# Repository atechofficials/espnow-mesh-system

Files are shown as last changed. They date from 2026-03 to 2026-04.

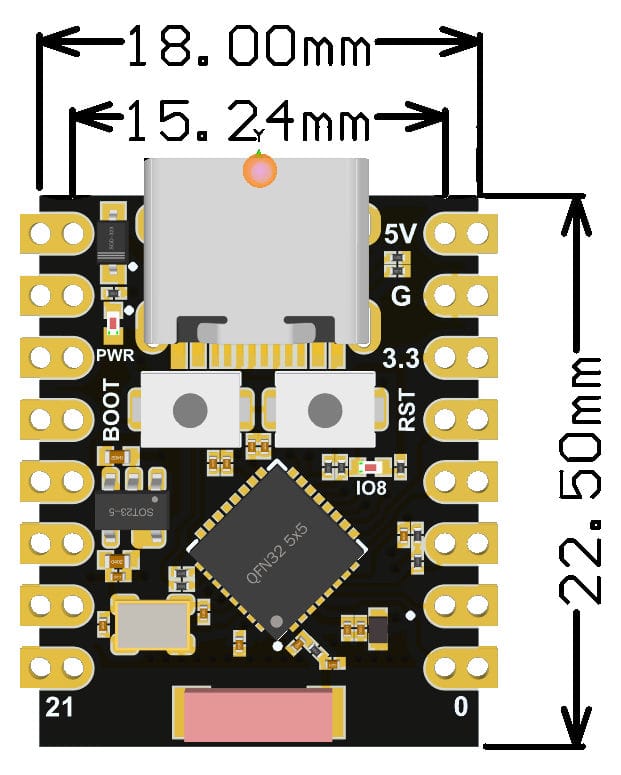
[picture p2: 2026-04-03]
esp32-gateway/gateway_v1/hardware/Development_Resources/esp32-c3/esp32_c3_supermini/ESP32-C3-SuperMini-Dim.jpg

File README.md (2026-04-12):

# ESPNow Mesh System

A local-first ESP32 smart-home system for **wireless sensing and control**.

This project lets you build a small home mesh using **ESP32-based nodes** and a central **ESP32-S3 gateway**.  
The gateway connects to your Wi-Fi, hosts a browser-based dashboard, can optionally expose its own built-in **SPI room sensor with runtime BMP280/BME280 auto-detection**, communicates with nearby nodes over **ESP-NOW**, can fall back to its own **Offline Mode AP** when your router is unavailable, optionally bridges the system to a local **MQTT broker**, publishes **Home Assistant MQTT auto-discovery**, and uses a companion **ESP32-C3 coprocessor** to handle **gateway-managed Node OTA updates** and future helper tasks.

That means you can:

- monitor room conditions like temperature, humidity, pressure, and light
- use the gateway by itself with an optional built-in room sensor before you add wireless nodes
- control actuator devices like relays from a web dashboard
- mirror supported devices and controls into Home Assistant through MQTT auto-discovery
- pair nodes without entering Wi-Fi credentials on each node
- keep everything running on your own local network

No cloud account. No subscription. No internet dependency for normal use.

---

## What This Project Can Do

### Live monitoring
Open the gateway's IP address in your browser to view live sensor readings from all paired nodes.

### Local control
Turn relays on and off directly from the dashboard.

### Easy pairing
Put a node into pairing mode and the gateway can discover and register it automatically. Fresh, unrenamed nodes now advertise with the last 4 characters of their MAC address appended to the default node name, making it easier to tell identical boards apart before you rename them from the dashboard. The current release line also tightens beacon/discovery timing so pairing candidates appear faster and stale "available to pair" entries clear sooner after a node powers down.

### Node settings from the browser
Change node settings such as:
- Status LED enable/disable
- Relay state persistence
- Sensor-specific options

### Gateway-managed Node OTA
Upload compatible sensor-node, actuator-node, or hybrid-node firmware from the gateway web interface and let the gateway update the selected node without connecting that node to your home Wi-Fi. The gateway now validates both the node role and the node hardware configuration ID before delivery begins.

### Offline gateway access
If your router is unavailable, the gateway can now switch to an **ESP32-S3-hosted Offline Mode AP** so the dashboard stays reachable without internet or home-network access. You can also choose manual offline mode during setup and edit the offline AP credentials later from the dashboard.

### MQTT and Home Assistant
If you enable MQTT in the gateway settings, the gateway publishes **Home Assistant MQTT discovery** for itself, its optional built-in sensor, and supported paired nodes. Relay controls, supported node settings, reboot/unpair actions, and gateway reboot/factory-reset actions can then be used from Home Assistant while staying synchronized with the gateway dashboard.

For temperature reporting, the gateway publishes MQTT temperatures in **degrees Celsius only** for both the built-in sensor and paired sensor nodes. Temperature-unit controls are intentionally **not** exposed to Home Assistant because Home Assistant already handles user-side Celsius/Fahrenheit conversion.

### Automatic recovery
If the gateway or node reboots, the system reconnects automatically and restores state where supported.

---

## Current Project Status

The project already supports **sensor nodes**, **actuator nodes**, and **hybrid nodes**.

### Available right now

| Type | Device | Status |
|---|---|---|
| Gateway | ESP32-S3 Gateway | Working |
| Gateway Helper | ESP32-C3 Coprocessor | Working |
| Sensor Node | Envo Mini v1 | Working |
| Actuator Node | ESP32 Relay Node v1 | Working |
| Hybrid Node | ESP32 Hybrid Relay Node v1 | Working |

### Current node capabilities

**Envo Mini v1**
- Temperature
- Atmospheric pressure
- Humidity
- Ambient light

**ESP32 Relay Node v1**
- 4 independent relay outputs
- Relay control from dashboard
- Relay state persistence across reboot
- Status LED setting from dashboard

**ESP32 Hybrid Relay Node v1**
- 4 independent relay outputs
- 4 TTP224 touch inputs
- RC522 RFID card reader support
- RFID card actions that apply saved relay scenes
- Relay control, state sync, and RFID management from the dashboard

### Current MQTT capabilities

- Local MQTT bridge from the gateway to a Mosquitto-compatible broker
- Home Assistant MQTT auto-discovery for:
  - the gateway device
  - optional gateway built-in sensor entities
  - supported sensor, actuator, and hybrid node entities
- Relay and supported setting control from Home Assistant with state sync back to the gateway dashboard
- Gateway reboot and gateway factory reset buttons exposed in Home Assistant
- Graceful retained-topic cleanup during gateway factory reset so the gateway and its connected nodes disappear from Home Assistant cleanly

### Current OTA capabilities

- Gateway self-OTA from the browser with gateway hardware-config ID validation
- Gateway-managed coprocessor OTA from the browser with board-specific coprocessor hardware-config ID validation and progress/error reporting
- Gateway-managed OTA for supported sensor nodes with role and hardware-config ID validation
- Gateway-managed OTA for supported actuator nodes with role and hardware-config ID validation
- Gateway OTA and Node OTA now coordinate helper ownership so the ESP32-C3 coprocessor cannot be reserved by conflicting update flows at the same time
- Gateway self-OTA, coprocessor OTA, and Node OTA remain available while the dashboard is being served through the Offline Mode AP

---

## Why ESP-NOW?

Most DIY smart-home systems put every device directly on Wi-Fi.

This project takes a different approach:

- the **gateway** joins your home Wi-Fi
- the **nodes** talk to the gateway using **ESP-NOW**
- nodes do not need your Wi-Fi password
- pairing is simpler for small embedded devices
- the system stays lightweight and local

This makes the setup especially useful for small ESP32 devices that only need to talk to one central controller.

---

## How It Works

```text
Browser
  |
  | Dashboard
  |
ESP32-S3 Gateway
  |
  | ESP-NOW
  |-- Sensor Nodes
  |-- Actuator Nodes
```

The gateway acts as the bridge between:
- your browser over Wi-Fi
- your MQTT broker / Home Assistant over Wi-Fi
- your ESP32 nodes over ESP-NOW

For **Node OTA**, the gateway temporarily hands firmware delivery to the on-board **ESP32-C3 coprocessor**, which stages the selected node firmware, starts a temporary helper access point, and serves the firmware image to the target node while the main gateway continues managing the mesh and dashboard. Incompatible uploads are blocked up front if the firmware markers do not match the selected node role or hardware configuration. While that helper session is active, the dashboard now blocks conflicting Gateway OTA or coprocessor OTA actions and shows a clear **Coprocessor Busy** state until the helper is free again.

If the gateway loses its router Wi-Fi connection, the **ESP32-S3** can now host an operator-facing Offline Mode AP directly while keeping ESP-NOW active on the last known mesh channel. When the router comes back, the gateway scans for the saved SSID, reconnects automatically, and returns the dashboard to the router-assigned IP.

---

## Hardware Used

### Gateway firmware targets
- ESP32-S3-DevKitC-1-N8R8 for bench development and validation
- Seeed Studio XIAO ESP32-S3 on the new THT gateway carrier variants
- Waveshare ESP32-S3-DevKit-C-N8R8 on the new THT gateway carrier variants

### Gateway helper targets
- ESP32-C3 Super Mini
- Seeed Studio XIAO ESP32-C3
- DFRobot Beetle ESP32-C3

### Gateway reference PCB variants

The current gateway hardware release line now consists of four single-layer, thick-trace, THT-friendly PCB variants intended to be easy to hand-fabricate at home:

| Variant | Main MCU board | Helper MCU board |
|---|---|---|
| `ESP32_Mesh_Gateway_v1A` | Seeed Studio XIAO ESP32-S3 | ESP32-C3 Super Mini |
| `ESP32_Mesh_Gateway_v1B` | Seeed Studio XIAO ESP32-S3 | Seeed Studio XIAO ESP32-C3 |
| `ESP32_Mesh_Gateway_v1C` | Seeed Studio XIAO ESP32-S3 | DFRobot Beetle ESP32-C3 |
| `ESP32_Mesh_Gateway_v1D` | Waveshare ESP32-S3-DevKit-C-N8R8 | ESP32-C3 Super Mini |

Shared board-level notes for all four variants:
- All four variants provide solder pads for an optional built-in **BMP280** or **BME280** gateway room sensor module, and the gateway auto-detects which one is attached at boot
- All four variants are intentionally kept on a single copper layer with thick traces for easier home fabrication
- The earlier ESP32-S3 Super Mini based gateway carrier should now be considered deprecated because that board's 4 MB flash is not suitable for the current gateway firmware line, which expects an 8 MB class ESP32-S3 target

### Sensor node reference boards
- DFRobot FireBeetle 2 ESP32-E
- ESP32-C3 Super Mini based **Envo Mini v1** prototype hardware

### Sensor node reference sensors
- BMP280
- DHT22
- TEMT6000

### Actuator node reference board
- ESP32 Dev Module

### Actuator node reference output
- 4-channel active-LOW relay module

### Hybrid node reference add-ons
- TTP224 4-way touch sensor
- RC522 RFID reader module

---

## Quick Start

Board and wiring selection for the current release line are handled through the documented **PlatformIO environments** for each firmware target, with guarded defaults and invalid-define correction in each project's `include/user_config.h`.

### 1. Flash the gateway
Start with the gateway firmware:

[`esp32-gateway/gateway_v1/README.md`](esp32-gateway/gateway_v1/README.md)

For **Node OTA** support, also flash the ESP32-C3 gateway coprocessor once from:

[`esp32-gateway/gateway_v1/coprocessor_esp32c3/`](esp32-gateway/gateway_v1/coprocessor_esp32c3/)

The **Gateway Firmware Update** section in the dashboard can now target either the ESP32-S3 **Main MCU** or the ESP32-C3 **Coprocessor**.

### 2. Flash a node
Choose one:

Sensor node:
[`esp32-nodes/sensor_nodes/envo_mini_v1/README.md`](esp32-nodes/sensor_nodes/envo_mini_v1/README.md)

Actuator node:
[`esp32-nodes/actuator_nodes/esp32_relay_node_v1/README.md`](esp32-nodes/actuator_nodes/esp32_relay_node_v1/README.md)

Hybrid node:
[`esp32-nodes/hybrid_nodes/esp32_hybrid_relay_node_v1/README.md`](esp32-nodes/hybrid_nodes/esp32_hybrid_relay_node_v1/README.md)

### 3. Power on the gateway
On first boot, the gateway opens the setup portal so you can either connect it to your home Wi-Fi or choose manual offline mode with the built-in Offline Mode AP credentials.

### 4. Pair a node
Put a node into pairing mode and let the gateway detect it.

### 5. Open the dashboard
Visit the gateway IP in your browser and start using the system. If the gateway is running in Offline Mode, open:

```text
http://192.168.8.1/
```

### 6. Optional: enable MQTT
If you want Home Assistant integration, open the gateway dashboard, go to the MQTT settings section, enter your broker details, and enable the MQTT bridge. The gateway will publish Home Assistant discovery automatically once it connects to the broker.

---

## Web Dashboard Features

The current dashboard supports:

- viewing all paired nodes
- seeing live sensor readings
- viewing the optional gateway built-in sensor separately from paired-node cards
- controlling relay outputs
- managing Hybrid-node RFID card actions
- opening node settings
- renaming nodes
- rebooting nodes remotely
- updating supported nodes with Node OTA
- updating the gateway main MCU or the ESP32-C3 coprocessor from the **Gateway Firmware Update** section
- disconnecting nodes
- changing gateway settings
- editing built-in gateway sensor temperature-unit / altitude settings when that feature is enabled
- configuring the MQTT bridge and Home Assistant discovery publishing
- editing Offline Mode AP settings and viewing current network mode / access IP
- launching Wi-Fi setup mode
- factory reset options, including a physical long-press reset button on the gateway and graceful node unpairing before the gateway wipes its own state

Home Assistant intentionally does **not** expose:
- relay label settings for actuator or hybrid nodes, because Home Assistant already lets users rename switches and buttons locally
- node or gateway temperature-unit settings, because MQTT temperatures are published in Celsius and Home Assistant handles conversion itself

The dashboard is served directly by the gateway itself.

---

## Who This Project Is For

This project is useful if you are:

### A maker or hobbyist
You want a local smart-home system without cloud dependency.

### A student or learner
You want to explore ESP32 networking, embedded firmware, and browser-based control panels.

### A developer
You want a modular ESP32 project with:
- gateway firmware
- sensor firmware
- actuator firmware
- hybrid node firmware
- a shared protocol
- a live dashboard
- room for future expansion

---

## For Developers

The project is already structured for further development.

If you want to:
- add new sensor nodes
- add new actuator nodes
- add new hybrid nodes
- improve the gateway
- improve the dashboard
- extend the protocol
- contribute fixes or new features

start here:

[`CONTRIBUTING.md`](CONTRIBUTING.md)

More detailed documentation is available in the subproject README files.

---

## Repository Layout

```text
espnow-mesh-system/
|-- README.md
|-- CONTRIBUTING.md
|-- esp32-gateway/
|-- esp32-nodes/
|-- docs/
```

### Main sections

- [`esp32-gateway/`](esp32-gateway/)  
  Gateway documentation and firmware
- [`esp32-gateway/gateway_v1/hardware/`](esp32-gateway/gateway_v1/hardware/)  
  Gateway v1A-v1D PCB resources, schematic PDFs, and development references

- [`esp32-nodes/`](esp32-nodes/)  
  Sensor, actuator, and hybrid node firmware

---

## Documentation Map

If you're just exploring:

- Gateway overview: [`esp32-gateway/README.md`](esp32-gateway/README.md)
- Nodes overview: [`esp32-nodes/README.md`](esp32-nodes/README.md)

If you're building hardware:

- Gateway firmware guide: [`esp32-gateway/gateway_v1/README.md`](esp32-gateway/gateway_v1/README.md)
- Gateway v1A-v1D PCB resources: [`esp32-gateway/gateway_v1/hardware/`](esp32-gateway/gateway_v1/hardware/)
- Sensor node guide: [`esp32-nodes/sensor_nodes/envo_mini_v1/README.md`](esp32-nodes/sensor_nodes/envo_mini_v1/README.md)
- Relay node guide: [`esp32-nodes/actuator_nodes/esp32_relay_node_v1/README.md`](esp32-nodes/actuator_nodes/esp32_relay_node_v1/README.md)
- Hybrid node guide: [`esp32-nodes/hybrid_nodes/esp32_hybrid_relay_node_v1/README.md`](esp32-nodes/hybrid_nodes/esp32_hybrid_relay_node_v1/README.md)
- ESP32-C3 Super Mini WiFi test report: [`docs/esp32_c3_supermini_wifi_tests/README.md`](docs/esp32_c3_supermini_wifi_tests/README.md)

If you're contributing code:

- Contribution guide: [`CONTRIBUTING.md`](CONTRIBUTING.md)

---

## Project Direction

The project currently supports:
- local sensor monitoring
- local relay control
- local RFID-driven relay scenes on Hybrid nodes
- browser-based node management
- gateway-managed Node OTA for supported sensor, actuator, and hybrid nodes with role and hardware-config safety checks
- board-specific configuration cleanup through the new `user_config.h` release line for gateway and node firmware
- ESP32-C3 Super Mini board support with board-gated WiFi transmit power limiting on node firmware where needed

Planned future growth may include:
- more sensor node types
- more actuator node types
- more hybrid sensor + actuator nodes
- improved dashboard views and charts
- cleaner onboarding and flashing experience

---

## License

MIT License

See [`LICENSE`](LICENSE)

---

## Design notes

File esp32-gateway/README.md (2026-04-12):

# ESP32 Gateway

The gateway is the heart of the ESPNow Mesh System. It runs on an **ESP32-S3** and bridges your Wi-Fi network with the ESP-NOW mesh while serving a live web dashboard, managing paired nodes, optionally exposing a built-in **SPI room sensor with runtime BMP280/BME280 auto-detection**, supporting a local **MQTT bridge** with **Home Assistant MQTT auto-discovery**, supporting **web-based gateway OTA firmware updates**, coordinating **gateway-managed Node OTA updates** for sensor, actuator, and hybrid nodes with a companion **ESP32-C3 coprocessor**, and providing an **Offline Mode AP** so the dashboard stays reachable even when your home router is unavailable.

---

## Hardware

| Item | Detail |
|---|---|
| Main Board | ESP32-S3-DevKitC-1-N8R8 |
| Companion Helper | ESP32-C3 coprocessor for Node OTA and future helper tasks |
| Flash | 8 MB (Quad) |
| PSRAM | 8 MB (Octal) |
| Status LED | WS2812B on GPIO 38 (on-board) |
| Factory reset button | Board-dependent and configured by `RESET_BTN_PIN` in `gateway_v1/include/user_config.h` |

The current gateway hardware release line now tracks four single-layer, thick-trace, THT-friendly PCB variants under `gateway_v1/hardware/`:

| Variant | Main MCU board | Helper MCU board |
|---|---|---|
| `ESP32_Mesh_Gateway_v1A` | Seeed Studio XIAO ESP32-S3 | ESP32-C3 Super Mini |
| `ESP32_Mesh_Gateway_v1B` | Seeed Studio XIAO ESP32-S3 | Seeed Studio XIAO ESP32-C3 |
| `ESP32_Mesh_Gateway_v1C` | Seeed Studio XIAO ESP32-S3 | DFRobot Beetle ESP32-C3 |
| `ESP32_Mesh_Gateway_v1D` | Waveshare ESP32-S3-DevKit-C-N8R8 | ESP32-C3 Super Mini |

All four variants include solder pads for an optional built-in **BMP280** or **BME280** gateway-side room sensor, and the gateway now auto-detects the attached sensor model at runtime. The older ESP32-S3 Super Mini based carrier should now be treated as deprecated because the current gateway firmware line expects an 8 MB class ESP32-S3 target.

---

## Responsibilities

- Connects to your home Wi-Fi using a captive portal (WiFiManager) on first boot or when reconfigured
- Can also run in an **ESP32-S3-hosted Offline Mode AP** with separate offline AP credentials
- Automatically falls back to the Offline Mode AP when the router Wi-Fi link is lost and returns to router mode when the saved router SSID is visible again
- Accepts ESP-NOW registrations from nodes and assigns them IDs
- Receives sensor data, heartbeats, and actuator states from paired nodes
- Optionally probes a gateway-side BMP280/BME280 room sensor over SPI, logs clearer detection diagnostics, auto-detects the sensor model at runtime, and exposes it as a dedicated dashboard card instead of a paired node
- Persists built-in sensor display settings such as temperature unit and altitude reference for sea-level pressure calculation
- Publishes optional MQTT discovery/state topics for the gateway, built-in sensor, and supported paired nodes
- Routes supported Home Assistant / MQTT commands back into the same gateway and node control flow used by the dashboard
- Publishes MQTT temperature data in degrees Celsius for Home Assistant and leaves unit conversion to Home Assistant itself
- Forwards dashboard commands to the correct node (pair, unpair, reboot, actuator toggle, settings change)
- Serves the web dashboard from LittleFS over HTTP/WebSocket
- Stores gateway configuration, web credentials, paired node records, node hardware-config IDs, and relay label assignments in NVS
- Supports **gateway self-OTA** from the web interface with validation, hardware-config ID checking, progress reporting, and automatic reboot
- Coordinates **Gateway OTA**, **coprocessor OTA**, and **Node OTA** so the ESP32-C3 helper cannot be reserved by conflicting update flows at the same time
- Keeps **gateway OTA**, **coprocessor OTA**, and **Node OTA** available while the gateway is serving the dashboard through Offline Mode
- Supports both dashboard-triggered and physical-button-triggered factory reset flows, including graceful node unpairing before reset, and LED feedback during the hold sequence
- Supports **Hybrid nodes** with capability-aware state handling, actuator-schema sync, RFID config sync, and RFID scan-event forwarding to the web UI

---

## LED Status Codes

| Colour / Pattern | Meaning |
|---|---|
| Solid white | Boot sequence in progress |
| Dim blue | Gateway operational |
| Green flash | Activity / success pulse |
| Orange flash | Node disconnect feedback |
| Dark-orange blink | Physical factory reset button is being held |
| Solid red | Factory reset hold threshold reached; reset is being confirmed |
| Off | Gateway LED disabled from the web UI |

The factory-reset LED sequence temporarily overrides the normal gateway LED owner and still appears even if the user has disabled the status LED from the web dashboard.

---

## Firmware Changelog

| Version | Notes |
|---|---|
| v1.6.0 | Added per-node dynamic settings, remote reboot support, gateway network config from dashboard, and factory reset support |
| v1.7.1 | Maintenance release with minor bug fixes |
| v1.8.0 | Added schema-driven sensor support, generic sensor reading protocol, and multi-sensor node compatibility |
| v1.8.1 | Added gateway status LED toggle support from the web UI with persistent state |
| v1.8.2 | Added ESP32 actuator-node support and improved actuator pairing/state/settings sync |
| v1.8.3 | Added per-relay label assignment from the web interface for relay nodes |
| v1.9.0 | Added **web-based gateway OTA firmware update**, OTA partition layout, upload validation, progress/error feedback, and automatic reboot after successful flash |
| v2.0.0 | Added **gateway-managed Node OTA** for supported sensor and actuator nodes, introduced the ESP32-C3 gateway coprocessor workflow, added helper-assisted node firmware staging/delivery, and extended OTA progress/reconnect tracking in the dashboard |
| v2.0.1 | Added OTA **hardware configuration ID** checks for both gateway OTA and node OTA, persisted node hardware IDs across gateway reboot, and improved OTA mismatch/error reporting in the serial logs and web UI |
| v2.1.0 | Added first-class **Hybrid node** support, introduced the RFID-enabled Hybrid Relay Node flow, added capability-aware actuator/RFID handling, and improved relay-state restore plus gateway OTA UI feedback after reboot |
| v2.1.1 | Improved the **web dashboard UX** with RFID scan toasts, mobile responsive layout fixes, custom reboot confirmation popup, better popup styling on small screens, overlay scroll-lock fixes, and improved UI asset refresh behavior |
| v2.1.2 | Added documentation/support for the **Gateway v1.0A** PCB release, aligned the gateway-helper UART mapping with the new PCB layout, and kept the gateway firmware line in sync with the latest hardware release |
| v2.1.3 | Added gateway-side max-node pairing-capacity enforcement, added dismissible dashboard feedback when pairing is attempted after the gateway is already full, and hardened node-registry restore so reduced `MESH_MAX_NODES` test builds fail safely instead of corrupting memory |
| v2.1.4 | Increased the shared node-name limit from 15 to 24 visible characters, updated gateway discovery/registry/rename handling for longer node names, added backward-compatible NVS restore support while saving new node records in the expanded-name format, and allowed fresh nodes to appear with MAC-suffixed default names for easier identification before manual rename |
| v2.2.0 | Polished gateway-side discovery timing so available nodes appear and expire more predictably, aligned the release docs with the new Gateway v1A-v1D PCB family, and documents the move toward `user_config.h` for user-facing firmware configuration |
| v2.3.1 | Hardened OTA coordination so Node OTA, Gateway OTA, and coprocessor OTA cannot fight over the ESP32-C3 helper, surfaced the shared **Coprocessor Busy** feedback across both gateway MCU targets, fixed a Node OTA helper-target regression, and auto-clears stale OTA panel state after backend cleanup |
| v2.4.0 | Added **Gateway Offline Mode** on the ESP32-S3 with manual setup-portal selection, automatic router-loss fallback, automatic router-return recovery, reconnect-safe dashboard notifications, runtime physical factory reset handling via the configurable `RESET_BTN_PIN`, and a dedicated factory-reset RGB LED sequence |
| v2.4.1 | Updates gateway factory reset so all currently paired nodes are sent a graceful unpair/disconnect command before the gateway wipes its own state, preventing nodes from treating factory reset like a temporary gateway reboot |
| v2.5.0 | Added optional gateway built-in BMP280/BME280 sensor support with dedicated dashboard/settings handling, and hardened ESP32-C3 Super Mini helper Wi-Fi behavior for more stable Node OTA AP sessions |
| v2.6.4 | Added MQTT bridging and Home Assistant MQTT auto-discovery, exposed gateway reboot/factory-reset controls in Home Assistant, kept supported sensor/actuator/hybrid node controls synchronized through MQTT, and clears retained MQTT discovery/state during gateway factory reset so the gateway and child devices disappear cleanly from Home Assistant |
| v2.6.7 | Improved built-in sensor probe and diagnosis logging, auto-detects whether the connected SPI module is BMP280 or BME280 at runtime, and removes the old manual built-in sensor type selection logic from the active gateway configuration path |

---

## Contents

```text
gateway_v1/
|-- src/
|   `-- main.cpp              <- gateway firmware
|-- include/
|   |-- mesh_protocol.h       <- shared protocol definitions (keep in sync with nodes)
|   `-- coproc_ota_protocol.h <- shared S3 <-> C3 OTA transport definitions
|-- coprocessor_esp32c3/      <- helper firmware used for Node OTA delivery
|-- data/                     <- LittleFS web assets (upload with --target uploadfs)
|   |-- index.html
|   |-- js/
|   |   `-- app.js
|   `-- css/
|       `-- style.css
|-- partitions_8mb_noot.csv   <- legacy no-OTA layout kept for reference
|-- partitions_8mb_ota.csv    <- active OTA-capable partition layout
|-- platformio.ini
`-- README.md
```

---

## Current Release Notes

- Gateway firmware version: **v2.6.7**
- Gateway coprocessor firmware version: **v0.3.1**
- Shared helper transport: `coproc_ota_protocol.h` **v1.1.0**
- Shared mesh protocol: `mesh_protocol.h` **v3.3.2**
- User configuration header: `user_config.h` **v1.1.3**
- Web UI assets:
  - `app.js` **v4.8.1**
  - `index.html` **v4.2.0**
  - `style.css` **v3.7.0**
- Active partition layout: **`partitions_8mb_ota.csv`**

### MQTT and Home Assistant notes

- MQTT is optional and is only active while the gateway is connected to a router
- Home Assistant MQTT discovery is published automatically once the gateway connects to the configured broker
- Gateway reboot and factory reset are exposed as Home Assistant MQTT button entities
- Relay label settings are intentionally not exposed through Home Assistant, because Home Assistant already supports local renaming of switches and buttons
- Gateway built-in sensor and paired sensor-node temperatures are published in Celsius only; Home Assistant handles Fahrenheit conversion if the user prefers that display unit

---

### Gateway build environments

The current `gateway_v1/platformio.ini` release line exposes explicit build environments for the documented hardware combinations:

- `gateway_v1a` - Seeed Studio XIAO ESP32-S3 + ESP32-C3 Super Mini
- `gateway_v1b` - Seeed Studio XIAO ESP32-S3 + Seeed Studio XIAO ESP32-C3
- `gateway_v1c` - Seeed Studio XIAO ESP32-S3 + DFRobot Beetle ESP32-C3
- `gateway_v1d` - Waveshare ESP32-S3-DevKit-C-N8R8 + ESP32-C3 Super Mini
- `development` - custom ESP32-S3-DevKitC-1-N8R8 + DFRobot Beetle ESP32-C3 validation combo

See [gateway_v1/README.md](gateway_v1/README.md) for build, flashing, gateway OTA, Node OTA, coprocessor setup, and configuration details.

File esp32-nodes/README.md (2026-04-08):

# ESP32 Nodes

This directory contains firmware for all node types in the ESPNow Mesh System. Nodes communicate over **ESP-NOW** for normal mesh operation and do not need your home Wi-Fi credentials.

During **gateway-managed Node OTA**, the selected node temporarily connects to the helper AP created by the gateway's ESP32-C3 coprocessor, downloads its staged firmware image, flashes it, and then returns to normal ESP-NOW operation after reboot.

---

## Node Types

### Sensor Nodes (`sensor_nodes/`)

Sensor nodes periodically read one or more physical sensors and transmit the data to the gateway. Each node self-describes its sensors to the gateway via a schema handshake at pair time, defining labels, units, and precision for every measurement. The gateway and web dashboard adapt automatically, so adding sensors to a node requires only node firmware changes.

Currently implemented:

| Node | Sensors | Firmware |
|---|---|---|
| Envo Mini V1 Node | Bosch BMP280 (temperature + pressure) + DHT22 (humidity) + TEMT6000 (ambient light) | v2.2.0 |

### Actuator Nodes (`actuator_nodes/`)

Actuator nodes receive relay-toggle commands from the gateway and report their current state back.

Currently implemented:

| Node | Actuator | Firmware |
|---|---|---|
| ESP32 Relay Node v1 | 4 relays + 4 touch inputs | v1.3.1 |

### Hybrid Nodes (`hybrid_nodes/`)

Hybrid nodes combine more than one capability family in the same firmware image. The first implementation keeps the familiar 4-relay actuator workflow while adding RFID-driven relay scenes over an RC522 reader. The gateway and dashboard now treat these nodes as first-class `NODE_HYBRID` devices instead of forcing them into a sensor-only or actuator-only bucket.

Currently implemented:

| Node | Capabilities | Firmware |
|---|---|---|
| ESP32 Hybrid Relay Node v1 | 4 relays + 4 touch inputs + RC522 RFID card actions | v0.3.2 |

---

## How Pairing Works

Every node ships unpaired. To add a node to the mesh:

1. Power on the gateway (must be online and connected to Wi-Fi)
2. Hold the **pairing button** on the node for **3 seconds**; the node enters pairing mode and broadcasts beacon packets on channels 1-13
3. The gateway detects the beacon, displays the node in the **"Available Nodes"** section of the dashboard, and initiates the handshake automatically
4. Within a few seconds the node appears as **Online** in the Connected Nodes table

Pairing data (gateway MAC, channel, assigned node ID) is saved to NVS on the node and survives power cycles. Fresh, unrenamed nodes also advertise with the last 4 characters of their MAC address appended to the default node name so matching identical boards in the dashboard is easier before manual rename.

---

## How Re-registration Works

If the gateway reboots or loses power, nodes detect the absence of acknowledgements and automatically re-send their registration message. The gateway reassigns the same ID (if the node was previously known) and the mesh reassembles without any user intervention.

Current node firmwares also re-report their `HW_CONFIG_ID` during registration and re-registration so the gateway can keep hardware-aware OTA checks available even after restarts.

---

## Gateway-Managed Node OTA

Supported node firmwares can now be updated from the **gateway web interface**.

During Node OTA:

1. the gateway validates the uploaded node `firmware.bin`
2. the ESP32-C3 helper stages that image and starts a temporary OTA AP
3. the selected node joins the helper AP, downloads the image, flashes it, and reboots
4. the node re-registers to the gateway with its existing node ID

This flow has now been validated with:

- sensor-node OTA
- relay-node OTA
- hybrid-node OTA
- version upgrades
- version downgrades
- same-version reflashing
- role mismatch rejection
- hardware-config mismatch rejection

The current Hybrid-node line also includes improved RC522 runtime recovery so RFID scanning can recover from reader stalls without requiring a full node reboot.

The newer release line also:

- moves user-tunable firmware definitions into `user_config.h` for cleaner scaling across gateway and node projects
- applies a board-gated `WiFi.setTxPower(WIFI_POWER_8_5dBm)` limit only on ESP32-C3 Super Mini node builds, and only after Wi-Fi startup has completed
- includes a dedicated ESP32-C3 Super Mini WiFi characterization report at `../docs/esp32_c3_supermini_wifi_tests/README.md`
- keeps actuator and hybrid-node heartbeat/liveness handling more stable so online status, settings updates, and control round-trips feel snappier with the gateway

## MQTT and Home Assistant Through the Gateway

Nodes do not talk to MQTT directly. The **gateway** is the MQTT bridge.

When MQTT is enabled on the gateway:

- supported sensor, actuator, and hybrid nodes are published into Home Assistant through MQTT auto-discovery
- node state stays synchronized between Home Assistant and the gateway dashboard
- actuator and hybrid relay label settings are intentionally not exposed in Home Assistant, because Home Assistant already lets users rename switches/buttons locally
- sensor temperature values are published in **degrees Celsius** by the gateway, and Home Assistant handles Celsius/Fahrenheit conversion itself

---

## LED Status Codes (all node types)

| Colour / Pattern | Meaning |
|---|---|
| Fast white flash | Booting |
| Slow cyan pulse | Pairing mode; beaconing |
| Solid green | Paired and transmitting normally |
| Amber slow pulse | Gateway lost; attempting re-registration |
| Off | Status LED disabled via settings |

Pairing-state LEDs (cyan, booting) are always shown regardless of the LED-enable setting.

---

## Shared Protocol

All nodes share `include/mesh_protocol.h` with the gateway. **Keep this file identical** across both projects; a version mismatch will cause silent communication failures.

See the [mesh protocol header](../esp32-gateway/gateway_v1/include/mesh_protocol.h) for the full binary frame layout and message type definitions.

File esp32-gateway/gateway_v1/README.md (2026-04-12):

# Gateway v1 - Build, Flash, and OTA Guide

Firmware version: **2.6.7**  
Target board: `esp32-s3-devkitc1-n8r8`

Gateway helper coprocessor: **ESP32-C3 firmware v0.3.1**

---

## Highlights in v2.6.7
- Adds clearer built-in sensor probe and diagnosis logging in the gateway serial output
- Auto-detects whether the connected built-in SPI sensor is **BMP280** or **BME280** at runtime and shows data accordingly
- Removes the old manual built-in sensor type selection logic and keeps only a simple built-in sensor enable flag

## Highlights in v2.6.4
- Adds an optional **MQTT bridge** from the gateway to a local broker using `PubSubClient`
- Adds **Home Assistant MQTT auto-discovery** for the gateway, optional gateway built-in sensor, and supported paired sensor/actuator/hybrid nodes
- Keeps supported controls synchronized between Home Assistant and the gateway dashboard
- Exposes **Gateway Reboot** and **Gateway Factory Reset** as Home Assistant MQTT buttons
- Clears retained MQTT discovery/state topics during gateway factory reset so the gateway and its connected nodes disappear cleanly from Home Assistant
- Keeps MQTT temperature publishing in **degrees Celsius only** and intentionally leaves temperature-unit conversion to Home Assistant

## Highlights in v2.5.0
- Adds optional gateway built-in **BMP280/BME280** sensor support on the dedicated gateway PCB header/pads
- Adds a dedicated **Gateway Built-in Sensor** dashboard card plus Settings-page controls for temperature unit and altitude reference
- Keeps the built-in sensor separate from paired-node management and shows a clear Sensor not detected state when the feature is enabled but the hardware is missing or faulty
- Keeps the optional built-in sensor feature board-gated while moving BMP280/BME280 model selection to runtime auto-detection in the newer release line
- Hardens **ESP32-C3 Super Mini** helper AP behavior for Node OTA by applying the documented **8.5 dBm** Wi-Fi TX power cap after Wi-Fi startup and preserving helper-side Wi-Fi stability safeguards
- Refines gateway-side Node OTA status wording so accepted OTA requests report that the gateway is waiting for the node to connect to the helper AP

## Highlights in v2.4.1
- Updates the gateway factory reset flow so all currently paired nodes receive an explicit `UNPAIR_CMD` before the gateway wipes its own state
- Applies this graceful node disconnect behavior to both reset entry points:
  - dashboard **Factory Reset**
  - physical reset button hold sequence
- Prevents previously paired nodes from treating gateway factory reset like a temporary gateway reboot
- Leaves nodes in their expected unpaired / pairing-ready state after factory reset so they can be paired again cleanly
- Uses each node's actual node type in the unpair command path instead of stamping every unpair as `NODE_SENSOR`

## Highlights in v2.4.0
- Adds **Gateway Offline Mode** hosted directly on the ESP32-S3 so the dashboard remains reachable even when the home router is unavailable
- Adds setup-portal controls for choosing **manual Offline Mode** and editing the dedicated Offline Mode AP credentials
- Automatically falls back from router STA mode to the Offline Mode AP when the saved router link is lost
- Automatically scans for the saved router SSID and returns from Offline Mode back to normal router STA mode when that network comes back
- Keeps **Gateway OTA**, **Coprocessor OTA**, and **Node OTA** functional while the gateway is being accessed through the Offline Mode AP
- Adds reconnect-aware dashboard notifications so users are told when the gateway loses the router, switches to Offline Mode, and later returns to router mode
- Adds a runtime **physical factory reset** flow using the board-specific `RESET_BTN_PIN` from `include/user_config.h` instead of relying only on the dashboard action
- Adds a dedicated RGB LED reset sequence for physical factory reset:
  - blinking dark orange while the button is being held
  - solid red once the reset hold threshold is reached
- Increases the physical reset hold time to **6 seconds** for clearer visual confirmation

## Highlights in v2.3.1
- Hardens OTA coordination so **Node OTA**, **Gateway OTA**, and **coprocessor OTA** cannot reserve the ESP32-C3 helper at the same time
- Shows **Coprocessor Busy. Please try after some time.** across the dashboard when the helper is already occupied, including both **Main MCU** and **Coprocessor** targets in the **Gateway Firmware Update** section
- Fixes the Node OTA helper upload-begin target so staged node firmware reaches the coprocessor helper correctly again
- Clears stale Node OTA and coprocessor OTA panel state automatically after backend cleanup so the dashboard returns to idle cleanly

## Highlights in v2.3.0
- Adds **ESP32-C3 coprocessor OTA** support through the **Gateway Firmware Update** section in the web dashboard
- Adds a target selector in the dashboard so the **Gateway Firmware Update** flow can address either the ESP32-S3 **Main MCU** or the ESP32-C3 **Coprocessor**
- Adds board-specific coprocessor firmware validation using the helper board hardware-config ID before UART OTA transfer begins
- Improves OTA error reporting so firmware mismatch messages include the uploaded hardware-config ID clearly in both the serial logs and the web UI
- Adds explicit PlatformIO build environments for the documented gateway hardware combinations and the current custom development combo

## Highlights in v2.2.0
- Polishes discovery timing on both the gateway and node side so pairing candidates appear faster and stale entries clear sooner
- Introduces the `user_config.h` configuration split for cleaner user-tunable firmware definitions
- Documents the current gateway hardware release line around four valid THT-friendly PCB variants (`v1A` to `v1D`)
- Keeps the ESP32-C3 helper workflow aligned with the newer `v0.3.1` coprocessor firmware line

## Highlights in v2.1.4
- Increased the shared node-name field from 16 bytes to 25 bytes (24 visible characters + NUL) for beacon and registration messages, enabling clearer default node names, MAC-suffixed first-boot node names, and longer user-defined names while remaining well within ESP-NOW payload limits

## Highlights in v2.1.3

- Adds a gateway-side **max node capacity** check before a new pairing flow is started
- Shows a dismissible dashboard popup when the user tries to connect another node after the gateway is already full
- Re-shows the capacity warning on repeated over-limit pairing attempts instead of silently failing
- Hardens gateway node-registry restore so temporary low-`MESH_MAX_NODES` test builds do not corrupt runtime memory on boot
- Continues support for the current **ESP32-C3 gateway coprocessor**, Hybrid-node handling, RFID dashboard flow, gateway OTA, and gateway-managed Node OTA

## Highlights in v2.1.2

- Adds the first **ESP32 Mesh System Gateway v1.0A** hardware release to the repository under `hardware/`
- Documents a home-fabrication-friendly gateway PCB built around off-the-shelf **ESP32-S3 Super Mini** and **ESP32-C3 Super Mini** development boards
- Aligns the documented ESP32-S3 <-> ESP32-C3 UART wiring with the new PCB layout:
  - **ESP32-S3 TX GPIO4 -> ESP32-C3 RX GPIO0**
  - **ESP32-S3 RX GPIO5 -> ESP32-C3 TX GPIO1**
- Continues the current gateway OTA, Node OTA, Hybrid-node, and mobile-web-UI feature set from the v2.1.1 release line

## Highlights in v2.1.1

- Continues the **gateway-managed Node OTA** workflow for supported sensor, actuator, and hybrid nodes
- Continues first-class **Hybrid node** handling with capability-aware actuator/RFID synchronization
- Continues support for the **ESP32 Hybrid Relay Node v1** and its RFID card-action workflow in the dashboard
- Adds RFID scan toasts in the dashboard for **new card detection** and **known card action execution**
- Improves the **mobile web UI** with better top-bar responsiveness, mobile sidebar gateway actions, and improved side-nav behavior in portrait and landscape orientations
- Replaces the browser reboot confirmation with a custom **Reboot Gateway** popup consistent with the Factory Reset flow
- Improves popup styling, warning-icon visibility, small-screen landscape fit, and background scroll locking for side menus and dialogs
- Preserves actuator state across gateway reboot so relay cards recover correctly after restart
- Improves gateway OTA success/reboot feedback in the web interface
- Continues support for the **ESP32-C3 gateway coprocessor**, `coproc_ota_protocol.h`, gateway web credentials, relay label assignment, gateway LED control, and schema-driven node settings

---

## Prerequisites

- [PlatformIO Core](https://docs.platformio.org/en/latest/core/installation/index.html) or the PlatformIO IDE extension for VS Code
- USB cable connected to the selected ESP32-S3 gateway main board
- USB cable connected to the selected ESP32-C3 coprocessor board when flashing or debugging the helper firmware

The current hardware release line in `hardware/` instead targets four single-layer carrier-PCB variants built around off-the-shelf ESP32-S3 and ESP32-C3 development boards.

---

## Gateway Hardware Release Line

The current gateway PCB release line documents four valid single-layer, thick-trace, home-fabrication-friendly variants:

| Variant | Main MCU board | Helper MCU board |
|---|---|---|
| `ESP32_Mesh_Gateway_v1A` | Seeed Studio XIAO ESP32-S3 | ESP32-C3 Super Mini |
| `ESP32_Mesh_Gateway_v1B` | Seeed Studio XIAO ESP32-S3 | Seeed Studio XIAO ESP32-C3 |
| `ESP32_Mesh_Gateway_v1C` | Seeed Studio XIAO ESP32-S3 | DFRobot Beetle ESP32-C3 |
| `ESP32_Mesh_Gateway_v1D` | Waveshare ESP32-S3-DevKit-C-N8R8 | ESP32-C3 Super Mini |

Shared board-level notes:

- all four variants keep solder pads for an optional **BMP280** or **BME280** gateway-side built-in sensor module
- all four variants are intentionally laid out on a single copper layer with thick traces for easier home fabrication
- the earlier ESP32-S3 Super Mini based gateway carrier should now be treated as deprecated because that board only has 4 MB flash and is not suitable for the current gateway firmware line

The same `hardware/` tree also includes schematic PDFs and a `Development_Resources/` folder with dev-board pinouts and MCU reference documents.

---

## PlatformIO Build Environments

The gateway release line now exposes explicit build environments in `platformio.ini` so users can build the correct firmware for each documented hardware combination without editing board macros manually.

| Environment | Main MCU board | Coprocessor board |
|---|---|---|
| `gateway_v1a` | Seeed Studio XIAO ESP32-S3 | ESP32-C3 Super Mini |
| `gateway_v1b` | Seeed Studio XIAO ESP32-S3 | Seeed Studio XIAO ESP32-C3 |
| `gateway_v1c` | Seeed Studio XIAO ESP32-S3 | DFRobot Beetle ESP32-C3 |
| `gateway_v1d` | Waveshare ESP32-S3-DevKit-C-N8R8 | ESP32-C3 Super Mini |
| `development` | Espressif ESP32-S3-DevKitC-1-N8R8 | DFRobot Beetle ESP32-C3 |

When building or uploading from USB, select the environment that matches the actual gateway hardware pair you are using.

The current release line keeps the optional gateway built-in sensor feature behind `GATEWAY_BUILTIN_SENSOR_ENABLED`, and the firmware auto-detects whether the attached SPI module is BMP280 or BME280 at runtime.

The newer release line also keeps board and helper selection in PlatformIO build environments while `include/user_config.h` provides guarded defaults and invalid-define correction when no explicit board combination is selected.
## Dependencies

Managed automatically by PlatformIO via `platformio.ini`:

| Library | Version |
|---|---|
| WiFiManager | 2.0.17 |
| ESPAsyncWebServer | 3.6.0 |
| AsyncTCP | 3.3.2 |
| ArduinoJson | 7.4.3 |
| Adafruit NeoPixel | 1.15.4 |
| Adafruit Unified Sensor | 1.1.15 |
| Adafruit BMP280 Library | 2.6.8 |
| Adafruit BME280 Library | 2.3.0 |
| PubSubClient | 2.8 |

Framework libraries used directly (no extra install needed): `LittleFS`, `Preferences`, `WiFi`, `esp_now`, `Update`.

---

## Partition Layout

The project now builds against **`partitions_8mb_ota.csv`**.

| Partition | Size |
|---|---|
| `nvs` | 20 KB |
| `otadata` | 8 KB |
| `app0` | 1792 KB |
| `app1` | 1792 KB |
| `LittleFS` | 4544 KB |
| `coredump` | 64 KB |

This layout is required for the web-based Gateway OTA update feature and leaves the gateway firmware on an OTA-capable base while the ESP32-C3 helper handles node-firmware delivery.

---

## First-Time Flash / Migration to the OTA-Capable Gateway Line

If you are coming from an older gateway build that used the non-OTA partition table, the **first upgrade to the current OTA-capable gateway line must be done over USB**.

Run these commands from the `gateway_v1/` directory:

```bash
# 1. Erase flash for a clean migration
pio run --target erase

# 2. Upload the LittleFS web assets
pio run --target uploadfs

# 3. Compile and upload the firmware
pio run --target upload
```

After this migration, future **gateway firmware** updates can be done from the web interface.

To use **Node OTA**, also flash the ESP32-C3 helper once from the `coprocessor_esp32c3/` directory:

```bash
cd coprocessor_esp32c3
pio run --target erase
pio run --target upload
pio device monitor
```

See [coprocessor_esp32c3/README.md](coprocessor_esp32c3/README.md) for the helper-specific hardware, transport, and runtime details.

If you change only the dashboard assets later, run:

```bash
pio run --target uploadfs
```

If you change only the firmware later and want to use USB instead of OTA, run:

```bash
pio run --target upload
```

---

## ESP32-C3 Gateway Coprocessor

The Node OTA workflow uses a dedicated **ESP32-C3 coprocessor** connected to the ESP32-S3 gateway.

During a node update, the gateway:

1. validates and stages the uploaded node `firmware.bin`
2. transfers that firmware to the ESP32-C3 helper over UART
3. tells the helper to start a temporary OTA access point
4. instructs the selected node to join that helper AP
5. waits for the node to download, flash, reboot, and re-register

The coprocessor also reports OTA helper status back to the gateway so the web interface can show live progress.

The exact UART routing depends on the selected gateway PCB variant and helper dev board. Keep the helper UART definitions in sync with the intended hardware pair and document any board-specific differences in the hardware release notes when they change.

Shared transport definitions between the gateway and helper live in:

- `include/coproc_ota_protocol.h`
- `coprocessor_esp32c3/include/coproc_ota_protocol.h`

Keep those copies synchronized.

---

## First Boot

1. The gateway tries to reconnect to saved Wi-Fi credentials automatically
2. If no router credentials are stored, WiFiManager opens the setup portal AP:
   - SSID: **`ESP32-Mesh-Gateway`**
   - Password: **`meshsetup`**
3. Connect to that AP from a phone or laptop
4. Open the captive portal and either:
   - select and save your home Wi-Fi network, or
   - enable **Manual Offline Mode** so the gateway boots directly into its dedicated Offline Mode AP
5. After connection to your router, the dashboard becomes available at:

```text
http://<gateway-ip>/
```

6. If the gateway is running in Offline Mode instead, the dashboard becomes available at:

```text
http://192.168.8.1/
```

Wi-Fi credentials, gateway settings, and paired-node records are stored in NVS and survive reboot.

---

## Gateway Offline Mode

The current gateway release line supports a dedicated **Offline Mode AP** hosted on the ESP32-S3 main MCU.

This mode is intended for cases where:

- the gateway has not been given router credentials yet
- the user explicitly enables **Manual Offline Mode** from the setup portal
- the saved home router disappears and the gateway must remain reachable locally

### Offline Mode behavior

- the gateway starts the dedicated Offline Mode AP with its own SSID/password
- the dashboard is served from **`http://192.168.8.1/`**
- paired nodes stay available over ESP-NOW on the last active mesh channel
- the gateway keeps retrying for the saved router SSID in the background
- once the saved router becomes visible again, the gateway automatically returns to normal online router mode

### Configuration

- Offline Mode AP credentials can be changed from the setup portal and later from the dashboard
- setup-portal credentials and Offline Mode AP credentials are stored separately
- router credentials are also mirrored into gateway config storage so reconnect and failover behavior remains reliable across reboot

---

## Gateway Built-in Sensor

The current gateway release line can optionally expose a gateway-side **BMP280** or **BME280** module soldered to the built-in sensor pads on the PCB.

### Configuration

- the built-in sensor feature is enabled or disabled with `GATEWAY_BUILTIN_SENSOR_ENABLED`
- when enabled, the gateway probes the attached SPI module at boot and auto-detects whether it is a BMP280 or BME280
- the gateway reuses the board-specific SPI pin mapping defined in `user_config.h` and prints clearer serial probe diagnostics when detection succeeds or fails

### Dashboard and Settings behavior

- the dashboard shows a dedicated **Gateway Built-in Sensor** card instead of treating the sensor like a paired node
- temperature and sea-level-corrected pressure are shown for both detected BMP280 and BME280 modules
- the built-in sensor status badge reflects the detected model (`BMP280` or `BME280`)
- humidity is shown only when the detected module is BME280
- the Settings page exposes temperature-unit and altitude-reference controls for the built-in sensor
- if the feature is enabled in firmware but the module is missing or faulty, the dashboard and Settings page remain visible and report **Sensor not detected**
- the MQTT / Home Assistant bridge publishes gateway built-in temperature in **degrees Celsius only** and does not expose the built-in sensor temperature-unit setting, because Home Assistant already handles unit conversion on its own side

---

## MQTT and Home Assistant Integration

The current gateway release line can optionally bridge the local ESP-NOW system into a Mosquitto-compatible MQTT broker.

When MQTT is enabled from the dashboard:

- the gateway publishes Home Assistant MQTT discovery automatically
- the gateway itself appears as a Home Assistant device
- supported paired nodes appear under the same gateway-managed device hierarchy
- relay controls, supported node settings, reboot actions, and unpair actions can be triggered from Home Assistant
- gateway reboot and factory reset can also be triggered from Home Assistant

Intentional Home Assistant behavior:

- relay label settings are **not** exposed, because Home Assistant already lets users rename switches/buttons locally
- temperature-unit settings are **not** exposed for the gateway built-in sensor or paired sensor nodes
- MQTT temperatures are published in **degrees Celsius** only, and Home Assistant handles conversion to Fahrenheit if the user selects that display unit

During gateway factory reset, the firmware now clears retained MQTT discovery/state topics before rebooting so the gateway and its connected nodes disappear from Home Assistant cleanly instead of leaving stale devices behind.

---

## Gateway OTA Update from the Web Interface

Once an OTA-capable gateway build is already installed, the gateway can update its **own firmware** directly from the dashboard.

This flow remains available when the dashboard is being served either from the normal router connection or from the ESP32-S3 Offline Mode AP.

### Steps

1. Build a new gateway firmware binary:

```bash
pio run
```

2. Open the dashboard in a browser
3. Go to **Settings -> Gateway Firmware Update**
4. Select the new `firmware.bin`
5. Click **Upload Gateway Firmware**
6. Confirm the update when prompted

The **Gateway Firmware Update** panel now includes a target selector with **Main MCU** and **Coprocessor** options. The steps in this section cover the ESP32-S3 main-firmware path.
### What the gateway does

- validates the uploaded image
- validates the uploaded gateway hardware configuration marker (`GWHWCFG`)
- checks OTA slot size and image type
- flashes the inactive OTA slot
- reports progress/errors in the web UI
- reboots into the new firmware automatically on success

### Notes

- Upload **`firmware.bin`**, not `bootloader.bin`, not `partitions.bin`
- If the web UI assets were changed, also upload LittleFS via `pio run --target uploadfs`
- The current release line moves user-facing configuration definitions into `user_config.h`; older checkouts may still have some of the same knobs in `src/main.cpp`

---

## Gateway Coprocessor OTA Update from the Web Interface

The same **Gateway Firmware Update** panel can now also update the attached **ESP32-C3 coprocessor** from the browser.

This flow also remains available while the gateway is operating in Offline Mode.

### Steps

1. Build the matching coprocessor helper firmware binary from `coprocessor_esp32c3/` using the correct environment for your helper board
2. Open the dashboard in a browser
3. Go to **Settings -> Gateway Firmware Update**
4. Select **Coprocessor** from the MCU target dropdown
5. Select the helper `firmware.bin`
6. Click **Upload Gateway Firmware**

### What the gateway does

- validates the uploaded ESP32 application image
- validates the uploaded coprocessor hardware-config marker against the expected helper board type
- checks that the image fits in the coprocessor OTA slot
- stages the firmware in LittleFS
- asks the helper to halt normal work and prepare for self-OTA
- transfers the firmware to the ESP32-C3 over UART
- waits for the helper to flash, reboot, and reconnect
- reports progress and errors back to the web UI

### Notes

- Upload the helper `firmware.bin` from the environment matching your helper board: `beetle_esp32c3`, `xiao_esp32c3`, or `esp32c3_sm`
- Wrong-board helper uploads are rejected before UART transfer begins
- If the ESP32-C3 is already serving as the Node OTA helper, the **Gateway Firmware Update** section now blocks both MCU targets and shows a shared **Coprocessor Busy** message until the helper is released
## Node OTA Update from the Web Interface

The gateway can also update a paired **sensor node**, **actuator node**, or **hybrid node** from the dashboard.

This flow remains available in both normal router mode and the ESP32-S3 Offline Mode AP.

### Supported flow

1. Build the target node firmware and locate its `firmware.bin`
2. Open the dashboard in a browser
3. Go to the **Node OTA Update** section
4. Select the target node and upload the matching node `firmware.bin`
5. Wait for the gateway to stage the file, arm the ESP32-C3 helper, and start the temporary helper AP
6. The target node downloads the staged image, flashes it, reboots, and re-registers automatically

### What the gateway checks

- uploaded image role matches the selected node type (`SENSOR`, `ACTUATOR`, or `HYBRID`)
- uploaded node hardware configuration marker matches the selected node's reported `HW_CONFIG_ID`
- firmware metadata is readable before starting delivery
- helper staging finishes successfully on the ESP32-C3
- the node accepts OTA mode and reconnects after reboot

### Notes

- Upload **node `firmware.bin`** from the node project, not bootloader or partition files
- The node does **not** need your home Wi-Fi credentials; it only joins the temporary helper AP for the OTA window
- If the coprocessor is already busy with a helper self-update, the **Node OTA Update** section disables its controls and shows the shared **Coprocessor Busy** message until the helper is available again
- Supported and verified flows now include same-version reflashing, upgrades, downgrades, sensor-node OTA, relay-node OTA, hybrid-node OTA, and node OTA after gateway reboot

---

## Updating the Setup Portal AP Credentials

The WiFiManager setup-portal SSID and password can be changed from the dashboard without reflashing:

1. Open **Settings -> Gateway Network**
2. Edit the setup AP SSID and/or password
3. Click **Save AP Config**

These values are used the next time the gateway has to open the setup portal.

---

## Web Interface Access Control

The dashboard can be left open or protected with username/password credentials from the web interface.

### Stored in NVS

- web username
- password hash
- remember token

If credentials are forgotten, recover access by performing a **factory reset**.

---

## Factory Reset

Hold the dedicated **physical factory reset button** connected to the currently selected `RESET_BTN_PIN` in `include/user_config.h` for **6 seconds** while the gateway is running, or trigger **Factory Reset** from the dashboard.

The exact MCU pin is **board-dependent** and may differ between gateway hardware variants and build environments, so do not assume a universal reset-button pin across all gateway boards.

During a physical reset hold, the gateway RGB LED shows:

- **blinking dark orange** while the reset hold is in progress
- **solid red** once the hold threshold has been reached and reset is about to trigger

If the button is released early, the reset is canceled and LED ownership returns to the previous runtime state.

The physical reset LED sequence is always shown, even if the user has disabled the normal Gateway Status LED from the dashboard.

Before the gateway wipes its own registry and saved credentials, it now sends a graceful unpair/disconnect command to every currently paired node. This allows those nodes to clear their saved gateway binding and return to pairing mode instead of briefly behaving as though the gateway only rebooted temporarily.

This clears:

- saved Wi-Fi / router credentials
- custom setup AP credentials
- custom Offline Mode AP credentials
- web interface credentials
- paired node registry
- saved relay label assignments

The gateway then reboots and returns to setup mode.

---

## Key Configuration (`include/user_config.h`)

The current release line keeps board selection, pin definitions, and user-facing firmware defaults in `include/user_config.h` so `main.cpp` can stay focused on runtime logic. Older checkouts may still keep some of the same constants in `src/main.cpp`.

The newer `v2.4.1` line also keeps the setup-portal defaults, Offline Mode defaults, board-specific reset-button wiring through `RESET_BTN_PIN`, and gateway LED ownership behavior aligned through `user_config.h`.

| Constant | Default | Description |
|---|---|---|
| `AP_SSID_DEFAULT` | `"ESP32-Mesh-Gateway"` | WiFiManager setup portal SSID |
| `AP_PASS_DEFAULT` | `"meshsetup"` | WiFiManager setup portal password |
| `WEB_PORT` | `80` | HTTP/WebSocket port |
| `WS_UPDATE_MS` | `2000` | Node/discovery push interval to browser |
| `WS_META_MS` | `10000` | Gateway meta push interval to browser |
| `RX_QUEUE_SIZE` | `30` | Incoming ESP-NOW packet queue depth |
| `GW_LED_PIN` | `38` | On-board WS2812B gateway status LED |

Timing constants shared with the nodes live in `include/mesh_protocol.h`.

Node OTA transport and helper constants are shared with the ESP32-C3 helper through `include/coproc_ota_protocol.h`.

Use `user_config.h` for board-specific pin mappings, helper UART routing, and other user-tunable firmware selections in the newer release line.

If you are working against one of the gateway PCB variants instead of the original dev-kit wiring, keep the UART pin assignments and helper-board assumptions aligned with the specific hardware variant you are building.

---

## Serial Monitor

```bash
pio device monitor
```

Default baud rate: **115200**

Useful log prefixes:

| Prefix | Meaning |
|---|---|
| `[BOOT]` | Startup sequence |
| `[FS]` | LittleFS mount / file listing |
| `[WiFi]` | Wi-Fi connection events |
| `[ESP-NOW]` | ESP-NOW init and TX callbacks |
| `[DISC]` | Node discovery |
| `[PAIR]` | Pairing handshake |
| `[MESH]` | Node registration, relay/actuator state, reconnects |
| `[CFG]` | Gateway or node configuration activity |
| `[AUTH]` | Web interface authentication |
| `[WS]` | WebSocket client activity |
| `[OTA]` | Gateway OTA upload and reboot flow |
| `[C3]` | ESP32-C3 helper handshake, staging, and helper status |
| `[NODE OTA]` | Node OTA job lifecycle, node reconnect detection, and completion |

---

## WebSocket Message Reference

The dashboard communicates with the gateway over a single WebSocket at:

```text
ws://<gateway-ip>/ws
```

### Gateway -> Browser

| `type` | Description |
|---|---|
| `update` | Full node list with online state, uptime, sensors, actuator state, and relay labels |
| `meta` | Gateway metadata such as firmware version, uptime, IP, AP SSID, OTA support |
| `discovered` | Nodes currently broadcasting in pairing mode |
| `pair_timeout` | Pairing window expired |
| `pair_capacity_full` | The gateway is already at max node capacity and rejected the requested pair action |
| `node_settings` | Settings schema + current values for one node |
| `node_sensor_schema` | Sensor schema for one node |
| `relay_labels_ack` | Relay label save/reset acknowledgement |
| `ap_config_ack` | Setup AP config save acknowledgement |
| `web_creds_ack` | Web credential save acknowledgement |
| `gw_portal_starting` | Gateway is restarting into WiFiManager portal mode |
| `gw_rebooting` | Gateway is about to reboot |
| `gw_factory_reset` | Factory reset acknowledged |
| Node OTA progress/status messages | Helper staging, helper AP state, target-node reconnect, and completion/error feedback during Node OTA |
| `auth_required` / `auth_ok` / `auth_fail` / `session_expired` | Web interface auth flow |

### Browser -> Gateway

| `type` | Description |
|---|---|
| `auth` | Authenticate the WebSocket connection |
| `actuator_cmd` | Toggle an actuator on a paired actuator node |
| `pair_cmd` | Pair a discovered node |
| `unpair_cmd` | Disconnect and forget a paired node |
| `rename_node` | Change a node display name |
| `reboot_node` | Reboot a selected node |
| `reboot_gw` | Reboot the gateway |
| `set_ap_config` | Save setup AP SSID/password |
| `set_web_credentials` | Save dashboard login credentials |
| `start_wifi_portal` | Re-open WiFiManager setup portal |
| `factory_reset` | Clear gateway data and reboot |
| `gw_led_toggle` | Enable/disable the gateway status LED |
| `node_settings_get` | Request node settings schema |
| `node_settings_set` | Update one node setting |
| `node_sensor_schema_get` | Request node sensor schema |
| node OTA upload actions | Upload a compatible node `firmware.bin` and start gateway-managed Node OTA for the selected node |
| `relay_labels_set` | Save per-relay labels on the gateway |
| `ping` | Keep-alive |

---

## File Layout

```text
gateway_v1/
|-- src/
|   `-- main.cpp
|-- include/
|   |-- mesh_protocol.h
|   `-- coproc_ota_protocol.h
|-- coprocessor_esp32c3/
|   |-- src/
|   |   `-- main.cpp
|   |-- include/
|   |   `-- coproc_ota_protocol.h
|   `-- platformio.ini
|-- data/
|   |-- index.html
|   |-- js/
|   |   `-- app.js
|   `-- css/
|       `-- style.css
|-- partitions_8mb_noot.csv
|-- partitions_8mb_ota.csv
|-- platformio.ini
`-- README.md
```

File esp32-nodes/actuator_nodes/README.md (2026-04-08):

# Actuator Nodes

This directory contains firmware for ESP32-based actuator nodes used in the ESP-NOW Mesh System.

Actuator nodes receive commands from the gateway and control physical outputs such as relays. They follow the same pairing, heartbeat, registration, and settings flow used by sensor nodes, while also reporting actuator state back to the gateway so the Web Interface stays synchronized.

Supported actuator-node firmwares can also be updated through the **gateway-managed Node OTA** flow. During that OTA window, the selected node temporarily joins the helper AP created by the gateway's ESP32-C3 coprocessor, downloads the staged firmware, flashes it, and then returns to normal ESP-NOW operation after reboot.

---

## Currently Available

| Node | Actuator Type | Description |
|---|---|---|
| `esp32_relay_node_v1/` | 4-channel relay control + TTP224 Touch Sensor | Controls up to 4 active-LOW relays independently from the Web Interface (`v1.3.1`) |

---

## Supported Features

- ESP-NOW pairing with the gateway
- Automatic node registration and re-registration after reboot
- Heartbeat reporting
- Actuator state reporting back to the gateway
- Dashboard-based actuator control
- Per-node settings exposed in the Web Interface
- Persistent settings stored in NVS
- Optional relay state persistence, depending on node firmware
- Gateway-managed Node OTA delivery for supported actuator-node firmware
- Hardware-config-aware OTA safety checks for compatible actuator-node firmware

---

## Protocol Notes

Actuator nodes use the shared `mesh_protocol.h` definitions and the actuator messaging available in protocol version **v3.3.2**.

### Actuator-related message types

- `MSG_ACTUATOR_SCHEMA_GET`
- `MSG_ACTUATOR_SCHEMA`
- `MSG_ACTUATOR_STATE`
- `MSG_ACTUATOR_SET`

### Node types

- `NODE_SENSOR`
- `NODE_ACTUATOR`
- `NODE_HYBRID`
  Used by Hybrid-node firmwares that combine capabilities such as actuators plus RFID or sensors plus actuators in one device.

---

## Design Overview

Actuator nodes are designed to work much like sensor nodes, but instead of mainly publishing readings, they also:

1. Accept actuator commands from the gateway
2. Apply those commands to physical outputs
3. Report the resulting actuator state back to the gateway
4. Expose configurable node settings where needed
5. Participate in the gateway-managed Node OTA workflow when a compatible firmware image is uploaded from the dashboard

Current actuator-node firmwares also report their `HW_CONFIG_ID` during registration so the gateway can block incompatible actuator firmware before OTA delivery begins.

The newer release line also moves user-tunable actuator-node definitions into `user_config.h`. If a future actuator-node board uses the ESP32-C3 Super Mini, keep any WiFi transmit power cap board-gated and apply it only after Wi-Fi startup.

The current `v1.3.1` actuator-node line also tightens heartbeat/liveness timing so the node feels more stable and responsive with the gateway and with the gateway's MQTT/Home Assistant bridge.

When MQTT is enabled on the gateway:

- relay controls and supported actuator-node settings are exposed through Home Assistant MQTT discovery
- actuator state stays synchronized between Home Assistant and the gateway dashboard
- relay label settings remain dashboard-only, because Home Assistant already provides local naming for switches and buttons

Hybrid nodes that also expose actuator behavior are now documented separately under `../hybrid_nodes/`, but they share the same gateway-side actuator schema/state handling model.

This keeps the gateway and Web Interface synchronized after:
- actuator toggles
- node reboot
- gateway reconnect
- state persistence restore
- node OTA reboot/rejoin

---

## Current Implementation

### `esp32_relay_node_v1`

The first actuator firmware implementation is a relay control node.

Main capabilities:
- controls 4 relays independently
- reports relay states back to the gateway
- supports relay state persistence across reboot
- supports Status LED enable/disable setting
- exposes settings in the gateway Web Interface for easier control
- supports per-relay labels set from the Web Interface
- supports gateway-managed Node OTA with role and hardware-config validation

---

## Future Expansion

This directory is intended to grow with additional actuator node types, for example:

- relay boards with more channels
- dimmer nodes
- motor control nodes
- valve/solenoid controller nodes
- higher-channel relay nodes

Hybrid sensor + actuator boards now have a dedicated sibling directory:

- `../hybrid_nodes/`

---

## Directory Structure

```text
actuator_nodes/
|-- README.md
`-- esp32_relay_node_v1/
    |-- README.md
    |-- src/
    |-- include/
    |-- lib/
    `-- platformio.ini
```

For board-specific wiring, firmware configuration, build steps, settings, and Node OTA behavior, see the README inside each actuator node folder.

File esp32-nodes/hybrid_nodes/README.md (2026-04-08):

# Hybrid Nodes

Hybrid nodes combine multiple capability families in one firmware image. In the current project release, that means a node can participate in the actuator flow, expose Hybrid-specific configuration, and still be handled cleanly by the gateway and dashboard as a first-class `NODE_HYBRID` device.

Like the other node families, Hybrid nodes use ESP-NOW for normal mesh traffic and the gateway-managed helper-AP flow for **Node OTA** updates.

---

## Currently Available

| Node | Capabilities | Description |
|---|---|---|
| `esp32_hybrid_relay_node_v1/` | 4 relays + 4 touch inputs + RC522 RFID | Hybrid relay controller with RFID card actions and dashboard-managed relay scenes (`v0.3.2`) |

---

## Supported Features

- capability-based registration with `NODE_HYBRID`
- actuator schema reporting and live actuator-state sync
- Hybrid-specific configuration exchange for RFID card actions
- RFID scan events sent to the gateway/dashboard for scan-to-learn UX
- periodic RC522 health checks with automatic reader reinitialization if the RFID interface stalls after long uptime
- automatic re-registration after reboot or gateway restart
- gateway-managed Node OTA with role and hardware-config validation
- MAC-suffixed default names on fresh nodes for easier dashboard identification before manual rename

---

## Design Notes

Hybrid nodes should be treated as capability-driven devices, not hardcoded one-off exceptions. The gateway and web dashboard now use the node's reported type and capabilities to decide whether to show:

- sensor panels
- actuator controls
- Hybrid-specific sections such as RFID card actions

This keeps the first Hybrid implementation simple while leaving room for future nodes that combine sensors, actuators, and other hardware features in one firmware image.

For custom ESP32 hardware, Hybrid-node peripheral wiring should also avoid unnecessary use of ESP32 boot-strapping pins when safer GPIOs are available. The current RC522-based Hybrid reference now uses a non-strapping GPIO for the reader reset line so USB flashing remains reliable with the RFID module connected.

The newer release line also moves user-facing board definitions into `user_config.h`. If a future Hybrid-node board uses the ESP32-C3 Super Mini, keep any WiFi transmit power cap board-gated and apply it only after Wi-Fi startup.

The current Hybrid Relay Node release line also:

- uses the working `Arduino_MFRC522v2` RFID stack
- tightens heartbeat/liveness handling for more stable gateway connectivity and a snappier control/settings experience
- exposes supported relay controls, settings, and commands through the gateway's MQTT/Home Assistant bridge while keeping relay label settings dashboard-only

---

## Directory Structure

```text
hybrid_nodes/
|-- README.md
`-- esp32_hybrid_relay_node_v1/
    |-- README.md
    |-- src/
    |-- include/
    |-- lib/
    `-- platformio.ini
```

For board-specific wiring, firmware configuration, build steps, settings, and RFID behavior, see the README inside each Hybrid node folder.

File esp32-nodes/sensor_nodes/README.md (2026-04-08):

# Sensor Nodes

Sensor nodes read physical measurements and transmit them to the gateway over ESP-NOW every configurable interval (default: every 10 seconds).

Supported sensor-node firmwares can also be updated through the **gateway-managed Node OTA** flow. During that OTA window, the selected node temporarily joins the helper AP created by the gateway's ESP32-C3 coprocessor, downloads the staged firmware, flashes it, and then returns to normal ESP-NOW operation after reboot.

As of the current mesh protocol (`v3.3.2`), nodes are **self-describing**. Each node sends a sensor schema to the gateway at pair time that defines the labels, units, and precision of its readings. The gateway and web dashboard have no hardcoded knowledge of any specific sensor type and adapt automatically. Adding a new sensor to a node still requires only node firmware changes when the schema contract is preserved.

Current sensor-node firmwares also report a hardware configuration ID during registration so the gateway can block incompatible Node OTA images before delivery starts. They continue to work unchanged with the newer Hybrid-capable gateway/dashboard release.

---

## Available Sensor Nodes

| Directory | Sensors | Measurements | Board |
|---|---|---|---|
| `envo_mini_v1/` | Bosch BMP280 (SPI) + DHT22 + TEMT6000 | Temperature, Atmospheric Pressure, Humidity, Ambient Light | ESP32-C3 Super Mini (`v2.2.0`) |

---

## Adding a New Sensor Node

1. Copy an existing sensor node directory as a starting point
2. Add your sensor driver and initialisation logic in `setup()`
3. Add a `SensorDef` entry for each new measurement in `getSensorDefs()` and define its `id`, `label`, `unit`, and `precision`
4. Add the corresponding reading in `sendSensorData()` using the same `id`
5. Update `NODE_NAME` at the top of `main.cpp` (fresh, unrenamed nodes append the last 4 MAC characters automatically, so keep the base name within the current 24 visible-character limit)
6. Add per-node settings in `loadSettings()` / `saveSettings()` / `getSettingsDefs()` if needed; the gateway displays them automatically in the node settings panel
7. Preserve the node OTA metadata, role/version information, and `HW_CONFIG_ID` marker/reporting used by the gateway when validating uploaded node firmware images

No changes to `mesh_protocol.h`, the gateway firmware, or the web interface are required. The gateway learns what sensors a node has from the schema handshake at pair time.

The pairing flow, heartbeat, gateway-loss recovery, settings protocol, schema handshake, and Node OTA downloader flow are consistent across node types and can be reused from existing implementations.

Current release-line notes:

- user-facing node configuration now belongs in `user_config.h` instead of living entirely in `main.cpp`
- ESP32-C3 Super Mini sensor-node builds can apply a board-specific `WiFi.setTxPower(WIFI_POWER_8_5dBm)` limit after Wi-Fi startup when RF stability needs it
- the ESP32-C3 Super Mini antenna/LDO characterization data used to motivate that change is documented in [`../../docs/esp32_c3_supermini_wifi_tests/README.md`](../../docs/esp32_c3_supermini_wifi_tests/README.md)
- when MQTT is enabled on the gateway, sensor-node temperatures are published to Home Assistant in **degrees Celsius only** and the gateway does not expose temperature-unit settings through MQTT discovery, because Home Assistant already performs its own C/F conversion

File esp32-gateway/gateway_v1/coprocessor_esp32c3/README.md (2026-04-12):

# ESP32-C3 Gateway Coprocessor

Firmware version: **0.3.1**
Default target board: `dfrobot_beetle_esp32c3`

This firmware runs on the **ESP32-C3 coprocessor** attached to the ESP32-S3 gateway. It is not a standalone mesh node. Its main job is to help the gateway perform **Node OTA updates** by staging node firmware, creating a temporary helper access point, serving the staged `firmware.bin` over HTTP, and sending helper status back to the gateway over UART.

The current helper release line can also be updated from the same **Gateway Firmware Update** section in the dashboard, where the ESP32-S3 gateway stages a compatible helper `firmware.bin`, validates the helper board type, transfers it over UART, and waits for the ESP32-C3 to reboot into the new firmware.

In the current **Gateway v2.6.7** release line, the Offline Mode AP is hosted by the **ESP32-S3 main MCU**, not by this coprocessor. That means the helper remains available for Node OTA staging and helper self-OTA while the dashboard is being accessed through the gateway's Offline Mode AP.

The gateway also coordinates helper ownership now: if the ESP32-C3 is already busy serving a Node OTA session, the dashboard blocks helper self-OTA requests with a **Coprocessor Busy** message, and if helper self-OTA is already running, Node OTA requests are blocked until the helper returns to the idle state.

Current helper releases are used for sensor-node, actuator-node, and hybrid-node OTA jobs. The `v0.3.1` line keeps gateway-driven coprocessor self-OTA support, board-specific helper hardware validation, and alignment with the current gateway release line built around `user_config.h v1.1.3`, `coproc_ota_protocol.h v1.1.0`, and the MQTT-enabled gateway `v2.6.7` release. On `esp32c3_sm` builds it also applies the documented **8.5 dBm** Wi-Fi TX power cap after Wi-Fi startup for more stable Node OTA helper AP behavior on Gateway v1A and v1D hardware.

---

## What This Coprocessor Does

During a Node OTA update, the helper:

1. receives OTA commands from the ESP32-S3 gateway over UART
2. stages the uploaded node `firmware.bin` into its local filesystem
3. starts a temporary Wi-Fi access point for the target node
4. serves the staged firmware at `http://192.168.4.1/firmware.bin`
5. accepts helper status reports from the node on `/status`
6. reports progress and errors back to the gateway

During coprocessor self-OTA, the helper also receives a staged helper firmware image from the gateway over UART, writes the new image to its OTA slot, reports status back to the gateway, and reboots into the updated helper firmware.

The gateway remains the OTA orchestrator. The ESP32-C3 only handles the helper-side transport and temporary OTA hosting. It does **not** host the gateway Offline Mode AP or router failover logic.

This means incompatible uploads such as wrong-role firmware, wrong hardware-config firmware, or gateway firmware accidentally sent through the node OTA path are rejected by the gateway before the helper is engaged.

---

## Hardware

| Item | Detail |
|---|---|
| Board | DFRobot Beetle ESP32-C3 |
| Firmware role | Gateway coprocessor / Node OTA helper |
| UART link to gateway | `RX=GPIO0`, `TX=GPIO1` |
| UART baud | `230400` |
| Reboot signal pin | `GPIO7` |
| Helper AP IP | `192.168.4.1` |
| Helper HTTP port | `80` |

The current gateway hardware release line may host this helper role on an **ESP32-C3 Super Mini**, **Seeed Studio XIAO ESP32-C3**, or **DFRobot Beetle ESP32-C3**, depending on the selected gateway PCB variant. Contributors should keep helper UART routing, reset pins, and other board-level assumptions aligned with the intended hardware variant. Super Mini helper builds should also preserve the board-gated Wi-Fi TX power cap behavior and apply it only after Wi-Fi startup has completed.

---

## Shared Protocol

The helper communicates with the ESP32-S3 gateway using:

- `include/coproc_ota_protocol.h`

This file must stay synchronized with:

- `../include/coproc_ota_protocol.h`

Current shared helper transport version:

- `coproc_ota_protocol.h` **v1.1.0**

Important frame types include:

- `COPROC_FRAME_HELLO`
- `COPROC_FRAME_UPLOAD_BEGIN`
- `COPROC_FRAME_UPLOAD_CHUNK`
- `COPROC_FRAME_UPLOAD_END`
- `COPROC_FRAME_ABORT`
- `COPROC_FRAME_STATUS`

---

## Dependencies

Managed automatically by PlatformIO via `platformio.ini`:

| Library | Version |
|---|---|
| ArduinoJson | ^7.4.2 |

Framework libraries used directly: `WiFi`, `WebServer`, `LittleFS`.

---

## Build Environments

The helper firmware now exposes explicit PlatformIO environments for each supported ESP32-C3 helper board.

| Environment | Board | Coprocessor hardware-config ID |
|---|---|---|
| `beetle_esp32c3` | DFRobot Beetle ESP32-C3 | `0x0B` |
| `xiao_esp32c3` | Seeed Studio XIAO ESP32-C3 | `0x1B` |
| `esp32c3_sm` | ESP32-C3 Super Mini | `0x2B` |

Choose the environment that matches the helper board actually connected to the gateway.
## Build & Flash

From the `coprocessor_esp32c3/` directory:

```bash
# Optional clean erase
pio run --target erase

# Build and upload firmware
pio run --target upload

# Serial monitor
pio device monitor
```

Default serial monitor baud rate: **115200**.

You normally flash this helper once during gateway setup, then update it again only when helper-side behavior or the gateway-helper transport changes.

The newer release line moves board-selection and user-facing helper configuration into `user_config.h`; older checkouts may still keep some of those definitions near the top of `main.cpp`.

---

## Coprocessor OTA from the Gateway Web Interface

Once a compatible helper build is already running on the ESP32-C3, the gateway can update the helper itself from the browser.

This remains available even when the gateway dashboard is currently being served through the ESP32-S3 Offline Mode AP.

During this flow, the ESP32-S3 gateway:

1. validates the uploaded helper `firmware.bin`
2. validates the uploaded helper hardware-config ID against the expected helper board type
3. stages the image locally in LittleFS
4. tells the helper to prepare for self-OTA
5. transfers the image over UART
6. waits for the helper to flash, reboot, and reconnect

If the uploaded firmware targets the wrong helper board, the gateway rejects it before the UART transfer begins.
## Runtime Behavior

### Idle state

When no Node OTA job is active, the helper stays connected to the ESP32-S3 gateway over UART and responds to `HELLO` frames with:

- `helper-ready`

### During Node OTA

The helper:

- receives the node firmware in chunks from the gateway
- writes the image to LittleFS as `/firmware.bin`
- starts the temporary OTA helper AP
- serves the firmware to the target node over HTTP
- forwards node progress and completion status back to the gateway

### After completion or abort

The gateway sends an abort/cleanup command and the helper:

- stops the temporary AP
- stops the HTTP server
- becomes available again for either the next Node OTA session or a helper self-OTA request from the dashboard

---

## HTTP Endpoints

These endpoints are intended for the OTA target node during a live Node OTA session:

| Endpoint | Method | Purpose |
|---|---|---|
| `/firmware.bin` | `GET` | Streams the staged node firmware |
| `/status` | `POST` | Accepts OTA progress/error JSON from the node and forwards it to the gateway |

---

## Serial Monitor

```bash
pio device monitor
```

Useful log messages include:

| Prefix / Example | Meaning |
|---|---|
| `[C3] RX HELLO` | Gateway heartbeat / helper handshake |
| `[C3] RX UPLOAD_BEGIN` | Start of staged node firmware upload |
| `[C3] RX first UPLOAD_CHUNK` | First firmware chunk received from the gateway |
| `[C3] Staged ... / ... bytes` | Staging progress into LittleFS |
| `[C3] OTA AP started` | Temporary helper AP is running |
| `[C3] HTTP GET /firmware.bin` | Target node started downloading the staged image |
| `[C3] HTTP stream complete` | Full staged image was served to the node |
| `[C3] OTA helper abort received` | Gateway ended or aborted the helper session |

---

## Notes for Contributors

- This firmware should stay tightly aligned with the gateway Node OTA implementation.
- If you change `coproc_ota_protocol.h`, update both copies immediately.
- If you change helper AP behavior, chunk transport, or status reporting, test the full **gateway -> coprocessor -> node** OTA flow on real hardware.
- This helper is the foundation for future gateway-side offloaded features, so keep the design modular and well-scoped.

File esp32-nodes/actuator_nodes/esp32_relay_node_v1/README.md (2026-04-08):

# ESP32 Relay Node v1

Firmware version: **1.3.1**
Target board: `esp32dev`

## Firmware Changelog
| Version | Notes |
|---|---|
| v1.0.0 | Initial relay actuator node release with 4-channel relay control over ESP-NOW mesh |
| v1.0.1 | Added per-node settings support for relay state persistence and status LED control, added actuator-state sync after reconnect/reboot, and fixed relay-state persistence so all 4 relays restore correctly after reboot |
| v1.0.2 | Added capacitive touch sensor support to the ESP32 Relay Node with relay-state sync for the web interface |
| v1.1.0 | Added gateway-managed Node OTA support, helper-AP download handling, OTA finalization/reboot flow, and validated relay-node OTA reconnect behavior |
| v1.1.1 | Added `HW_CONFIG_ID` reporting/firmware markers so the gateway can reject incompatible actuator firmware during Node OTA |
| v1.2.0 | Updated to the `mesh_protocol.h v3.3.0` line with capability-aware registration and actuator-schema compatibility for the newer Hybrid-capable gateway/dashboard release |
| v1.2.1 | Restores the node status RGB LED to enabled when the node is unpaired from the gateway and saves that LED state back to NVS so pairing/status indication is visible again when the node is later re-paired |
| v1.2.2 | Updated to the `mesh_protocol.h v3.3.1` line with support for 24-character node names and automatic first-boot default naming that appends the last 4 MAC characters for easier node identification without aggressive truncation |
| v1.3.0 | Introduced `user_config.h` for user-tunable actuator-node definitions and keeps any future ESP32-C3 Super Mini WiFi transmit power cap board-gated and applied only after Wi-Fi startup |
| v1.3.1 | Fixes heartbeat/liveness timing for a more stable gateway link, faster perceived responsiveness, and better behavior with the gateway MQTT/Home Assistant bridge |

---

## Hardware

| Item | Detail |
|---|---|
| Board | ESP32-DevKitC (ESP-WROOM-32E) |
| Relay Module | 4-Way 5V 10A Active-Low Relay Module |
| Status LED | WS2812B on GPIO 22 |
| Pairing button | GPIO 16 (active-LOW, external pull-up) |
| Touch Sensor | TTP224 4-Way Capacitive Touch Sensor Module |

### Wiring

**Relay Module -> ESP32-DevKitC**

| Relay Module Pin | ESP32-DevKitC Pin |
|---|---|
| JD-VCC | 5V external power source |
| VCC | 3.3V |
| GND | GND and shared GND with external 5V power source |
| IN1 | GPIO 26 |
| IN2 | GPIO 27 |
| IN3 | GPIO 32 |
| IN4 | GPIO 33 |

> **Note:** The relay module must be powered by an external 5V power source connected to the JD-VCC pin, and its GND must be shared with the ESP32 GND. The IN1-IN4 pins are active-LOW, meaning they activate the relay when driven LOW.

**WS2812B breakout -> ESP32-DevKitC**

| WS2812B Pin | ESP32-DevKitC Pin |
|---|---|
| VCC | 5V |
| GND | GND |
| DATA-IN | GPIO 22 |
| DATA-OUT | Not connected |

**Capacitive Touch Sensor Module -> ESP32-DevKitC**

| TTP224 Pin | ESP32-DevKitC Pin |
|---|---|
| VCC | 3.3V |
| GND | GND |
| OUT1 | GPIO 25 (Relay 1 control) |
| OUT2 | GPIO 4 (Relay 2 control) |
| OUT3 | GPIO 13 (Relay 3 control) |
| OUT4 | GPIO 14 (Relay 4 control) |

---

## Dependencies

Managed automatically by PlatformIO via `platformio.ini`:

| Library | Version |
|---|---|
| Adafruit NeoPixel | 1.15.4 |

Framework libraries used directly: `Preferences`, `WiFi`, `Wire`.

## Configuration (`include/user_config.h`)

The current release line moves user-facing pin maps, board choices, and naming defaults into `user_config.h`. If your checkout predates that refactor, the same symbols may still live near the top of `src/main.cpp`.

Key values to review before flashing:

| Constant | Default | Description |
|---|---|---|
| `NODE_NAME` | `"Relay-Node"` | Base display name shown in the dashboard (up to 24 visible chars; fresh unrenamed nodes append the last 4 MAC characters automatically) |
| `RELAY1_PIN` | `26` | Relay-1 control GPIO |
| `RELAY2_PIN` | `27` | Relay-2 control GPIO |
| `RELAY3_PIN` | `32` | Relay-3 control GPIO |
| `RELAY4_PIN` | `33` | Relay-4 control GPIO |
| `PAIR_BTN_PIN` | `16` | Pairing button GPIO (active-LOW) |
| `LED_PIN` | `22` | WS2812B data GPIO |
| `TOUCH1_PIN` | `25` | TTP224 capacitive touch sensor 1 |
| `TOUCH2_PIN` | `4` | TTP224 capacitive touch sensor 2 |
| `TOUCH3_PIN` | `13` | TTP224 capacitive touch sensor 3 |
| `TOUCH4_PIN` | `14` | TTP224 capacitive touch sensor 4 |
| `relay_active_high` | `false` | Active-HIGH relay support flag |
| `HW_CONFIG_ID` | `"0x0C"` | Hardware configuration ID embedded in firmware and reported to the gateway for OTA compatibility checks |

When deploying multiple nodes, give each a unique `NODE_NAME` when practical. Fresh nodes already append the last 4 MAC characters automatically, and you can still rename them later from the gateway dashboard.

---

## Build & Flash

From the node project directory:

```bash
# First time - erase flash for a clean start
pio run --target erase

# Compile and upload
pio run --target upload
```

No LittleFS upload is needed for actuator nodes.

After the initial USB flash, future compatible firmware builds can be delivered from the gateway web interface using **Node OTA**.

---

## First Boot & Pairing

1. Flash the firmware
2. On first boot the node prints:
   ```
   [PAIR]  No pairing data - hold button 3 s to pair.
   ```
3. Make sure the gateway is online
4. Hold **GPIO 16** (the pairing button) for **3 seconds** - the LED turns cyan and the node begins beaconing
5. The gateway detects the beacon and completes the handshake automatically
6. The LED turns solid green - the node is now paired and transmitting

At pair time the node sends its actuator state, settings data, firmware version, and hardware configuration ID to the gateway so the dashboard can stay synchronized without extra manual configuration. The current gateway line also uses the same actuator-schema/state path for both pure actuator nodes and Hybrid nodes.

---

## Node OTA Update Support

When the gateway starts a Node OTA update for this device:

1. the node receives an OTA begin request over ESP-NOW
2. it connects to the temporary helper AP created by the gateway's ESP32-C3 coprocessor
3. it downloads the staged `firmware.bin`
4. it finalizes the new image, reboots, and re-registers automatically
5. relay control and dashboard synchronization resume after reconnect

Relay-node OTA has now been validated successfully with the current gateway-managed Node OTA workflow.

The gateway now validates both the `ACTUATOR` role marker and the matching `HW_CONFIG_ID` before the helper delivery flow is started.

When MQTT is enabled on the gateway, this node is also exposed through Home Assistant MQTT discovery. Relay states and supported settings stay synchronized between Home Assistant and the gateway dashboard.

Relay label settings are intentionally not exposed to Home Assistant, because Home Assistant already lets users rename switches and buttons locally.

---

## Per-Node Settings

These settings are configurable from the dashboard (Gateway -> Connected Nodes -> Settings):

| Setting | Type | Default | Range / Options |
|---|---|---|---|
| StatePersist | Bool | OFF | On / Off |
| Status LED | Bool | On | On / Off |

Settings are persisted in NVS under the namespace `"nodeconf"` - separate from pairing data, so a factory reset of the gateway does **not** wipe node settings.

- Enabling **StatePersist** enables relay-state save functionality, so all relay states are stored in flash and restored after reboot.
- Disabling **Status LED** turns off the WS2812B except during pairing and boot sequences.

---

## Serial Monitor

```bash
pio device monitor
```

Default baud rate: **115200**. Log prefixes:

| Prefix | Meaning |
|---|---|
| `[BOOT]` | Startup sequence |
| `[ACTUATOR]` | Actuator state/schema transmit |
| `[PAIR]` | Pairing handshake steps |
| `[CFG]` | Settings load / save / apply |
| `[NVS]` | NVS read / write |
| `[MESH]` | Gateway-loss detection and re-registration |
| `[ESP-NOW]` | TX result callbacks |
| `[RELAY STATE]` | Relay state change function |
| `[OTA]` | Gateway-managed node OTA download, flash, and reboot flow |

---

## NVS Namespaces

| Namespace | Contents |
|---|---|
| `"mesh"` | Pairing data (gateway MAC, channel, node ID) - cleared by factory reset |
| `"nodeconf"` | Node settings (relay persistence and LED enable) - **not** cleared by factory reset |
| `"relay"` | Relay state - **not** cleared by factory reset when persistence is enabled |

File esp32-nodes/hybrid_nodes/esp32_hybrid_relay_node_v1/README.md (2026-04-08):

# ESP32 Hybrid Relay Node v1

Firmware version: **0.3.2**
Target board: `esp32dev`

This is the first **Hybrid node** in the ESPNow Mesh System. It starts from the existing 4-relay actuator architecture, keeps the same touch-input and relay-control behavior, and adds an **RC522 RFID reader** so saved RFID cards can apply predefined relay scenes directly on the node.

The firmware registers itself as `NODE_HYBRID`, reports Hybrid capabilities to the gateway, exposes actuator schema/state like a normal relay node, and also exchanges RFID-card configuration with the dashboard. Supported builds can be updated through the same **gateway-managed Node OTA** flow used by the other node families. The current release line uses the working **Arduino_MFRC522v2** library, keeps the MQTT/Home Assistant bridge compatible through the gateway, and tightens heartbeat/liveness behavior for a more stable and responsive control flow.

## Firmware Changelog
| Version | Notes |
|---|---|
| v0.1.0 | Initial Hybrid Relay Node release with 4 relays, 4 TTP224 touch inputs, RC522 RFID card actions, dashboard RFID management, and gateway-managed Hybrid Node OTA support |
| v0.1.1 | Added periodic RC522 health checks with automatic reader recovery after long-uptime stalls, and updated the recommended RC522 reset wiring to a safer GPIO for reliable USB flashing |
| v0.1.2 | Restores the node status RGB LED to enabled when the node is unpaired from the gateway and saves that LED state back to NVS so pairing/status indication is visible again when the node is later re-paired |
| v0.1.3 | Updated to the `mesh_protocol.h v3.3.1` line with support for 24-character node names and automatic first-boot default naming that appends the last 4 MAC characters for easier node identification without aggressive truncation |
| v0.2.0 | Introduced `user_config.h` for Hybrid-node board and feature configuration, and documents the current release-line guidance for any future ESP32-C3 Super Mini based Hybrid variants |
| v0.3.2 | Switched to the working `Arduino_MFRC522v2` RFID library, fixed heartbeat/liveness timing for more stable gateway connectivity and a snappier UI feel, and keeps MQTT/Home Assistant control flows synchronized through the gateway |

---

## Hardware

| Item | Detail |
|---|---|
| Board | ESP32-DevKitC (ESP-WROOM-32E) |
| Relay Module | 4-Way 5V 10A active-LOW relay module |
| Touch Sensor | TTP224 4-Way Capacitive Touch Sensor Module |
| RFID Reader | RC522 / MFRC522 SPI RFID module |
| Status LED | WS2812B on GPIO 22 |
| Pairing button | GPIO 16 (active-LOW, internal pull-up) |

### Wiring

**Relay Module -> ESP32-DevKitC**

| Relay Module Pin | ESP32-DevKitC Pin |
|---|---|
| JD-VCC | 5V external power source |
| VCC | 3.3V |
| GND | GND and shared GND with external 5V power source |
| IN1 | GPIO 26 |
| IN2 | GPIO 27 |
| IN3 | GPIO 32 |
| IN4 | GPIO 33 |

> **Note:** The relay module is active-LOW. A relay turns ON when its control pin is driven LOW and turns OFF when driven HIGH.

**TTP224 -> ESP32-DevKitC**

| TTP224 Pin | ESP32-DevKitC Pin |
|---|---|
| VCC | 3.3V |
| GND | GND |
| OUT1 | GPIO 25 |
| OUT2 | GPIO 4 |
| OUT3 | GPIO 13 |
| OUT4 | GPIO 14 |

**WS2812B -> ESP32-DevKitC**

| WS2812B Pin | ESP32-DevKitC Pin |
|---|---|
| VCC | 5V |
| GND | GND |
| DATA-IN | GPIO 22 |

**RC522 / MFRC522 -> ESP32-DevKitC**

| RC522 Pin | ESP32-DevKitC Pin |
|---|---|
| SDA / SS | GPIO 17 |
| SCK | GPIO 18 |
| MOSI | GPIO 23 |
| MISO | GPIO 19 |
| RST | GPIO 21 |
| 3.3V | 3.3V |
| GND | GND |

> **Note:** The current recommended RC522 `RST` wiring uses **GPIO21**. Earlier experiments with `GPIO2` could interfere with reliable USB flashing on some hardware setups while the RFID module remained connected.

---

## Dependencies

Managed automatically by PlatformIO via `platformio.ini`:

| Library | Version |
|---|---|
| Adafruit NeoPixel | ^1.12.3 |
| ArduinoJson | ^7.4.2 |
| Arduino_MFRC522v2 | 2.0.6 |

Framework libraries used directly: `Preferences`, `WiFi`, `SPI`.

---

## Configuration (`include/user_config.h`)

The current release line moves user-facing pin maps, board choices, and naming defaults into `user_config.h`. If your checkout predates that refactor, the same symbols may still live near the top of `src/main.cpp`.

Key values to review before flashing:

| Constant | Default | Description |
|---|---|---|
| `NODE_NAME` | `"RFID-Hybrid-Node"` | Base display name shown in the dashboard (up to 24 visible chars; fresh unrenamed nodes append the last 4 MAC characters automatically) |
| `RELAY1_PIN` | `26` | Relay-1 control GPIO |
| `RELAY2_PIN` | `27` | Relay-2 control GPIO |
| `RELAY3_PIN` | `32` | Relay-3 control GPIO |
| `RELAY4_PIN` | `33` | Relay-4 control GPIO |
| `TOUCH1_PIN` | `25` | TTP224 touch output 1 |
| `TOUCH2_PIN` | `4` | TTP224 touch output 2 |
| `TOUCH3_PIN` | `13` | TTP224 touch output 3 |
| `TOUCH4_PIN` | `14` | TTP224 touch output 4 |
| `PAIR_BTN_PIN` | `16` | Pairing button GPIO (active-LOW) |
| `LED_PIN` | `5` | WS2812B data GPIO |
| `RFID_CS_PIN` | `17` | RC522 chip-select pin |
| `RFID_RST_PIN` | `21` | RC522 reset pin |
| `HW_CONFIG_ID` | `"0x0D"` | Hardware configuration ID embedded in firmware and reported to the gateway for OTA compatibility checks |

When deploying multiple nodes, give each node a unique `NODE_NAME` when practical. Fresh nodes already append the last 4 MAC characters automatically, and you can still rename them later from the gateway dashboard.

---

## Build & Flash

From the node project directory:

```bash
# First time - erase flash for a clean start
pio run --target erase

# Compile and upload
pio run --target upload
```

No LittleFS upload is needed for Hybrid nodes.

After the initial USB flash, future compatible firmware builds can be delivered from the gateway web interface using **Node OTA**.

If USB flashing fails while the RC522 reader is connected, double-check that the reader `RST` line is wired to the recommended non-strapping GPIO and not to an ESP32 boot-related pin on your hardware variant.

---

## First Boot & Pairing

1. Flash the firmware
2. On first boot the node prints:
   ```
   [PAIR]  No pairing data - hold button 3 s to pair.
   ```
3. Make sure the gateway is online
4. Hold **GPIO 16** for **3 seconds** - the LED turns cyan and the node begins beaconing
5. The gateway detects the beacon and completes the handshake automatically
6. The LED turns solid green - the node is now paired and transmitting

At pair time the node sends its actuator state, settings data, firmware version, hardware configuration ID, and Hybrid capability information to the gateway so the dashboard can render the correct Hybrid controls without extra manual setup.

---

## RFID Card Actions

The RC522 reader allows the gateway/dashboard to store up to **8 saved RFID card slots** on the node.

Current workflow:

1. Swipe an unknown card on the RC522 reader
2. The node sends an RFID scan event to the gateway
3. In the dashboard, choose the scanned card from the RFID Card Actions section
4. Set the desired ON/OFF state for each relay
5. Save the card action back to the node

When that saved card is presented again, the node:

- matches the RFID UID to a saved slot
- applies the saved relay mask as an absolute relay-state overwrite
- reports the new actuator state back to the gateway
- emits a scan event so the dashboard stays synchronized

Unknown cards do not change relay state until a card action is saved for them.

The current firmware also performs periodic RC522 health checks at runtime and will reinitialize the reader automatically if the RFID interface stalls after long uptime, reducing the need to manually reboot the node just to restore card detection.

---

## Node OTA Update Support

When the gateway starts a Node OTA update for this device:

1. the node receives an OTA begin request over ESP-NOW
2. it connects to the temporary helper AP created by the gateway's ESP32-C3 coprocessor
3. it downloads the staged `firmware.bin`
4. it finalizes the new image, reboots, and re-registers automatically
5. actuator control, RFID features, and dashboard synchronization resume after reconnect

The gateway validates both the `HYBRID` role marker and the matching `HW_CONFIG_ID` before the helper delivery flow is started.

Validated behaviors include:

- version upgrades
- version downgrades
- rejection of sensor firmware uploaded to a Hybrid target
- rejection of actuator firmware uploaded to a Hybrid target
- successful reconnect after Hybrid-node OTA

When MQTT is enabled on the gateway, this node is also exposed through Home Assistant MQTT discovery. Supported relay controls, supported settings, reboot, and unpair stay synchronized with the gateway dashboard.

Relay label settings are intentionally not exposed to Home Assistant, because Home Assistant already lets users rename switches and buttons locally.

---

## Per-Node Settings

These settings are configurable from the dashboard (Gateway -> Connected Nodes -> Settings):

| Setting | Type | Default | Range / Options |
|---|---|---|---|
| StatePersist | Bool | OFF | On / Off |
| Status LED | Bool | On | On / Off |

Settings are persisted in NVS under the node configuration namespace.

- Enabling **StatePersist** stores relay states in flash and restores them after reboot.
- Disabling **Status LED** turns off the WS2812B except during pairing and boot sequences.

---

## Serial Monitor

```bash
pio device monitor
```

Default baud rate: **115200**. Useful log prefixes:

| Prefix | Meaning |
|---|---|
| `[BOOT]` | Startup sequence |
| `[ACTUATOR]` | Actuator state/schema transmit |
| `[PAIR]` | Pairing handshake steps |
| `[CFG]` | Settings load / save / apply |
| `[NVS]` | NVS read / write |
| `[ESP-NOW]` | TX result callbacks |
| `[RELAY STATE]` | Relay state change function |
| `[RFID]` | RC522 reader status, scan events, and saved card actions |
| `[OTA]` | Gateway-managed Hybrid node OTA download, flash, and reboot flow |

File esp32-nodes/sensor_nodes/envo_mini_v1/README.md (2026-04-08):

# Envo Mini V1 Node

Firmware version: **2.2.0**
Target board: `nologo_esp32c3_super_mini`

Reads temperature and barometric pressure from a **Bosch BMP280**, humidity from a **DHT22**, and ambient light level from a **TEMT6000** phototransistor. Transmits all readings to the gateway over ESP-NOW using the schema-driven sensor protocol, so the node self-describes its sensors to the gateway at pair time and no gateway changes are needed when sensors are added or removed.

This node also supports the **gateway-managed Node OTA** workflow introduced with the ESP32-S3 gateway release line and the ESP32-C3 helper coprocessor. Current releases also report this node's hardware configuration ID so the gateway can reject incompatible sensor firmware before the OTA session starts, remain fully compatible with the Hybrid-capable and MQTT-capable gateway/dashboard line built on `mesh_protocol.h v3.3.2`, and advertise clearer default names by appending the last 4 MAC characters on fresh, unrenamed nodes.

The newer `v2.2.0` release line also moves user-tunable definitions into `user_config.h`, polishes discovery timing for faster pairing feedback, and applies a board-gated `WiFi.setTxPower(WIFI_POWER_8_5dBm)` limit only when this firmware is built for the ESP32-C3 Super Mini path.

## Firmware Changelog
| Version | Notes |
|---|---|
| v2.0.0 | Added two more sensors: DHT22 for relative humidity and TEMT6000 for ambient light |
| v2.0.1 | Added more serial-monitor debugging messages |
| v2.1.0 | Added gateway-managed Node OTA support, helper-AP download handling, OTA finalization/reboot flow, and improved OTA status reporting |
| v2.1.1 | Added `HW_CONFIG_ID` reporting/firmware markers for hardware-safe OTA validation and compatibility checks from the gateway |
| v2.1.2 | Updated to the `mesh_protocol.h v3.3.0` line with capability-aware registration for compatibility with the Hybrid-node-capable gateway release while preserving existing sensor behavior |
| v2.1.3 | Restores the node status RGB LED to enabled when the node is unpaired from the gateway and saves that LED state back to NVS so pairing/status indication is visible again when the node is later re-paired |
| v2.1.4 | Updated to the `mesh_protocol.h v3.3.1` line with support for 24-character node names and automatic first-boot default naming that appends the last 4 MAC characters for easier node identification without aggressive truncation |
| v2.2.0 | Introduced `user_config.h`, polished node discovery timing for faster pairing feedback, and applies the ESP32-C3 Super Mini WiFi transmit power cap only after Wi-Fi startup |

---

## Hardware

| Item | Detail |
|---|---|
| Board | ESP32-C3 Super Mini |
| Sensor 1 | Bosch BMP280 (temperature + pressure), SPI |
| Sensor 2 | DHT22 (humidity), single-wire |
| Sensor 3 | TEMT6000 phototransistor module (ambient light), ADC |
| Status LED | WS2812B on GPIO 3 |
| Pairing button | GPIO 0 (active-LOW, internal pull-up) |

### Wiring

**BMP280 breakout -> ESP32-C3 Super Mini**

| BMP280 Pin | ESP32-C3 Super Mini Pin |
|---|---|
| VCC | 3V3 |
| GND | GND |
| SCK | GPIO 6 |
| SDI | GPIO 7 |
| CSB | GPIO 10 |
| SDO | GPIO 5 |

The BMP280 now runs over the hardware SPI bus instead of I2C.

**DHT22 -> ESP32-C3 Super Mini**

| DHT22 Pin | ESP32-C3 Super Mini Pin |
|---|---|
| VCC | 3V3 |
| GND | GND |
| DATA | GPIO 1 |

**TEMT6000 module -> ESP32-C3 Super Mini**

| TEMT6000 Pin | ESP32-C3 Super Mini Pin |
|---|---|
| VCC | 3V3 |
| GND | GND |
| SIG | GPIO 4 |

The TEMT6000 module has an on-board 10K emitter resistor, so the signal pin is always actively driven and does not require an external pull-down.

For the ESP32-C3 Super Mini RF characterization that motivated the board-specific TX-power cap support, see [`../../../docs/esp32_c3_supermini_wifi_tests/README.md`](../../../docs/esp32_c3_supermini_wifi_tests/README.md).

---

## Dependencies

Managed automatically by PlatformIO via `platformio.ini`:

| Library | Version |
|---|---|
| Adafruit BMP280 Library | 2.6.8 |
| Adafruit Unified Sensor | 1.1.15 |
| Adafruit NeoPixel | 1.15.4 |
| DHT sensor library | 1.4.7 |

Framework libraries used directly: `Preferences`, `WiFi`, `SPI`.

---

## Configuration (`include/user_config.h`)

The current release line moves user-tunable board definitions into `user_config.h`. If your checkout predates that refactor, the same symbols may still live near the top of `src/main.cpp`.

Key values for the ESP32-C3 Super Mini + BMP280 SPI build are:

| Constant | Default | Description |
|---|---|---|
| `NODE_NAME` | `"BMP280-Node"` | Base display name shown in the dashboard (up to 24 visible chars; fresh unrenamed nodes append the last 4 MAC characters automatically) |
| `DHT_PIN` | `1` | DHT22 data GPIO |
| `TEMT6000_PIN` | `4` | TEMT6000 ADC GPIO |
| `PAIR_BTN_PIN` | `0` | Pairing button GPIO (active-LOW) |
| `LED_PIN` | `3` | WS2812B data GPIO |
| `BMP_SCK` | `6` | BMP280 SPI clock GPIO |
| `BMP_MISO` | `5` | BMP280 SPI MISO GPIO |
| `BMP_MOSI` | `7` | BMP280 SPI MOSI GPIO |
| `BMP_CS` | `10` | BMP280 chip-select GPIO |
| `HW_CONFIG_ID` | `"0x3B"` | Hardware configuration ID embedded in firmware and reported to the gateway for OTA compatibility checks |
| `WIFI_POWER_8_5dBm` cap | Enabled only on ESP32-C3 Super Mini builds | Applied after Wi-Fi startup to improve RF stability on marginal Super Mini boards |

When deploying multiple nodes, give each a unique `NODE_NAME` when practical. Fresh nodes already append the last 4 MAC characters automatically, and you can still rename them later from the gateway dashboard.

---

## Build & Flash

From the node project directory:

```bash
# First time - erase flash for a clean start
pio run --target erase

# Compile and upload
pio run --target upload
```

No LittleFS upload is needed for sensor nodes (no web assets).

After the initial USB flash, future compatible firmware builds can be delivered from the gateway web interface using **Node OTA**.

---

## First Boot & Pairing

1. Flash the firmware
2. On first boot the node prints:
   ```
   [PAIR]  No pairing data - hold button 3 s to pair.
   ```
3. Make sure the gateway is online
4. Hold **GPIO 0** (the pairing button) for **3 seconds** - the LED turns cyan and the node begins beaconing
5. The gateway detects the beacon and completes the handshake automatically
6. The LED turns solid green - the node is now paired and transmitting

At pair time the node sends its sensor schema, firmware version, and hardware configuration ID to the gateway. The gateway and dashboard adapt automatically - no configuration required on the gateway side.

---

## Node OTA Update Support

When the gateway starts a Node OTA update for this device:

1. the node receives an OTA begin request over ESP-NOW
2. it connects to the temporary helper AP created by the gateway's ESP32-C3 coprocessor
3. it downloads the staged `firmware.bin`
4. it finalizes the new image, reboots, and re-registers automatically

Validated behaviors now include:

- same-version reflashing
- version upgrades
- version downgrades

The gateway now validates both the `SENSOR` role marker and the matching `HW_CONFIG_ID` before the OTA helper flow is started.

---

## Sensor Schema

The node reports the following sensors. Only sensors that initialise successfully at boot are included in the schema.

| ID | Label | Unit | Source |
|----|---|---|---|
| 0 | Temperature | degC or degF in the dashboard, degC in MQTT/Home Assistant | BMP280 |
| 1 | Atmospheric Pressure | hPa | BMP280 |
| 2 | Humidity | % | DHT22 |
| 3 | Ambient Light | % | TEMT6000 |

The light level is scaled logarithmically to match perceptual brightness - a well-lit room reads approximately 40-60% at default sensitivity.

---

## Per-Node Settings

These settings are configurable from the dashboard (Gateway -> Connected Nodes -> Settings):

| Setting | Type | Default | Range / Options |
|---|---|---|---|
| Temp Unit | Enum | degC | degC / degF |
| Send Intvl | Integer | 10 s | 5-60 s (step 5) |
| Status LED | Bool | On | On / Off |
| Light Sens | Integer | 5 | 1-10 (step 1) |

Settings are persisted in NVS under the namespace `"nodeconf"` - separate from pairing data, so a factory reset of the gateway does **not** wipe node settings.

- Changing **Temp Unit** affects the value shown through the gateway dashboard flow; for MQTT/Home Assistant the gateway still publishes this node's temperature in Celsius and leaves unit conversion to Home Assistant.
- Changing **Send Intvl** takes effect immediately - no reboot required.
- Disabling **Status LED** turns off the WS2812B except during pairing and boot sequences.
- **Light Sens** shifts the entire brightness curve up or down. Lower values make the sensor less responsive (useful in very bright environments); higher values increase sensitivity in dim conditions.

For the MQTT / Home Assistant bridge:

- the gateway intentionally publishes this node's temperature in **degrees Celsius only**
- the **Temp Unit** setting is not exposed to Home Assistant
- Home Assistant handles C/F conversion itself if the user prefers Fahrenheit in the UI

---

## Serial Monitor

```bash
pio device monitor
```

Default baud rate: **115200**. Log prefixes:

| Prefix | Meaning |
|---|---|
| `[BOOT]` | Startup sequence |
| `[BMP]` | BMP280 initialisation result |
| `[DHT]` | DHT22 initialisation result |
| `[TEMT]` | TEMT6000 ADC initialisation result |
| `[SENS]` | Sensor schema transmit and per-cycle reading results |
| `[PAIR]` | Pairing handshake steps |
| `[CFG]` | Settings load / save / apply |
| `[NVS]` | NVS read / write |
| `[MESH]` | Gateway-loss detection and re-registration |
| `[ESP-NOW]` | TX result callbacks |
| `[OTA]` | Gateway-managed node OTA download, flash, and reboot flow |

---

## NVS Namespaces

| Namespace | Contents |
|---|---|
| `"mesh"` | Pairing data (gateway MAC, channel, node ID) - cleared by factory reset |
| `"nodeconf"` | Node settings (temp unit, send interval, LED enable, light sensitivity) - **not** cleared by factory reset |

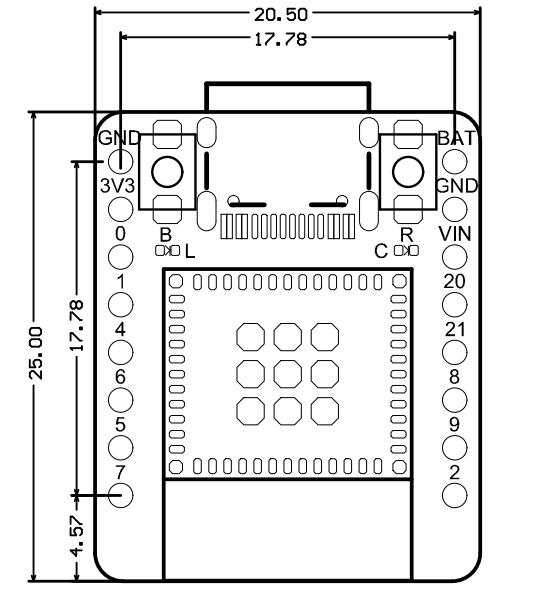
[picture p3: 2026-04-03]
esp32-gateway/gateway_v1/hardware/Development_Resources/esp32-c3/beetle_esp32_c3/Beetle_ESP32-C3_Mechanical_Drawing.jpg

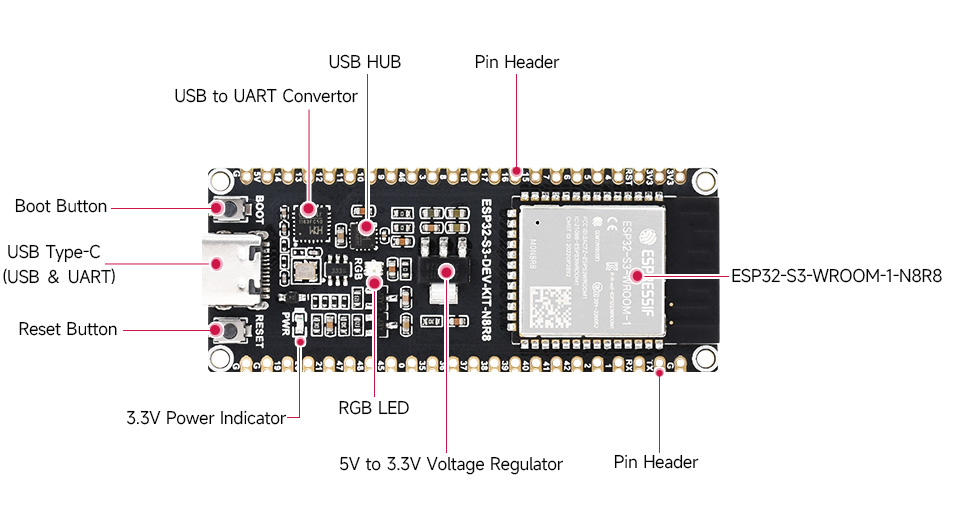
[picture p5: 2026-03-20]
esp32-gateway/gateway_v1/hardware/Development_Resources/esp32-s3/esp32_s3_devkit/ESP32-S3-DEV-KIT-N8R8_Overview.jpg

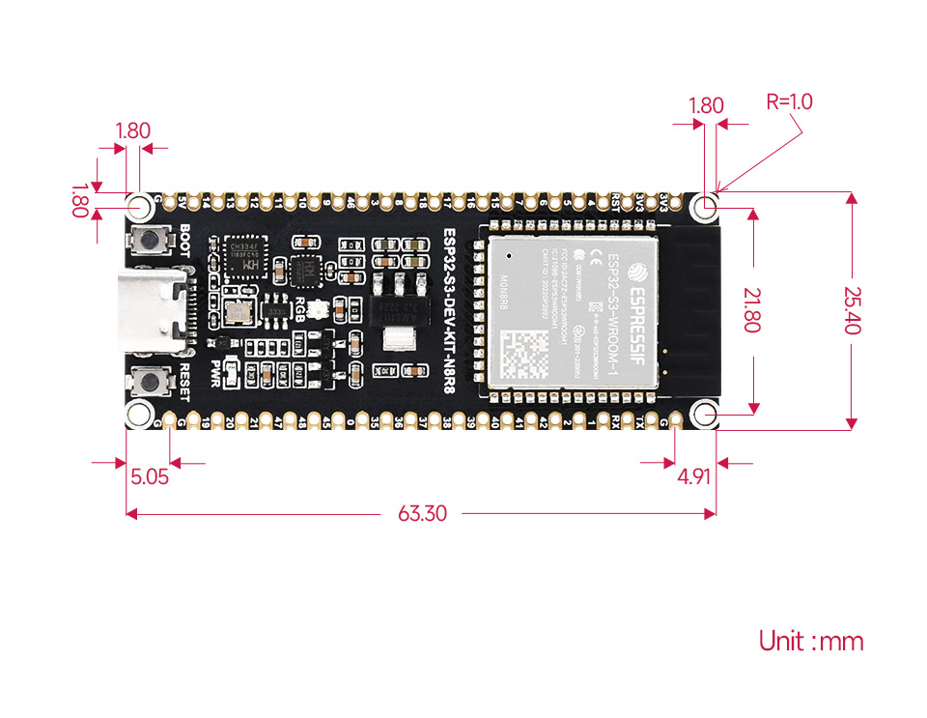
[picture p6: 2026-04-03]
esp32-gateway/gateway_v1/hardware/Development_Resources/esp32-s3/esp32_s3_devkit/ESP32-S3-DEV-KIT-N8R8_dim.jpg

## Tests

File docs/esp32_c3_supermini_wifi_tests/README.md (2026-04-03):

# ESP32-C3 Super Mini WiFi Tests And Hardware Mod Guide

This document summarizes the WiFi receive and WiFi transmit tests performed on three ESP32-C3 Super Mini development boards while investigating why some ESP32-C3 based nodes were not being detected reliably by the ESP32-S3 gateway.

Every RSSI value in this report is the average of three readings, which is why several values are fractional.

---

## Why These Tests Were Performed

The main trigger for these tests was a practical mesh-system issue:

- some ESP32-C3 Super Mini based nodes would enter pairing mode correctly
- their firmware appeared to send beacons correctly
- but the ESP32-S3 gateway would not reliably detect them

That made it necessary to separate:

- firmware and ESP-NOW logic issues
- power-delivery issues
- RF / antenna issues
- board-quality differences between individual ESP32-C3 Super Mini boards

---

## Test Setup

- Three ESP32-C3 Super Mini boards were tested
- Device-to-device distance was approximately `49 inches`
- `DDOS` (home router) was used as a stable reference network
- `ESP32_Test` was the SSID broadcast by an ESP32-WROOM-32E development board during receive tests
- `ESP32C3_Test` was the SSID broadcast by the ESP32-C3 Super Mini board under test during transmit tests
- An ESP32-S3-WROOM-1 DevKitC board was used as a reference receiver alongside the main receiver under test
- Tests `10` to `12` used `WiFi.setTxPower(WIFI_POWER_8_5dBm);`
- Tests `7` to `9` used no WiFi transmit power limit and no external `3.3V` supply

Important software note:
- the `8.5 dBm` transmit-power cap is only meaningful when it is applied after WiFi startup, not during early boot

---

## Board Configurations Used In The Tests

### Test Configuration A: Boards as they existed during Tests 1 to 6

These were not all stock boards.

| Board | State used in Tests `1` to `6` |
|---|---|
| `Board-1` | Stock ceramic antenna, stock onboard LDO |
| `Board-2` | Stock antenna already replaced with a `31 mm` quarter-wave style steel-wire antenna (`0.82 mm` wire diameter), stock onboard LDO |
| `Board-3` | Stock antenna already replaced with a helix / spring-coil brass-wire antenna (`0.83 mm` wire diameter), stock onboard LDO |

### Test Configuration B: Boards after the later LDO and antenna rework used in Tests 7 to 12

| Board | State used in Tests `7` to `12` |
|---|---|
| `Board-1` | Stock ceramic antenna removed and replaced with an external PCB antenna connected by shielded wire |
| `Board-2` | Onboard LDO replaced with `MIC5219-3.3YM5`; quarter-wave antenna removed and replaced with a helix / spring-coil brass-wire antenna |
| `Board-3` | Onboard LDO replaced with `MIC5219-3.3YM5`; helix / spring-coil brass-wire antenna retained |

---

## Test Configuration A Results: Tests 1 To 6

### Receive Tests (`Test-1` to `Test-3`)

| Test | Board under test | DUT RSSI `DDOS` | DUT RSSI `ESP32_Test` | DUT networks | Ref S3 RSSI `DDOS` | Ref S3 RSSI `ESP32_Test` | Ref S3 networks |
|---|---|---|---|---|---|---|---|
| `Test-1` | `Board-1` stock antenna | `-47.00 dBm` | `-60.67 dBm` | `5` | `-29.00 dBm` | `-48.33 dBm` | `6` |
| `Test-2` | `Board-2` quarter-wave steel antenna | `-31.33 dBm` | `-53.33 dBm` | `6` | `-29.00 dBm` | `-50.00 dBm` | `7` |
| `Test-3` | `Board-3` helix brass antenna | `-36.66 dBm` | `-55.00 dBm` | `7` | `-31.33 dBm` | `-50.66 dBm` | `7` |

### Transmit Tests On Onboard Supply (`Test-1` to `Test-3`)

| Test | AP board under test | WROOM-32E RSSI `DDOS` | WROOM-32E RSSI `ESP32C3_Test` | WROOM-32E networks | Ref S3 RSSI `DDOS` | Ref S3 RSSI `ESP32C3_Test` | Ref S3 networks |
|---|---|---|---|---|---|---|---|
| `Test-1` | `Board-1` stock antenna | `-29.33 dBm` | `-69.00 dBm` | `7` | `-29.67 dBm` | `-63.67 dBm` | `7` |
| `Test-2` | `Board-2` quarter-wave steel antenna | `-36.33 dBm` | `Not detected` | `7` | `-29.33 dBm` | `Not detected` | `7` |
| `Test-3` | `Board-3` helix brass antenna | `-32.33 dBm` | `Not detected` | `6` | `-32.33 dBm` | `Not detected` | `6` |

### Transmit Tests On External `3.3V` Supply (`Test-4` to `Test-6`)

| Test | AP board under test | WROOM-32E RSSI `DDOS` | WROOM-32E RSSI `ESP32C3_Test` | WROOM-32E networks | Ref S3 RSSI `DDOS` | Ref S3 RSSI `ESP32C3_Test` | Ref S3 networks |
|---|---|---|---|---|---|---|---|
| `Test-4` | `Board-1` stock antenna + external `3.3V` | `-35.33 dBm` | `-72.33 dBm` | `8` | `-30.00 dBm` | `-64.00 dBm` | `7` |
| `Test-5` | `Board-2` quarter-wave steel antenna + external `3.3V` | `-35.67 dBm` | `Not detected` | `7` | `-27.33 dBm` | `Not detected` | `7` |
| `Test-6` | `Board-3` helix brass antenna + external `3.3V` | `-32.33 dBm` | `-55.67 dBm` | `7` | `-35.00 dBm` | `-54.00 dBm` | `8` |

### What Tests 1 To 6 Showed

- `Board-1` was weak but still functional in both receive and transmit tests
- `Board-2` showed strong receive performance but effectively failed transmit tests even with external `3.3V`
- `Board-3` only became a stable transmitter when powered from a stronger external `3.3V` source

Those results pointed to two different issues:

- `Board-2` looked like an RF / transmit-path problem
- `Board-3` looked like a power-delivery / onboard-LDO problem

---

## Test Configuration B Results: Tests 7 To 12

### Receive Tests After The Rework (`Test-7` to `Test-9`)

| Test | Board under test | DUT RSSI `DDOS` | DUT RSSI `ESP32_Test` | DUT networks | Ref S3 RSSI `DDOS` | Ref S3 RSSI `ESP32_Test` | Ref S3 networks |
|---|---|---|---|---|---|---|---|
| `Test-7` | `Board-1` external PCB antenna | `-29.33 dBm` | `-44.00 dBm` | `7` | `-31.00 dBm` | `-45.33 dBm` | `8` |
| `Test-8` | `Board-2` helix brass antenna + `MIC5219` | `-38.00 dBm` | `-53.00 dBm` | `5` | `-32.00 dBm` | `-46.33 dBm` | `7` |
| `Test-9` | `Board-3` helix brass antenna + `MIC5219` | `-38.00 dBm` | `-50.67 dBm` | `5` | `-32.00 dBm` | `-46.00 dBm` | `8` |

### Transmit Tests After The Rework At Default Power (`Test-7` to `Test-9`)

| Test | AP board under test | WROOM-32E RSSI `DDOS` | WROOM-32E RSSI `ESP32C3_Test` | WROOM-32E networks | Ref S3 RSSI `DDOS` | Ref S3 RSSI `ESP32C3_Test` | Ref S3 networks |
|---|---|---|---|---|---|---|---|
| `Test-7` | `Board-1` external PCB antenna | `-32.00 dBm` | `Not detected` | `6` | `-40.00 dBm` | `Not detected` | `6` |
| `Test-8` | `Board-2` helix brass antenna + `MIC5219` | `-32.67 dBm` | `-49.67 dBm` | `7` | `-35.67 dBm` | `-47.33 dBm` | `7` |
| `Test-9` | `Board-3` helix brass antenna + `MIC5219` | `-35.00 dBm` | `Not detected` | `6` | `-36.33 dBm` | `Not detected` | `6` |

### Transmit Tests After The Rework With `8.5 dBm` Cap (`Test-10` to `Test-12`)

| Test | AP board under test | WROOM-32E RSSI `DDOS` | WROOM-32E RSSI `ESP32C3_Test` | WROOM-32E networks | Ref S3 RSSI `DDOS` | Ref S3 RSSI `ESP32C3_Test` | Ref S3 networks |
|---|---|---|---|---|---|---|---|
| `Test-10` | `Board-1` external PCB antenna + `8.5 dBm` cap | `-34.00 dBm` | `-52.00 dBm` | `7` | `-31.33 dBm` | `-47.33 dBm` | `8` |
| `Test-11` | `Board-2` helix brass antenna + `MIC5219` + `8.5 dBm` cap | `-38.67 dBm` | `-69.33 dBm` | `7` | `-34.33 dBm` | `-51.33 dBm` | `7` |
| `Test-12` | `Board-3` helix brass antenna + `MIC5219` + `8.5 dBm` cap | `-37.33 dBm` | `-58.33 dBm` | `7` | `-31.67 dBm` | `-50.33 dBm` | `7` |

### What Tests 7 To 12 Showed

- `Board-2` improved dramatically after the LDO replacement and antenna change
- `Board-3` improved after the LDO replacement but still benefited from the `8.5 dBm` cap
- `Board-1` gained excellent receive performance with the external PCB antenna, but its transmit side was still better behaved once the `8.5 dBm` cap was used

---

## Board Mod Guide

These modifications are meant for prototype and experimental use. They are not recommended for users who are not comfortable with fine-pitch SMD rework.

### Before You Start

1. Test the board first in stock form so you have a baseline.
2. Photograph the board before removing any parts.
3. Use magnification while working around the RF section and the LDO.
4. Keep airflow moderate so you do not blow away tiny RF parts.
5. After every rework stage, check for shorts before powering the board.

### LDO Replacement Guide

This was the rework used on `Board-2` and `Board-3`.

1. Identify the stock `3.3V` LDO on the ESP32-C3 Super Mini board.
2. Remove the stock LDO carefully with hot air and flux.
3. Clean the pads fully and inspect for lifted pads or solder bridges.
4. Install `MIC5219-3.3YM5` in the correct orientation.
5. Recheck continuity between:
   - `VIN` and `GND`
   - `VOUT` and `GND`
   - the LDO output rail and the ESP32-C3 `3.3V` rail
6. Power the board and confirm the output rail is stable at `3.3V` before running WiFi tests.
7. Re-test WiFi transmit behavior after the LDO swap before making further RF changes if you want to isolate the effect of the regulator alone.

### Antenna Modification Guide

These are the antenna approaches used during the tests.

#### Option A: External PCB antenna via shielded wire

This was the approach used on `Board-1` for the later tests.

1. Remove the stock ceramic antenna cleanly.
2. Expose and inspect the antenna feed area carefully.
3. Use a short shielded feed wire.
4. Connect the feed conductor to the RF feed point.
5. Connect the shield side according to the board's ground side around the antenna feed area.
6. Keep the cable as short and mechanically stable as possible.
7. Mount the external PCB antenna away from the crystal oscillator, regulator, and the rest of the dense board area.
8. Re-test both WiFi receive and WiFi transmit behavior after the antenna change.

#### Option B: Helix / spring-coil wire antenna

This was the approach used on `Board-3`, and later also on `Board-2`.

1. Remove the stock ceramic antenna.
2. Prepare the helix / spring-coil antenna from brass wire.
3. Solder the helix antenna neatly at the antenna feed point.
4. Keep the antenna clear of nearby metal, bench fixtures, and USB cable strain while testing.
5. Re-test receive and transmit behavior after the swap.

#### Option C: Quarter-wave straight wire antenna

This was the earlier approach used on `Board-2`.

1. Remove the stock ceramic antenna.
2. Prepare a straight quarter-wave wire antenna.
3. Solder it carefully to the antenna feed point.
4. Re-test receive and transmit behavior.

In these tests, the quarter-wave steel-wire implementation improved receive performance but did not solve the transmit problem on `Board-2`, so it was later replaced by the helix antenna.

### Recommended Rework Sequence

If someone still wants to use ESP32-C3 Super Mini boards for prototype mesh nodes, this order is more sensible than changing everything at once:

1. Test the board in stock form.
2. If WiFi transmit looks unstable, replace the onboard LDO first.
3. Re-test the board.
4. If RF performance is still weak, replace the stock ceramic antenna with a more suitable external solution.
5. Re-test again.
6. If the board is still marginal, try the `8.5 dBm` TX cap in firmware, but only after WiFi startup has completed.

---

## Findings

### 1. Some ESP32-C3 Super Mini boards had real power-delivery problems

- `Board-3` clearly improved once its onboard LDO was replaced
- `Board-2` also improved after the same regulator upgrade

That supports the conclusion that some of these boards ship with weak or unstable onboard LDO implementations.

### 2. The stock ceramic antenna arrangement is a weak point

- `Board-1` improved dramatically on receive after moving to an external PCB antenna
- the stock antenna layout appears compromised by the very small board and by nearby parts

### 3. The `8.5 dBm` cap helps some boards, but not all in the same way

- `Board-1` became a more reliable transmitter with the cap
- `Board-3` also benefited from the cap
- `Board-2` performed best after hardware rework even without the cap

So the TX-power cap is best treated as a stabilization tool for marginal boards, not as the primary fix.

---

## Practical Ranking After The Rework

| Board | Receive result | Transmit result | Practical verdict |
|---|---|---|---|
| `Board-1` | Excellent receive with the external PCB antenna | Needs `8.5 dBm` cap to transmit reliably | Usable for experiments, but the antenna choice is still more experimental than the helix boards |
| `Board-2` | Good receive | Best transmit performance after `MIC5219` + helix changes | Best all-round board after rework |
| `Board-3` | Good receive | Still marginal at full power, but stable with `8.5 dBm` cap | Usable after rework, but still not as strong as `Board-2` |

---

## Final Conclusion

These tests support the following conclusions:

- some ESP32-C3 Super Mini boards ship with weak or unstable onboard LDOs
- the stock ceramic antenna arrangement is a weak point of the design
- moving to a larger antenna and, in some cases, lowering WiFi transmit power can make the boards much more usable
- the boards can be made serviceable for prototyping after rework, but they are still not ideal candidates for a reliable consumer product

For production-oriented hardware, a certified ESP32 module remains the safer choice. For prototype work, modified Super Mini boards can still be usable when:

- the board has a stable LDO
- the antenna implementation has been corrected
- the WiFi transmit-power cap is applied only where the hardware actually needs it

---

## Learning Resources / References

- [ESP32-C3 SuperMini Antenna Modification Guide](https://peterneufeld.wordpress.com/2025/03/04/esp32-c3-supermini-antenna-modification/)

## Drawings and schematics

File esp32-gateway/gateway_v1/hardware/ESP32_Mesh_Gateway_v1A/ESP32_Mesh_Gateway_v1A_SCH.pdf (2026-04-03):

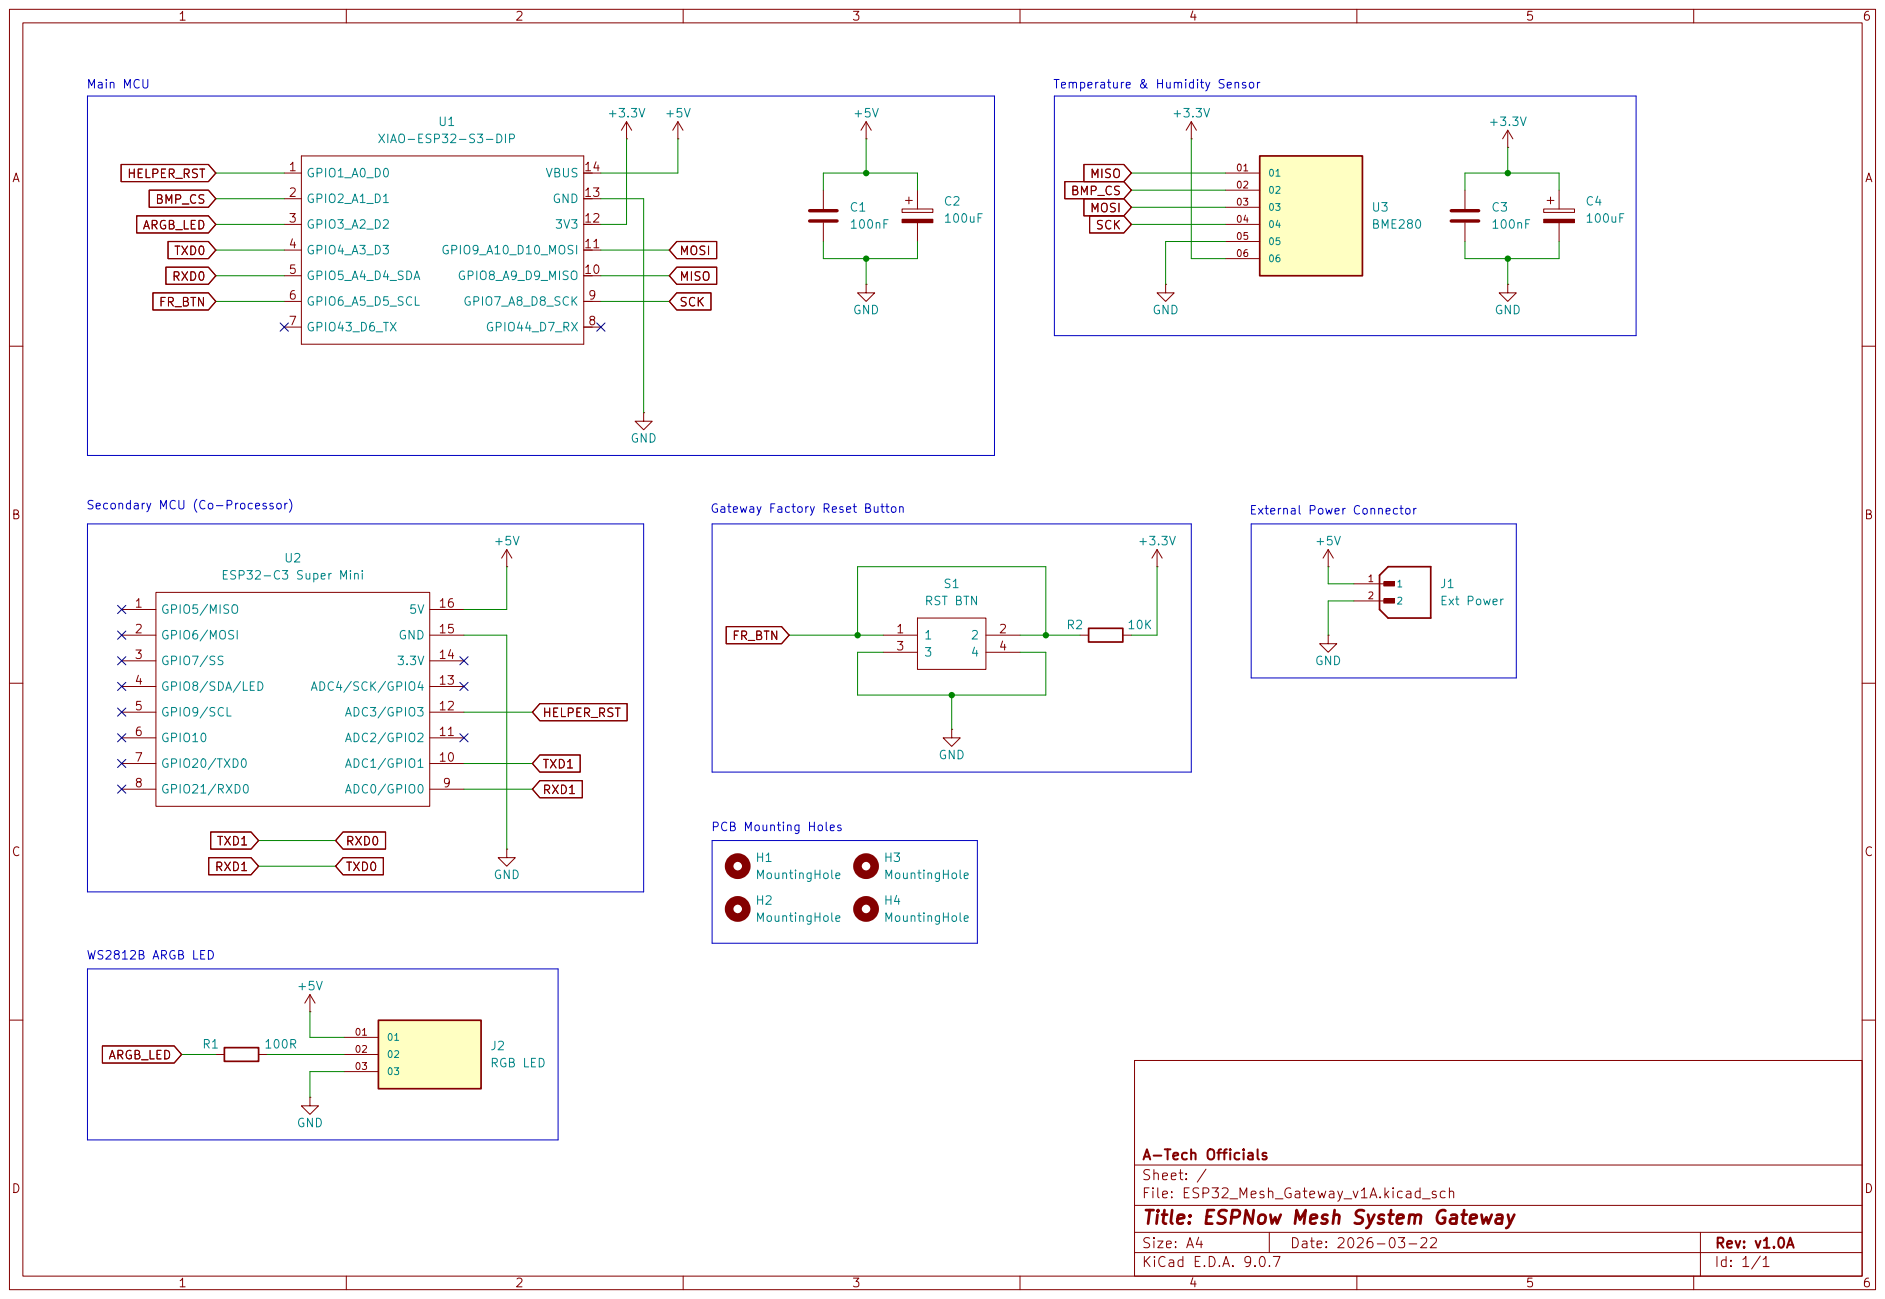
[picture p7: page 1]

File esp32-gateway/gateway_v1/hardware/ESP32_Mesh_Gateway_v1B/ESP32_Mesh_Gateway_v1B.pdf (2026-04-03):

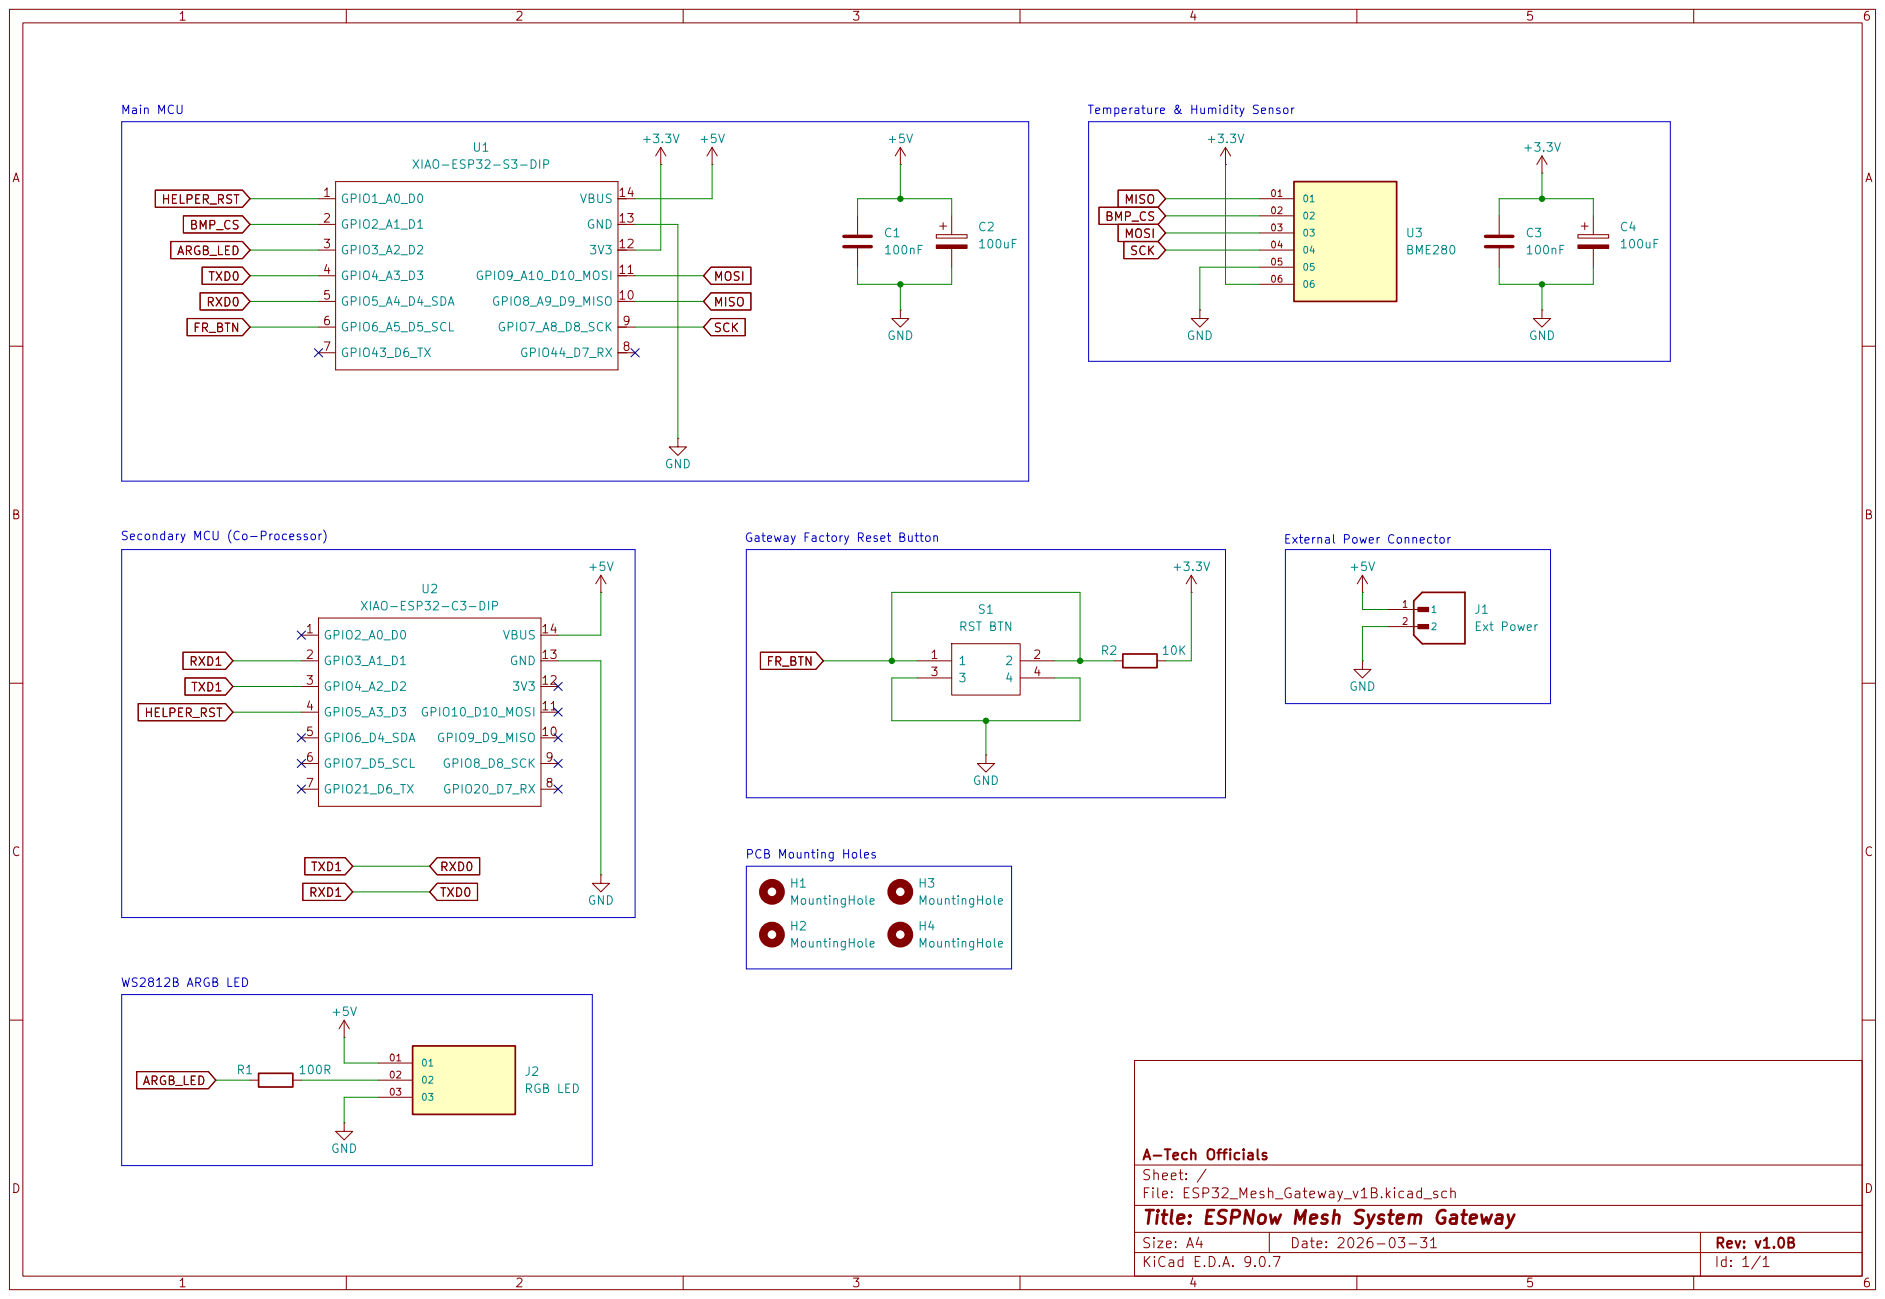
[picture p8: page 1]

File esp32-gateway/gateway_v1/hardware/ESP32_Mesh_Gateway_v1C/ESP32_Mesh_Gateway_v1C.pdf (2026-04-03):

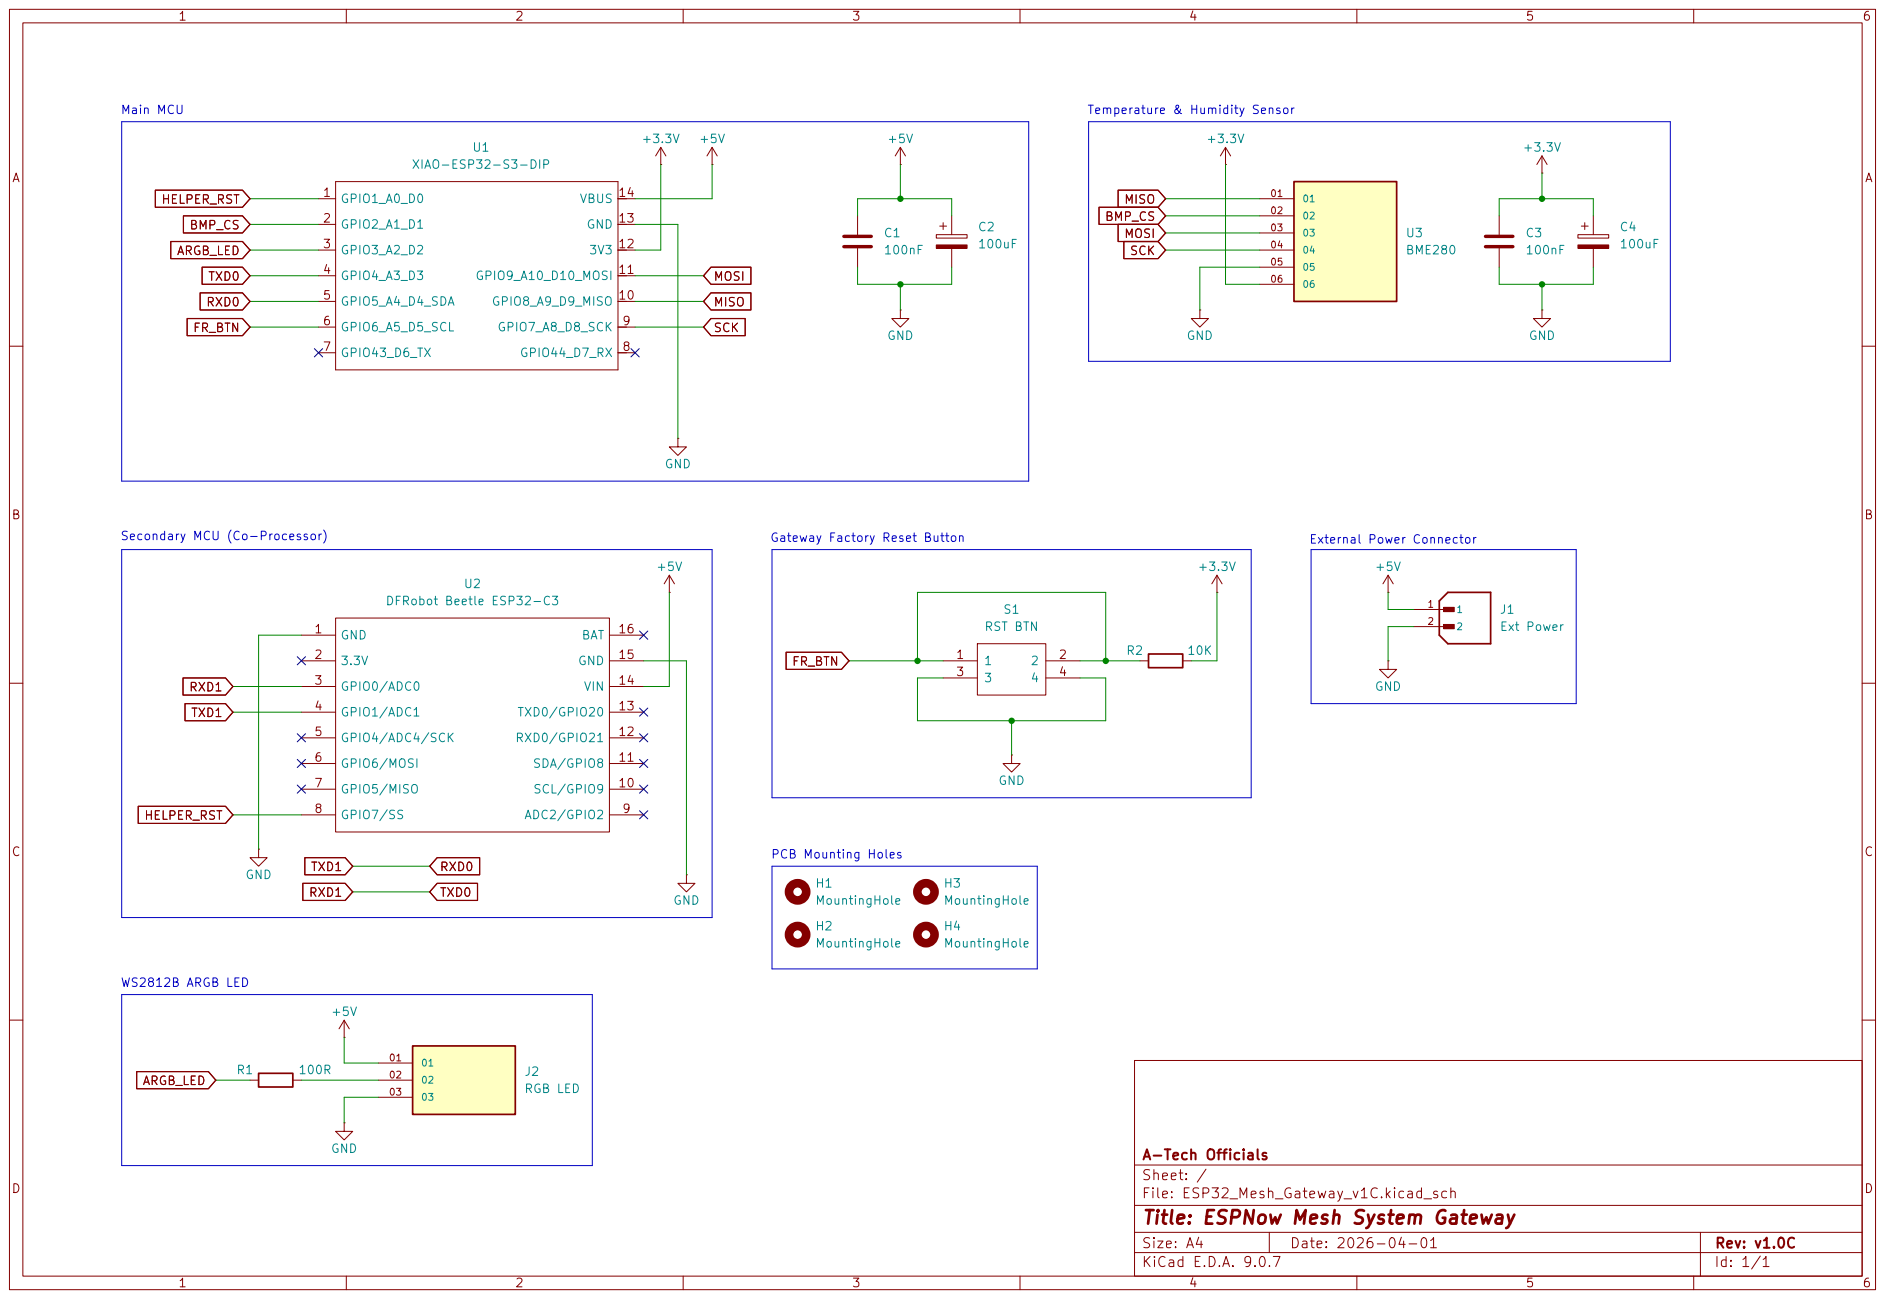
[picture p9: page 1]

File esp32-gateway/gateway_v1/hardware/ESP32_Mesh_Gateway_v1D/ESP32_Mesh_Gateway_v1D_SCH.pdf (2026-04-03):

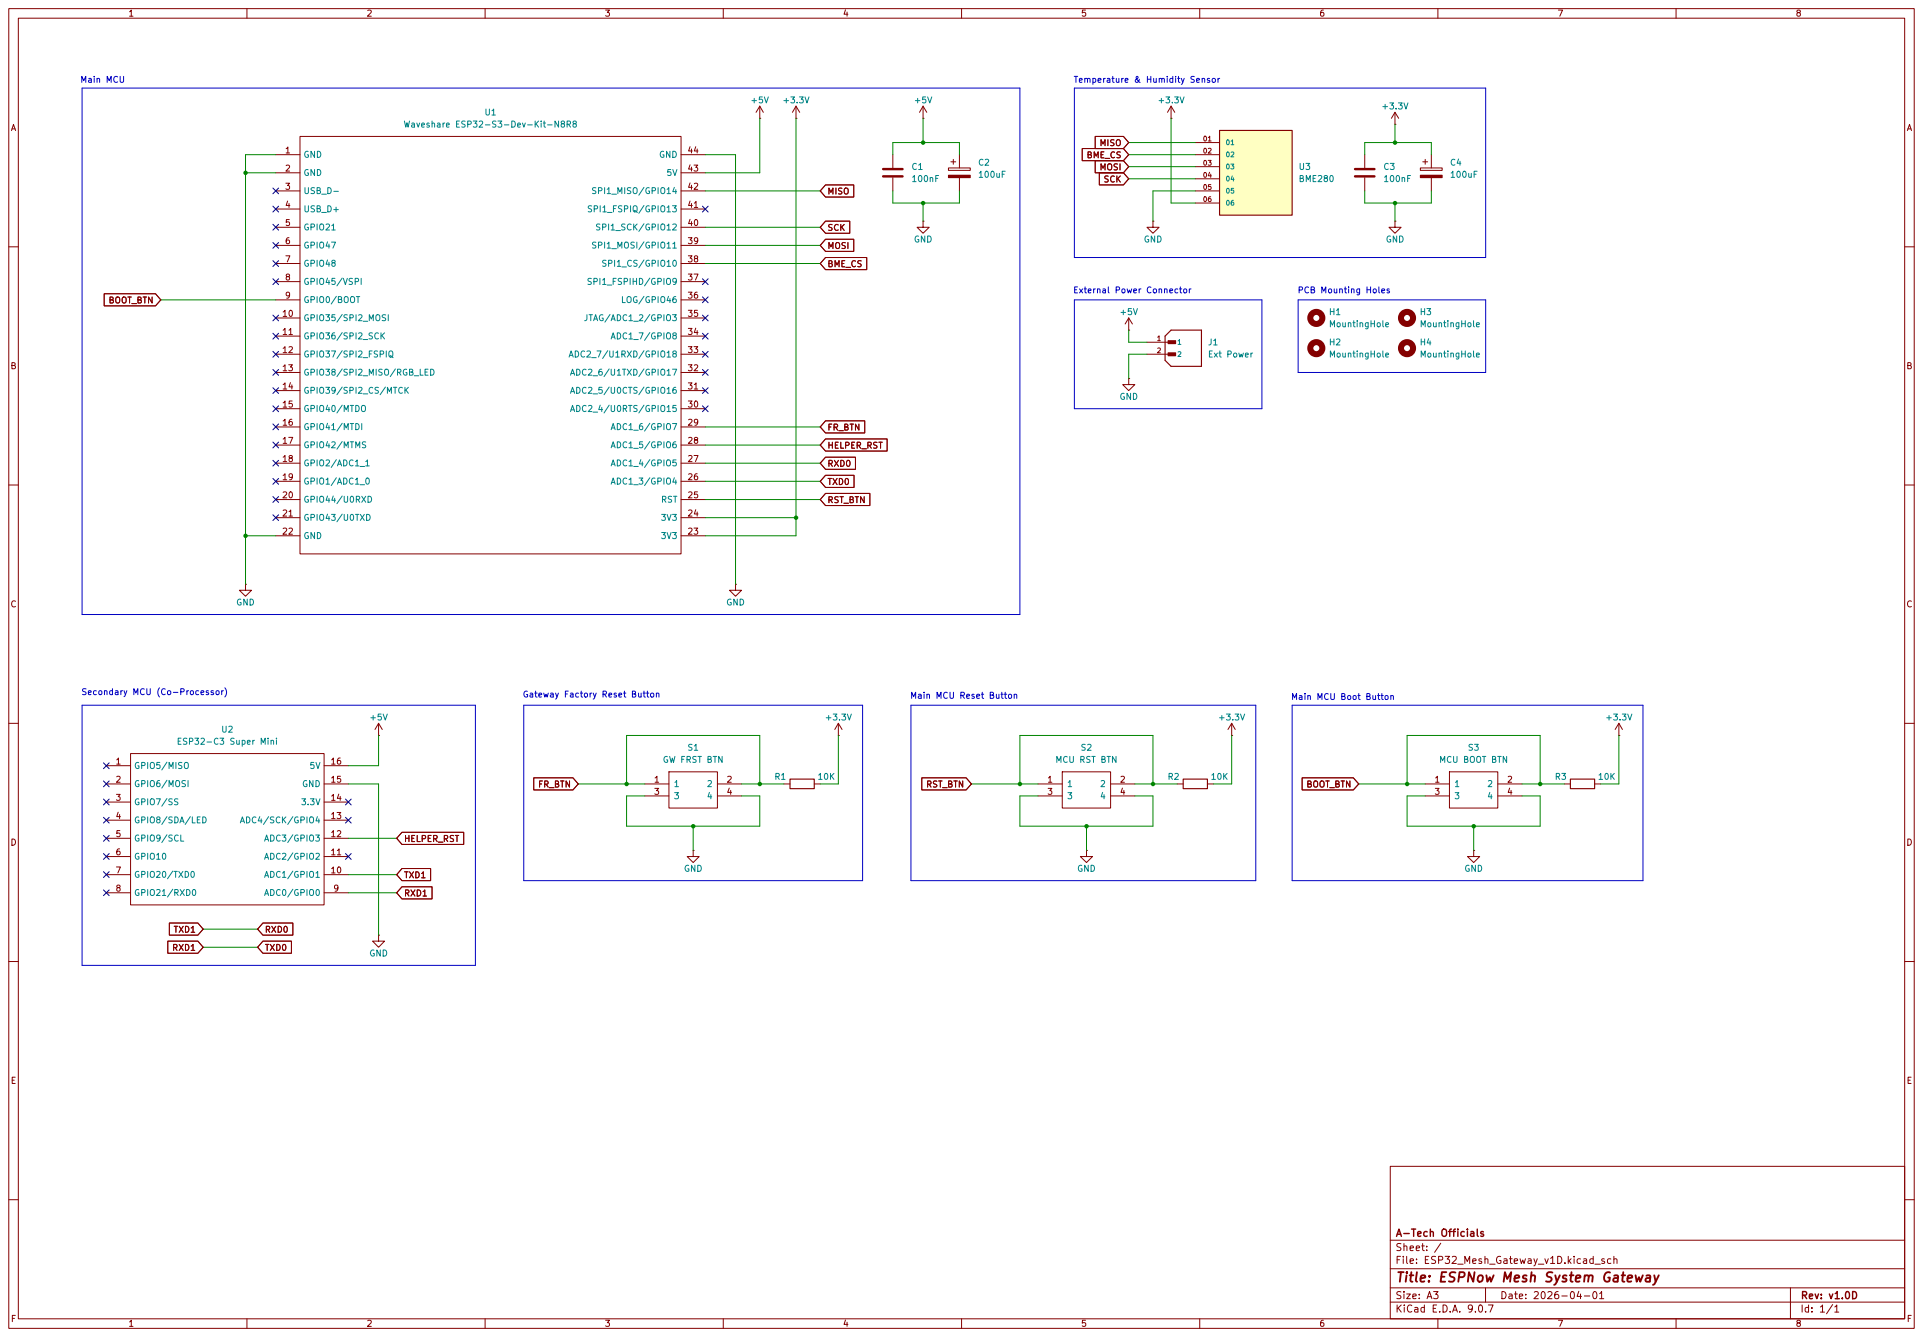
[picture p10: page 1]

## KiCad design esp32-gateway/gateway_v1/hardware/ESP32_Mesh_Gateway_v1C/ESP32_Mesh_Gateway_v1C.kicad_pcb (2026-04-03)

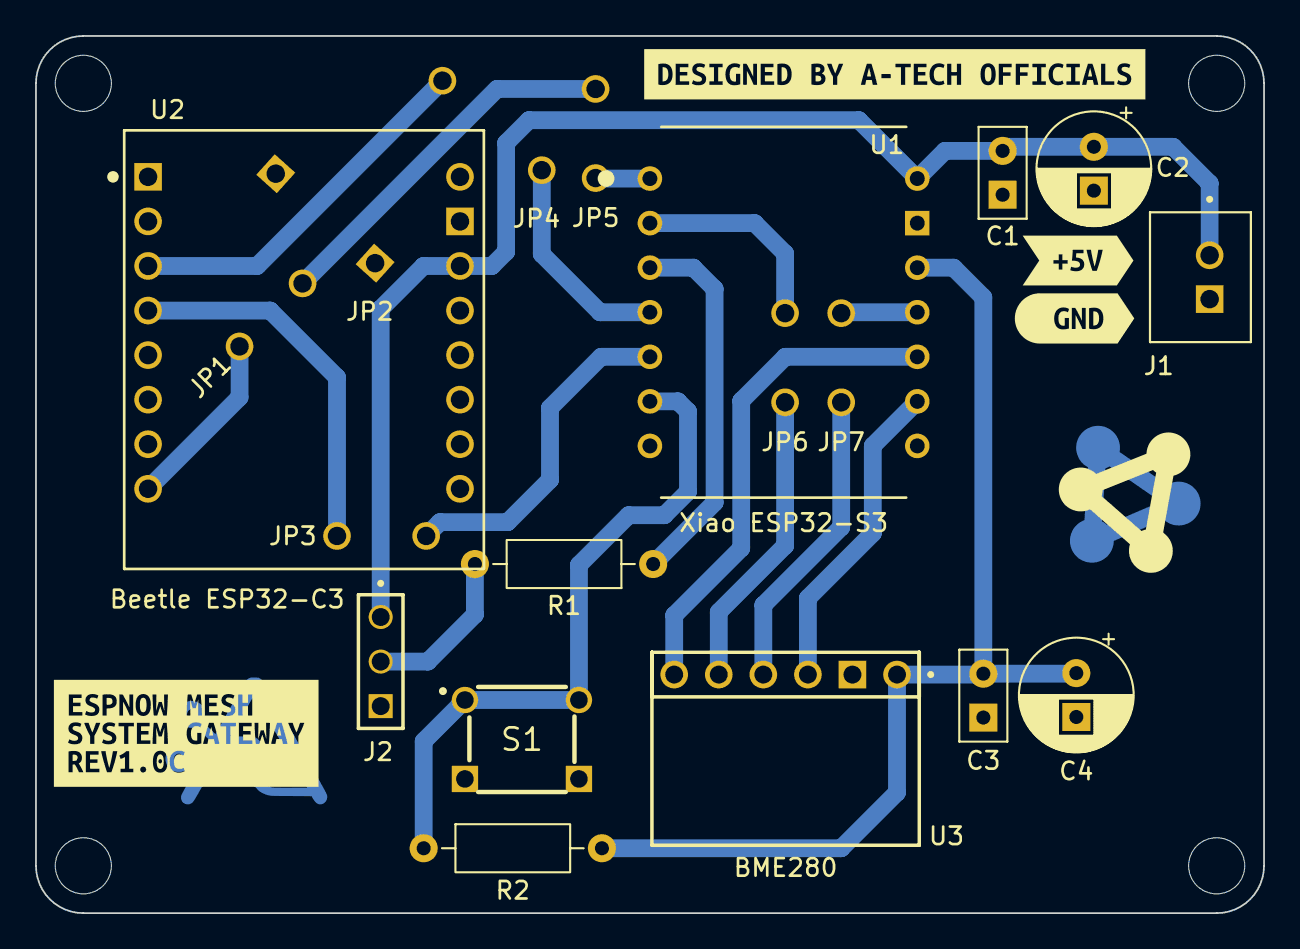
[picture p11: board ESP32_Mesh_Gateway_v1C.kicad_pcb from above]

Board: 2 copper layers, 70.0 x 50.0 mm, 27 parts (0 on the bottom side), 13 nets.

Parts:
C1, C3: 100nF; C_Disc_D5.0mm_W2.5mm_P2.50mm
C2, C4: 100uF; CP_Radial_D6.3mm_P2.50mm
H1, H2, H3, H4: MountingHole; MountingHole_3.2mm_M3_DIN965
J1: Ext Power; B2B-XH-A__LF__SN_
J2: RGB LED; SAMTEC_TSW-103-07-G-S
JP1, JP3, JP5, JP6, JP7: 2H_Jumper_P5.08mm; 2H_Jumper_P5.08
JP2, JP4: 2H_Jumper_P7.62mm
R1: 100R; R_Axial_DIN0207_L6.3mm_D2.5mm_P10.16mm_Horizontal
R2: 10K; R_Axial_DIN0207_L6.3mm_D2.5mm_P10.16mm_Horizontal
S1: RST BTN; FSM4JH
U1: XIAO-ESP32-S3-DIP; Xiao ESP32-S3 THT
U2: DFRobot Beetle ESP32-C3; DFRobot_Beetle_ESP32-C3
U3: BME280; BME280_Module
kibuzzard-69C035C1: G***; kibuzzard-69C035C1
kibuzzard-69C036F1: G***; kibuzzard-69C036F1
kibuzzard-69C03701: G***; kibuzzard-69C03701
kibuzzard-69CC23E0: G***; kibuzzard-69CC23E0

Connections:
+3.3V: C3.1, C4.1, R2.2, U1.12 (3V3), U3.06
+5V: C1.1, C2.1, J1.1, J2.01, U1.14 (VBUS), U2.14 (VIN)
ARGB_LED: R1.1, U1.3 (GPIO3_A2_D2)
BMP_CS: JP6.1, JP6.2, U1.2 (GPIO2_A1_D1), U3.02
FR_BTN: R2.1, S1.1, S1.2, U1.6 (GPIO6_A5_D5_SCL)
GND: C1.2, C2.2, C3.2, C4.2, J1.2, J2.03, JP2.1, JP2.2, S1.3, S1.4, U1.13 (GND), U2.1 (GND), U2.15 (GND), U3.05
HELPER_RST: JP1.1, JP1.2, JP5.1, JP5.2, U1.1 (GPIO1_A0_D0), U2.8 (GPIO7/SS)
MISO: U1.10 (GPIO8_A9_D9_MISO), U3.01
MOSI: JP7.1, JP7.2, U1.11 (GPIO9_A10_D10_MOSI), U3.03
unnamed: J2.02, R1.2
RXD0: JP3.1, JP3.2, U1.5 (GPIO5_A4_D4_SDA), U2.4 (GPIO1/ADC1)
RXD1: JP4.1, JP4.2, U1.4 (GPIO4_A3_D3), U2.3 (GPIO0/ADC0)
SCK: U1.9 (GPIO7_A8_D8_SCK), U3.04

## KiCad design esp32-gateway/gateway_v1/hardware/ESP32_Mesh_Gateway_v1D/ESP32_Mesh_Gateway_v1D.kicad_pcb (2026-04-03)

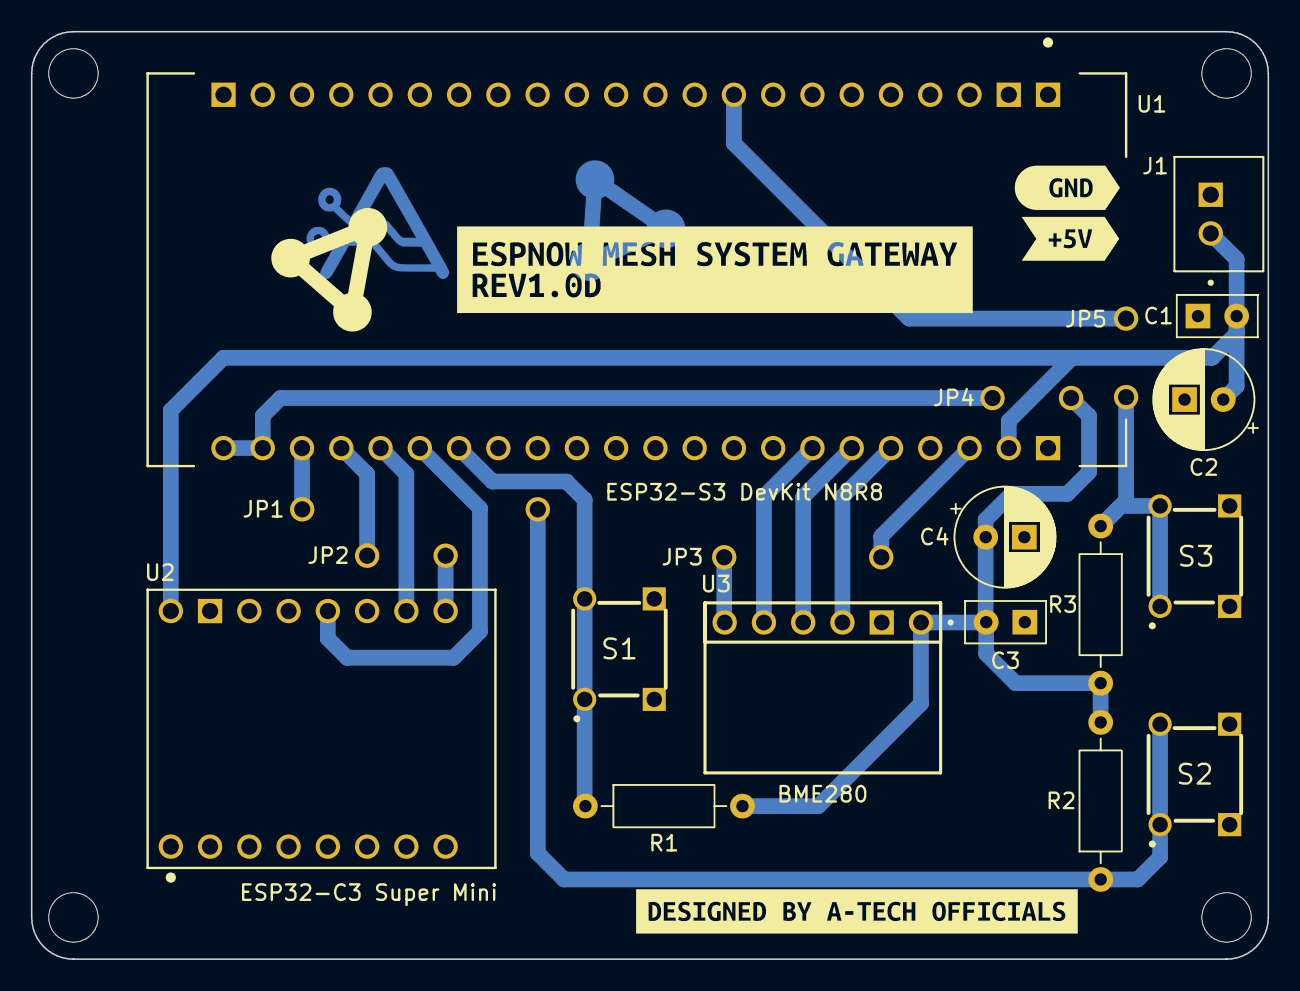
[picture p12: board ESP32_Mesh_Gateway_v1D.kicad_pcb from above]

Board: 2 copper layers, 80.0 x 60.0 mm, 27 parts (0 on the bottom side), 13 nets.

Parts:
C1, C3: 100nF; C_Disc_D5.0mm_W2.5mm_P2.50mm
C2, C4: 100uF; CP_Radial_D6.3mm_P2.50mm
H1, H2, H3, H4: MountingHole; MountingHole_3.2mm_M3_DIN965
J1: Ext Power; B2B-XH-A__LF__SN_
JP1: 2H_Jumper_P15.24mm
JP2, JP4, JP5: 2H_Jumper_P5.08mm
JP3: 2H_Jumper_P10.16mm
R1, R2, R3: 10K; R_Axial_DIN0207_L6.3mm_D2.5mm_P10.16mm_Horizontal
S1: GW FRST BTN; FSM4JH
S2: MCU RST BTN; FSM4JH
S3: MCU BOOT BTN; FSM4JH
U1: Waveshare ESP32-S3-Dev-Kit-N8R8; Waveshare_ESP32-S3_DevKit_N8R8
U2: ESP32-C3 Super Mini; ESP32-C3_Super_Mini
U3: BME280; BME280_Module
kibuzzard-69C035C1: G***; kibuzzard-69C035C1
kibuzzard-69C036F1: G***; kibuzzard-69C036F1
kibuzzard-69C03701: G***; kibuzzard-69C03701
kibuzzard-69CCEF25: G***; kibuzzard-69CCEF25

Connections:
+3.3V: C3.1, C4.1, JP4.1, JP4.2, R1.2, R2.2, R3.2, U1.23 (3V3), U1.24 (3V3), U3.06
+5V: C1.1, C2.1, J1.1, U1.43 (5V), U2.16 (5V)
BME_CS: U1.38 (SPI1_CS/GPIO10), U3.02
BOOT_BTN: JP5.1, JP5.2, R3.1, S3.1, S3.2, U1.9 (GPIO0/BOOT)
FR_BTN: R1.1, S1.1, S1.2, U1.29 (ADC1_6/GPIO7)
GND: C1.2, C2.2, C3.2, C4.2, J1.2, S1.3, S1.4, S2.3, S2.4, S3.3, S3.4, U1.1 (GND), U1.2 (GND), U1.22 (GND), U1.44 (GND), U2.15 (GND), U3.05
HELPER_RST: U1.28 (ADC1_5/GPIO6), U2.12 (ADC3/GPIO3)
MISO: JP3.1, JP3.2, U1.42 (SPI1_MISO/GPIO14), U3.01
MOSI: U1.39 (SPI1_MOSI/GPIO11), U3.03
RST_BTN: JP1.1, JP1.2, R2.1, S2.1, S2.2, U1.25 (RST)
RXD0: U1.27 (ADC1_4/GPIO5), U2.10 (ADC1/GPIO1)
RXD1: JP2.1, JP2.2, U1.26 (ADC1_3/GPIO4), U2.9 (ADC0/GPIO0)
SCK: U1.40 (SPI1_SCK/GPIO12), U3.04

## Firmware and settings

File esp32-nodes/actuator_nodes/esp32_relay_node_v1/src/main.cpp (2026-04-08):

/**
    * @file [main.cpp]
    * @brief Main source file for the ESP32 Mesh Actuator Relay Node firmware
    * @details ESP-NOW based mesh relay node for controlling 4 relays and reporting button state, with WS2812B LED status indicator.
    *        Designed for use with a central gateway node that manages pairing and communication.
    * 
    *        Features:
    *          - C++20 codebase for modern programming features and improved readability.
    *          - Uses Preferences library for non-volatile storage of pairing information.
    *          - Implements a simple state machine to manage node states (unpaired, pairing, paired, etc.).
    *          - Controls 4 relays via GPIO pins and reports their state back to the gateway.
    *          - Monitors a pairing button with debounce logic and long-press detection for entering pairing mode.
    *          - Uses a WS2812B LED to indicate node status (e.g., unpaired, paired, error states).
    *          - Implements a simple touch input handling for toggling relays, with debounce logic.
    * 
    *        Note: This code is intended as a starting point and may require adjustments based on specific hardware configurations and requirements.
    * @version 1.3.1
    * @author Mrinal (@atechofficials)
 */
#define FW_VERSION "1.3.1"

#include <Arduino.h>
#include <WiFi.h>
#include <HTTPClient.h>
#include <esp_now.h>
#include <esp_mac.h>
#include <esp_wifi.h>
#include <Preferences.h>
#include <Adafruit_NeoPixel.h>
#include <Update.h>
#include <ArduinoJson.h>
#include "mesh_protocol.h"
#include "user_config.h"

// Node state machine
enum NodeState { STATE_UNPAIRED, STATE_PAIRING, STATE_PAIRED, STATE_DISC_PEND, STATE_GW_LOST };
static NodeState nodeState = STATE_UNPAIRED;

// Globals
static uint8_t  masterMac[6] = {0};
static uint8_t  myNodeId     = 0;
static uint8_t  myChannel    = 0;
static bool     hasMaster    = false;
static bool     masterAcked  = false;
static unsigned long lastReReg = 0;

static bool relayState[RELAY_COUNT] = {0,0,0,0};
static uint8_t lastRelayState[RELAY_COUNT] = {255,255,255,255};
static const uint8_t relayPins[RELAY_COUNT] = {RELAY1_PIN, RELAY2_PIN, RELAY3_PIN, RELAY4_PIN};
static const uint8_t touchPins[RELAY_COUNT] = {TOUCH1_PIN, TOUCH2_PIN, TOUCH3_PIN, TOUCH4_PIN};

static Adafruit_NeoPixel led(LED_COUNT, LED_PIN, NEO_GRB + NEO_KHZ800);
static Preferences       prefs;

// LED state
static uint32_t     ledCurrent    = 0xDEADBEEF;
static unsigned long ledFlashUntil = 0;

// Button state
static bool          btnWasDown      = false;
static unsigned long btnPressedAt    = 0;
static bool          phase2Shown     = false;

// Pairing state
static unsigned long pairingStarted  = 0;
static uint8_t       pairingChannel  = 1;
static unsigned long lastBeacon      = 0;

// Runtime default name. We append the last two bytes of the Wi-Fi STA MAC
// so newly flashed nodes are easier to distinguish during first pairing.
static char gNodeName[MESH_NODE_NAME_LEN] = {0};

static void buildDefaultNodeName() {
    uint8_t mac[6] = {0};
    if (esp_read_mac(mac, ESP_MAC_WIFI_STA) != ESP_OK) {
        strncpy(gNodeName, NODE_NAME, sizeof(gNodeName) - 1);
        gNodeName[sizeof(gNodeName) - 1] = '\0';
        return;
    }

    char suffix[6];
    snprintf(suffix, sizeof(suffix), "%02X:%02X", mac[4], mac[5]);

    const size_t suffixLen = strlen(suffix);
    const size_t maxBaseLen = (sizeof(gNodeName) - 1 > suffixLen + 1)
        ? (sizeof(gNodeName) - 1 - suffixLen - 1)
        : 0;

    snprintf(gNodeName, sizeof(gNodeName), "%.*s-%s", static_cast<int>(maxBaseLen), NODE_NAME, suffix);
}

static void applyBoardSpecificWifiTxPowerLimit() {
#ifdef ESP32C3_SUPER_MINI
    const bool txPowerApplied = WiFi.setTxPower(WIFI_POWER_8_5dBm);
    Serial.printf("[WIFI] TX power cap (8.5 dBm) -> %s\n", txPowerApplied ? "ok" : "failed");
#endif
}

// Timing state
static unsigned long lastHeartbeat   = 0;
static bool          touchRawState[RELAY_COUNT] = {0,0,0,0};
static bool          touchStableState[RELAY_COUNT] = {0,0,0,0};
static unsigned long touchChangedAt[RELAY_COUNT] = {0,0,0,0};

// Node Settings
static char relayLabel[RELAY_COUNT][16] =
{
  "Relay 1",
  "Relay 2",
  "Relay 3",
  "Relay 4"
};
static const char kNodeFirmwareRoleMarker[] = "NODETYPE:ACTUATOR";
static const char kNodeFirmwareVersionMarker[] = "NODEFWVER:" FW_VERSION;
static const char kNodeHardwareConfigMarker[] = "NODEHWCFG:" HW_CONFIG_ID;
static volatile uint32_t gNodeFirmwareMarkerChecksum = 0;
#define SETTING_ID_RELAY_PERSIST 0
#define SETTING_ID_LED_EN 1

static bool sRelayPersist = false;
static bool sSettingLedEn = true;

// Gateway-loss detection 
#define GW_LOST_THRESHOLD   3
#define RELAY_HEARTBEAT_INTERVAL_MS 15000UL
static volatile uint8_t txFailCount = 0;

struct PendingNodeOta {
    bool     pending = false;
    uint32_t sessionId = 0;
    uint32_t imageSize = 0;
    uint32_t imageCrc32 = 0;
    uint16_t port = 80;
    char     ssid[NODE_OTA_SSID_LEN] = {0};
    char     password[NODE_OTA_PASS_LEN] = {0};
    char     version[NODE_OTA_VERSION_LEN] = {0};
};

static PendingNodeOta pendingOta;
static bool otaRunning = false;

static void touchFirmwareMarkers() {
    uint32_t sum = 0;
    for (size_t i = 0; kNodeFirmwareRoleMarker[i] != '\0'; i++) sum += (uint8_t)kNodeFirmwareRoleMarker[i];
    for (size_t i = 0; kNodeFirmwareVersionMarker[i] != '\0'; i++) sum += (uint8_t)kNodeFirmwareVersionMarker[i];
    for (size_t i = 0; kNodeHardwareConfigMarker[i] != '\0'; i++) sum += (uint8_t)kNodeHardwareConfigMarker[i];
    gNodeFirmwareMarkerChecksum = sum;
}

// RX queue
struct RxPacket { uint8_t mac[6]; uint8_t data[250]; int len; };
static QueueHandle_t rxQueue;
static void sendActuatorState();

// *****************************************************************************
//  LED helpers
// *****************************************************************************
static void setLed(uint32_t color) {
    if (color == ledCurrent) return;
    ledCurrent = color;
    led.setPixelColor(0, color);
    led.show();
}

static void flashLed(uint32_t durationMs = 120) {
    ledFlashUntil = millis() + durationMs;
    setLed(led.Color(0, 255, 0));
    ledCurrent = 0xDEADBEEF;
}

static void updateLed() {
    unsigned long now = millis();

    if (!sSettingLedEn) {
        if (nodeState == STATE_PAIRING || nodeState == STATE_DISC_PEND) {
            // fall through
        } else {
            setLed(led.Color(0, 0, 0));
            return;
        }
    }

    if (now < ledFlashUntil) {
        uint32_t c = led.Color(0, 255, 0);
        if (ledCurrent != c) { ledCurrent = c; led.setPixelColor(0, c); led.show(); }
        return;
    }

    switch (nodeState) {
        case STATE_UNPAIRED:
            setLed(led.Color(255, 0, 0));
            break;
        case STATE_PAIRING: {
            bool on = ((now / 500) % 2) == 0;
            setLed(on ? led.Color(255, 255, 255) : led.Color(0, 0, 0));
            break;
        }
        case STATE_PAIRED:
            setLed(led.Color(0, 48, 0));
            break;
        case STATE_DISC_PEND: {
            bool on = ((now / 250) % 2) == 0;
            setLed(on ? led.Color(0, 0, 255) : led.Color(0, 0, 0));
            break;
        }
        case STATE_GW_LOST: {
            bool on = ((now / 900) % 2) == 0;
            setLed(on ? led.Color(255, 140, 0) : led.Color(0, 0, 0));
            break;
        }
    }
}
// *****************************************************************************
//  Relay helpers
// *****************************************************************************
// Saves the state of a relay to NVS for persistence across reboots.
static void buildRelayStateKey(uint8_t id, char* key, size_t keyLen)
{
    snprintf(key, keyLen, "r%u", (unsigned)id);
}

static void saveRelayState(uint8_t id, bool state)
{
    char key[8];
    buildRelayStateKey(id, key, sizeof(key));
    prefs.begin("relay", false);
    prefs.putBool(key, state);
    prefs.end();
    // For Debugging: print saved relay state info to Serial Monitor
    Serial.printf("[NVS]  Saved relay %d state: %s\n", id, state ? "ON" : "OFF");
}

void setRelay(uint8_t id, bool state, bool persistState = true)
{
    if(id >= RELAY_COUNT) return;

    relayState[id] = state;
    const uint8_t pin = relayPins[id];
    
    if (relay_active_high) {
        digitalWrite(pin, state ? HIGH : LOW); // active HIGH relay
    } 
    else {
        digitalWrite(pin, state ? LOW : HIGH); // active LOW relay
    }

    if (persistState && sRelayPersist) {
        // For Debugging: print relay state persistence info to Serial Monitor
        Serial.printf("[RELAY STATE]  Relay State Peristence Enabled - Saving state of Relay %d: %s\n", id, state ? "ON" : "OFF");
        saveRelayState(id, state);
    }
    // For Debugging: print relay output change info to Serial Monitor
    Serial.printf("[RELAY STATE]  Set Relay %d to %s\n", id, state ? "ON" : "OFF");
}

static void handleTouchInputs() {
    const unsigned long now = millis();

    for (uint8_t i = 0; i < RELAY_COUNT; i++) {
        const bool rawActive = (digitalRead(touchPins[i]) == HIGH);

        if (rawActive != touchRawState[i]) {
            touchRawState[i] = rawActive;
            touchChangedAt[i] = now;
        }

        if ((now - touchChangedAt[i]) < TOUCH_DEBOUNCE_MS) continue;
        if (touchStableState[i] == touchRawState[i]) continue;

        touchStableState[i] = touchRawState[i];
        if (!touchStableState[i]) continue;  // Toggle only on touch press, not release

        const bool newState = !relayState[i];
        setRelay(i, newState);
        Serial.printf("[TOUCH]  Touch %d toggled Relay %d -> %s\n",
                      i + 1, i + 1, newState ? "ON" : "OFF");

        if (nodeState == STATE_PAIRED || nodeState == STATE_DISC_PEND || nodeState == STATE_GW_LOST) {
            sendActuatorState();
        }
    }
}

// *****************************************************************************
//  ESP-NOW callbacks
// *****************************************************************************
static void onDataRecv(const esp_now_recv_info_t* info,
                       const uint8_t* data, int len) {
    RxPacket pkt;
    memcpy(pkt.mac, info->src_addr, 6);
    int l = (len < 250) ? len : 250;
    memcpy(pkt.data, data, l);
    pkt.len = l;
    xQueueSend(rxQueue, &pkt, 0);
    // For Debugging: print received packet info to Serial Monitor
    Serial.printf("[RX]  Packet received from %02X:%02X:%02X:%02X:%02X:%02X  len=%d\n",
                  info->src_addr[0], info->src_addr[1], info->src_addr[2],
                  info->src_addr[3], info->src_addr[4], info->src_addr[5],
                  len);
}

static void onDataSent(const wifi_tx_info_t* /*txInfo*/, esp_now_send_status_t status) {
    if (!hasMaster) {
        // For Debugging
        Serial.println("[ESP-NOW] Send callback received but no master known. Ignoring.");
        return;
    }
    if (status == ESP_NOW_SEND_SUCCESS) {
        // For Debugging
        Serial.println("[ESP-NOW] Send successful.");
        txFailCount = 0;
    } 
    else {
        // For Debugging
        Serial.println("[ESP-NOW] Send failed.");
        if (txFailCount < 255) txFailCount = txFailCount + 1;
    }
}

// *****************************************************************************
//  NVS helpers
// *****************************************************************************
static bool loadPreferences() {
  prefs.begin("mesh", true); // read-only
  myNodeId  = prefs.getUChar("node_id",  0);
  myChannel = prefs.getUChar("channel",  0);
  size_t ml = prefs.getBytes("master_mac", masterMac, sizeof(masterMac));
  prefs.end();
  bool macValid = false;
  for (int i = 0; i < 6; i++) {
    if (masterMac[i] != 0) { 
      macValid = true;
    }
  }
  // For Debugging: print loaded preferences to Serial Monitor
  Serial.printf("[NVS] Loaded: id=%d  ch=%d\n", myNodeId, myChannel);
  return (myNodeId > 0 && myChannel > 0 && ml == 6 && macValid);
}

static void savePreferences() {
    prefs.begin("mesh", false); // read-write
    prefs.putUChar("node_id",  myNodeId);
    prefs.putUChar("channel",  myChannel);
    prefs.putBytes("master_mac", masterMac, 6);
    prefs.end();
    // For Debugging: print saved preferences to Serial Monitor
    Serial.printf("[NVS] Saved: id=%d  ch=%d\n", myNodeId, myChannel);
}

static void clearPreferences() {
    prefs.begin("mesh", false); // read-write
    prefs.clear();
    prefs.end();
    // For Debugging: print cleared preferences info to Serial Monitor
    Serial.println("[NVS] Cleared.");
}

// *****************************************************************************
//  Settings NVS load / save and definition helpers
// *****************************************************************************
static void loadSettings() {
    prefs.begin("nodeconf", true);

    sRelayPersist = prefs.getBool("relay_persist", false);
    sSettingLedEn = prefs.getBool("led_en", true);
  
    prefs.end();
    // For Debugging: print loaded settings to Serial Monitor
    Serial.printf("[CFG] Settings Loaded: relay_persist=%d led_en=%d\n", 
                  (int)sRelayPersist, (int)sSettingLedEn);
}

static void saveSettings() {
    prefs.begin("nodeconf", false);
    
    prefs.putBool("relay_persist", sRelayPersist);
    prefs.putBool("led_en", sSettingLedEn);

    prefs.end();
    // For Debugging: print saved settings to Serial Monitor
    Serial.printf("[CFG] Settings saved. Current values: relay_persist=%d led_en=%d\n", 
                  (int)sRelayPersist, (int)sSettingLedEn);
}

static uint8_t getSettingsDefs(SettingDef out[NODE_MAX_SETTINGS]) {
    uint8_t i = 0;

    // Relay State Persistence
    if (i >= NODE_MAX_SETTINGS) return i;
    out[i].id = SETTING_ID_RELAY_PERSIST;
    out[i].type = SETTING_BOOL;
    strncpy(out[i].label, "StatePersist", SETTING_LABEL_LEN - 1);
    out[i].label[SETTING_LABEL_LEN - 1] = '\0';
    out[i].current = sRelayPersist ? 1 : 0;
    out[i].i_min = 0;
    out[i].i_max = 0;
    out[i].i_step = 0;
    out[i].opt_count = 0;
    memset(out[i].opts, 0, sizeof(out[i].opts));
    i++;

    // Node Status LED
    if (i >= NODE_MAX_SETTINGS) return i;
    out[i].id = SETTING_ID_LED_EN;
    out[i].type = SETTING_BOOL;
    strncpy(out[i].label, "Status LED", SETTING_LABEL_LEN - 1);
    out[i].label[SETTING_LABEL_LEN - 1] = '\0';
    out[i].current = sSettingLedEn ? 1 : 0;
    out[i].i_min = 0; 
    out[i].i_max = 0; 
    out[i].i_step = 0;
    out[i].opt_count = 0;
    memset(out[i].opts, 0, sizeof(out[i].opts));
    i++;

    // For Debugging: print settings definitions to Serial Monitor
    Serial.printf("[CFG] Defined %d settings.\n", i);
    return i;
}

static uint8_t getActuatorDefs(ActuatorDef out[NODE_MAX_ACTUATORS])
{
    uint8_t i = 0;

    for (; i < RELAY_COUNT; i++) {
        out[i].id = i;
        strncpy(out[i].label, relayLabel[i], ACTUATOR_LABEL_LEN - 1);
        out[i].label[ACTUATOR_LABEL_LEN - 1] = '\0';
    }

    // For Debugging: print loaded actuator definitions to Serial Monitor
    Serial.printf("[ACTUATOR] Defined %d actuators.\n", i);
    return i;
}
// *****************************************************************************
//  ESP-NOW peer helpers
// *****************************************************************************
static void addMasterPeer() {
    if (esp_now_is_peer_exist(masterMac)) return;
    esp_now_peer_info_t p = {};
    memcpy(p.peer_addr, masterMac, 6);
    p.channel = myChannel;
    p.encrypt = false;
    if (esp_now_add_peer(&p) == ESP_OK)
        Serial.println("[ESP-NOW] Master peer added.");
    else
        Serial.println("[ESP-NOW] Failed to add master peer!");
}

static void addBroadcastPeer(uint8_t channel) {
    uint8_t bcast[6] = {0xFF, 0xFF, 0xFF, 0xFF, 0xFF, 0xFF};
    if (esp_now_is_peer_exist(bcast)) esp_now_del_peer(bcast);
    esp_now_peer_info_t p = {};
    memcpy(p.peer_addr, bcast, 6);
    p.channel = channel;
    p.encrypt = false;
    esp_now_add_peer(&p);
    // For Debugging: print broadcast peer addition info to Serial Monitor
    Serial.printf("[ESP-NOW] Broadcast peer added on channel %d.\n", channel);
}

// *****************************************************************************
//  Message senders
// *****************************************************************************
static void sendBeacon() {
    MsgBeacon b;
    b.hdr.type      = MSG_BEACON;
    b.hdr.node_id   = 0;
    b.hdr.node_type = NODE_ACTUATOR;
    strncpy(b.name, gNodeName, sizeof(b.name) - 1);
    b.name[sizeof(b.name) - 1] = '\0';
    b.tx_channel    = pairingChannel;
    uint8_t bcast[6] = {0xFF, 0xFF, 0xFF, 0xFF, 0xFF, 0xFF};
    esp_now_send(bcast, (uint8_t*)&b, sizeof(b));
    Serial.printf("[PAIR]  Beacon -> ch%d\n", pairingChannel);
}

static void sendRegistration() {
    MsgRegister reg{};
    reg.hdr.type      = MSG_REGISTER;
    reg.hdr.node_id   = myNodeId;
    reg.hdr.node_type = NODE_ACTUATOR;
    strncpy(reg.name, gNodeName, sizeof(reg.name) - 1);
    reg.name[sizeof(reg.name) - 1] = '\0';
    strncpy(reg.fw_version, FW_VERSION, 7);
    reg.fw_version[7] = '\0';
    strncpy(reg.hw_config_id, HW_CONFIG_ID, sizeof(reg.hw_config_id) - 1);
    reg.hw_config_id[sizeof(reg.hw_config_id) - 1] = '\0';
    reg.capabilities = NODE_CAP_ACTUATORS;
    esp_now_send(masterMac, (uint8_t*)&reg, sizeof(reg));
    // For Debugging: print sent registration info to Serial Monitor
    Serial.printf("[MSG]  Registration sent to master.\n Waiting for ACK...\n");
}

static void sendActuatorState()
{
    if (!hasMaster || myNodeId == 0) return;

    const uint8_t count = RELAY_COUNT;

    bool changed = false;

    for (uint8_t i = 0; i < count; i++)
    {
        if (relayState[i] != lastRelayState[i])
        {
            changed = true;
            break;
        }
    }

    if (!changed)
        return;

    MsgActuatorState msg{};

    msg.hdr.type = MSG_ACTUATOR_STATE;
    msg.hdr.node_id = myNodeId;
    msg.hdr.node_type = NODE_ACTUATOR;

    msg.count = count;

    for (uint8_t i = 0; i < count; i++)
    {
        msg.states[i].id = i;
        msg.states[i].state = relayState[i];
        lastRelayState[i] = relayState[i];
    }

    const size_t payloadLen =
        sizeof(MeshHeader) +
        sizeof(msg.count) +
        (count * sizeof(ActuatorState));

    esp_err_t r = esp_now_send(masterMac, (uint8_t*)&msg, payloadLen);
    // Flash LED on successful send only if LED is enabled in Node settings
    if (r == ESP_OK && sSettingLedEn) flashLed();

    // For Debugging: print sent actuator state info to Serial Monitor
    Serial.printf("[ACTUATOR]  Actuator state sent to master. %d relays, (%u B)\n", count, (unsigned)payloadLen);
    
    Serial.printf("  %s\n", r == ESP_OK ? "ok" : "error");
}

static void sendActuatorSchemaData()
{
    if(!hasMaster || myNodeId == 0) return;

    MsgActuatorSchema msg{};

    msg.hdr.type = MSG_ACTUATOR_SCHEMA;
    msg.hdr.node_id = myNodeId;
    msg.hdr.node_type = NODE_ACTUATOR;
    msg.count = getActuatorDefs(msg.actuators);

    const size_t payloadLen =
        sizeof(MeshHeader) +
        sizeof(msg.count) +
        msg.count * sizeof(ActuatorDef);

    esp_err_t r = esp_now_send(masterMac, (uint8_t*)&msg, payloadLen);

    // For Debugging: print sent actuator schema info to Serial Monitor
    Serial.printf("[ACTUATOR]  Sent actuator schema to master. %d actuator(s), (%u B) ->\n", msg.count, (unsigned)payloadLen);

    Serial.printf("  %s\n", r == ESP_OK ? "ok" : "error");
}

static void sendHeartbeat() {
    if (!hasMaster || myNodeId == 0) return;
    MsgHeartbeat hb;
    hb.hdr.type      = MSG_HEARTBEAT;
    hb.hdr.node_id   = myNodeId;
    hb.hdr.node_type = NODE_ACTUATOR;
    hb.uptime_sec    = millis() / 1000;
    
    esp_err_t r = esp_now_send(masterMac, (uint8_t*)&hb, sizeof(hb));
    // Flash LED on successful send only if LED is enabled in Node settings
    if (r == ESP_OK && sSettingLedEn) flashLed();
    
    // For Debugging: print sent heartbeat info to Serial Monitor
    Serial.printf("[ACTUATOR]  Heartbeat sent to master (uptime: %d sec) ->\n", hb.uptime_sec);
    Serial.printf("  %s\n", r == ESP_OK ? "ok" : "error");
}
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
void loop() {
    unsigned long now = millis();

    runPendingOta();
    handleButton();
    handleTouchInputs();
    processRxQueue();
    now = millis();

    if (nodeState == STATE_PAIRED && txFailCount >= GW_LOST_THRESHOLD) {
        nodeState   = STATE_GW_LOST;
        masterAcked = false;
        lastReReg   = now;
        txFailCount = 0;
        Serial.println("[MESH]  Gateway unreachable - pausing sends, re-registering...");
    }
    updateLed();

    if (nodeState == STATE_PAIRING) {
        if (now - pairingStarted >= PAIRING_TIMEOUT_MS) {
            nodeState = STATE_UNPAIRED;
            uint8_t bcast[6] = {0xFF, 0xFF, 0xFF, 0xFF, 0xFF, 0xFF};
            if (esp_now_is_peer_exist(bcast)) esp_now_del_peer(bcast);
            Serial.println("[PAIR]  Timeout - exited pairing mode.");
        } 
        else if (now - lastBeacon >= BEACON_INTERVAL) {
            lastBeacon = now;
            esp_wifi_set_channel(pairingChannel, WIFI_SECOND_CHAN_NONE);
            addBroadcastPeer(pairingChannel);
            sendBeacon();
            pairingChannel = (pairingChannel % 13) + 1;
        }
    }

    if (nodeState == STATE_PAIRED || nodeState == STATE_DISC_PEND) {
        if (now - lastHeartbeat >= RELAY_HEARTBEAT_INTERVAL_MS) {
            lastHeartbeat = now;
            sendHeartbeat();
        }
    }

    if ((nodeState == STATE_PAIRED || nodeState == STATE_GW_LOST) &&
        hasMaster && !masterAcked && (now - lastReReg >= 5000)) {
        lastReReg = now;
        Serial.println("[PAIR]  No ACK - re-sending registration...");
        sendRegistration();
    }

    delay(50);
}

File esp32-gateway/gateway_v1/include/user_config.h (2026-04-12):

#pragma once

/**
    * @file [user_config.h]
    * @brief Shared definitions for the ESP32 Mesh Gateway Firmware
    * @version 1.1.3
    * @author Mrinal (@atechofficials)
 */

// Gateway User Configurations
#define AP_SSID_DEFAULT  "ESP32-Mesh-Gateway"
#define AP_PASS_DEFAULT  "meshsetup"
#define OFFLINE_AP_SSID_DEFAULT "ESP32-Mesh-Offline"
#define OFFLINE_AP_PASS_DEFAULT "meshoffline"
#define OFFLINE_AP_DEFAULT_CHANNEL 6
#define NODE_OTA_HOST "192.168.4.1"

// Optional gateway built-in room environment sensor feature.
// 0 = disabled, 1 = enabled. When enabled, firmware auto-detects BMP280 vs BME280 at runtime.
#ifndef GATEWAY_BUILTIN_SENSOR_ENABLED
    #define GATEWAY_BUILTIN_SENSOR_ENABLED 0 // Default to disabled if not defined from platformio.ini build_flags.
#endif

// Select Main Dev Board
// These can be provided from platformio.ini build_flags per environment.
#if !defined(ESP32_S3_DEVKITC1) && !defined(XIAO_ESP32_S3)
    #define ESP32_S3_DEVKITC1
#endif

#if defined(ESP32_S3_DEVKITC1) && defined(XIAO_ESP32_S3)
    #error "Select only one gateway main dev board."
#endif

// Select Coprocessor Dev Board
// These can be provided from platformio.ini build_flags per environment.
#if !defined(COPROC_ESP32C3_BEETLE) && !defined(COPROC_ESP32C3_XIAO) && !defined(COPROC_ESP32C3_SUPER_MINI)
    #define COPROC_ESP32C3_BEETLE
#endif

#if (defined(COPROC_ESP32C3_BEETLE) && defined(COPROC_ESP32C3_XIAO)) || \
    (defined(COPROC_ESP32C3_BEETLE) && defined(COPROC_ESP32C3_SUPER_MINI)) || \
    (defined(COPROC_ESP32C3_XIAO) && defined(COPROC_ESP32C3_SUPER_MINI))
    #error "Select only one gateway coprocessor dev board."
#endif

#ifdef ESP32_S3_DEVKITC1
    #ifdef COPROC_ESP32C3_BEETLE
        #define HW_CONFIG_ID "0x0A"
    #elif defined(COPROC_ESP32C3_XIAO)
        #define HW_CONFIG_ID "0x1A"
    #elif defined(COPROC_ESP32C3_SUPER_MINI)
        #define HW_CONFIG_ID "0x2A"
    #endif
    #define RESET_BTN_PIN    7
    #define GW_LED_PIN       38
    #define GW_LED_COL_ORDER NEO_RGB
    #define COPROC_UART_TX_PIN 4
    #define COPROC_UART_RX_PIN 5
    #define COPROC_RESET_PIN 6
    #define BME_SCK  12
    #define BME_MISO 14
    #define BME_MOSI 11
    #define BME_CS   10
#elif defined (XIAO_ESP32_S3)
    #ifdef COPROC_ESP32C3_BEETLE
        #define HW_CONFIG_ID "0x3A"
    #elif defined(COPROC_ESP32C3_XIAO)
        #define HW_CONFIG_ID "0x4A"
    #elif defined(COPROC_ESP32C3_SUPER_MINI)
        #define HW_CONFIG_ID "0x5A"
    #endif
    #define RESET_BTN_PIN    6
    #define GW_LED_PIN       3
    #define GW_LED_COL_ORDER NEO_GRB
    #define COPROC_UART_TX_PIN 4
    #define COPROC_UART_RX_PIN 5
    #define COPROC_RESET_PIN 1
    #define BME_SCK  7
    #define BME_MISO 8
    #define BME_MOSI 9
    #define BME_CS   2
#endif

#if (GATEWAY_BUILTIN_SENSOR_ENABLED != 0) && (GATEWAY_BUILTIN_SENSOR_ENABLED != 1)
    #error "GATEWAY_BUILTIN_SENSOR_ENABLED must be 0 or 1."
#endif

// Coprocessor board-specific hardware config ID used by coprocessor OTA firmware validation.
// This intentionally identifies the ESP32-C3 helper board itself, not the full gateway combo.
#ifdef COPROC_ESP32C3_BEETLE
    #define COPROC_HW_CONFIG_ID "0x0B"
#elif defined(COPROC_ESP32C3_XIAO)
    #define COPROC_HW_CONFIG_ID "0x1B"
#elif defined(COPROC_ESP32C3_SUPER_MINI)
    #define COPROC_HW_CONFIG_ID "0x2B"
#endif

// Coprocessor UART Configuration
#ifdef COPROC_ESP32C3_BEETLE
    #define UART_TX_PIN 1
    #define UART_RX_PIN 0
    #define REBOOT_SIGNAL_PIN 7
#elif defined(COPROC_ESP32C3_XIAO)
    #define UART_TX_PIN 4
    #define UART_RX_PIN 3
    #define REBOOT_SIGNAL_PIN 5
#elif defined(COPROC_ESP32C3_SUPER_MINI)
    #define UART_TX_PIN 1
    #define UART_RX_PIN 0
    #define REBOOT_SIGNAL_PIN 3
#endif

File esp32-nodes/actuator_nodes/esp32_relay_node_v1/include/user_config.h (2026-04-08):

#pragma once

/**
    * @file [user_config.h]
    * @brief Shared definitions for the ESP32 Actuator Relay Node Firmware
    * @version 1.0.1
    * @author Mrinal (@atechofficials)
 */

// Actuator Node User Configurations
#define NODE_NAME       "Relay-Node"   // change per node (max 24 chars)

// Dev Board Selection
#if !defined(ESP32_DEVKITC) && !defined(ESP32C3_WROOM) && !defined(ESP32C6_WROOM)
    #define ESP32_DEVKITC
#endif

#if defined(ESP32_DEVKITC) && defined(ESP32C3_WROOM) && defined(ESP32C6_WROOM)
    #error "Select only one Actuator Relay Node dev board."
#endif

#ifdef ESP32_DEVKITC
    #define HW_CONFIG_ID "0x0C"
    #define RELAY_COUNT     4
    #define RELAY1_PIN      26    // Active LOW relay control pins - adjust as needed for your hardware setup
    #define RELAY2_PIN      27
    #define RELAY3_PIN      32
    #define RELAY4_PIN      33
    #define TOUCH1_PIN      25    // TTP224 touch sensor 1 (channels 1-4) - active HIGH, with external pull-downs to GND. Adjust pin numbers as needed for your hardware setup.
    #define TOUCH2_PIN      4     // TTP224 touch sensor 2
    #define TOUCH3_PIN      13    // TTP224 touch sensor 3
    #define TOUCH4_PIN      14    // TTP224 touch sensor 4
    #define PAIR_BTN_PIN    16    // Pairing button GPIO pin (active-LOW, uses internal pull-up)
    #define LED_PIN         22    // WS2812B data pin
    #define LED_COUNT       1     // Number of WS2812B LEDs on board
    #define TOUCH_DEBOUNCE_MS 35
    bool relay_active_high = false; // Set to true if your relay module is active HIGH, false if active LOW
#elif defined(ESP32C3_WROOM)
    #define HW_CONFIG_ID "0x1C"
    #define RELAY_COUNT     4
    #define RELAY1_PIN      3     // Active LOW relay control pins - adjust as needed for your hardware setup
    #define RELAY2_PIN      4
    #define RELAY3_PIN      5
    #define RELAY4_PIN      6
    #define TOUCH1_PIN      0     // TTP224 touch sensor 1 (channels 1-4) - active HIGH, with external pull-downs to GND. Adjust pin numbers as needed for your hardware setup.
    #define TOUCH2_PIN      1     // TTP224 touch sensor 2
    #define TOUCH3_PIN      7     // TTP224 touch sensor 3
    #define TOUCH4_PIN      10    // TTP224 touch sensor 4
    #define PAIR_BTN_PIN    19    // Pairing button GPIO pin (active-LOW, uses internal pull-up)
    #define LED_PIN         18    // WS2812B data pin
    #define LED_COUNT       1     // Number of WS2812B LEDs on board
    #define TOUCH_DEBOUNCE_MS 35
    bool relay_active_high = false; // Set to true if your relay module is active HIGH, false if active LOW
#elif defined(ESP32C6_WROOM)
    #define HW_CONFIG_ID "0x2C"
    #define RELAY_COUNT     4
    #define RELAY1_PIN      6     // Active LOW relay control pins - adjust as needed for your hardware setup
    #define RELAY2_PIN      7
    #define RELAY3_PIN      10
    #define RELAY4_PIN      11
    #define TOUCH1_PIN      0     // TTP224 touch sensor 1 (channels 1-4) - active HIGH, with external pull-downs to GND. Adjust pin numbers as needed for your hardware setup.
    #define TOUCH2_PIN      1     // TTP224 touch sensor 2
    #define TOUCH3_PIN      2     // TTP224 touch sensor 3
    #define TOUCH4_PIN      3     // TTP224 touch sensor 4
    #define PAIR_BTN_PIN    18    // Pairing button GPIO pin (active-LOW, uses internal pull-up)
    #define LED_PIN         14    // WS2812B data pin
    #define LED_COUNT       1     // Number of WS2812B LEDs on board
    #define TOUCH_DEBOUNCE_MS 35
    bool relay_active_high = false; // Set to true if your relay module is active HIGH, false if active LOW
#endif

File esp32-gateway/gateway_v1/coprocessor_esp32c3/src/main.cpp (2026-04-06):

/**
    * @file [main.cpp]
    * @brief Main source file for the (ESP32-C3) Gateway Coprocessor firmware
    * @version 0.3.1
    * @author Mrinal (@atechofficials)
 */

#define FW_VERSION "0.3.1"

#include <Arduino.h>
#include <WiFi.h>
#include <esp_wifi.h>
#include <WebServer.h>
#include <LittleFS.h>
#include <ArduinoJson.h>
#include <algorithm>
#include <Update.h>
#include <esp_app_format.h>
#include <esp_ota_ops.h>
#include "../../include/coproc_ota_protocol.h"
#include "../../include/mesh_protocol.h"
#include "../../include/user_config.h"

#define UART_BAUD 230400
#define UART_RX_BUFFER_SIZE 4096
#define UART_TX_BUFFER_SIZE 4096
#define OTA_FILE_PATH "/firmware.bin"
#define COPROC_OTA_HWCFG_MARKER "C3HWCFG:"
#define COPROC_OTA_FW_MARKER "C3FWVER:"
#define OTA_AP_IP IPAddress(192, 168, 4, 1)
#define OTA_AP_GW IPAddress(192, 168, 4, 1)
#define OTA_AP_MASK IPAddress(255, 255, 255, 0)
#define FRAME_MAX_PAYLOAD sizeof(CoprocUploadChunkPayload)
#define USB_SERIAL_WAIT_MS 250
#define SELF_OTA_REBOOT_DELAY_MS 400UL

__attribute__((used)) static const char kCoprocFirmwareVersionMarker[] =
    COPROC_OTA_FW_MARKER FW_VERSION;
__attribute__((used)) static const char kCoprocHardwareConfigMarker[] =
    COPROC_OTA_HWCFG_MARKER COPROC_HW_CONFIG_ID;
static volatile uint32_t gCoprocMarkerChecksum = 0;

static HardwareSerial linkUart(1);
static WebServer server(80);

struct HelperState {
    bool     fileReady = false;
    bool     apRunning = false;
    uint32_t sessionId = 0;
    uint32_t imageSize = 0;
    uint32_t imageCrc32 = 0;
    uint32_t runningCrc32 = 0xFFFFFFFFu;
    size_t   written = 0;
    uint8_t  nodeId = 0;
    uint8_t  nodeType = 0;
    uint8_t  apChannel = 6;
    uint16_t port = 80;
    char     version[COPROC_FW_VERSION_LEN] = {0};
    char     ssid[COPROC_SSID_LEN] = {0};
    char     password[COPROC_PASS_LEN] = {0};
    File     file;
} helper;

struct SelfOtaState {
    bool          active = false;
    bool          updateBegun = false;
    bool          rebootPending = false;
    uint32_t      sessionId = 0;
    uint32_t      imageSize = 0;
    uint32_t      imageCrc32 = 0;
    uint32_t      runningCrc32 = 0xFFFFFFFFu;
    size_t        written = 0;
    unsigned long rebootAtMs = 0;
    char          version[COPROC_FW_VERSION_LEN] = {0};
} selfOta;

struct RxState {
    enum State : uint8_t {
        WAIT_MAGIC_1 = 0,
        WAIT_MAGIC_2,
        READ_TYPE,
        READ_LEN_1,
        READ_LEN_2,
        READ_PAYLOAD,
        READ_CRC_1,
        READ_CRC_2,
    } state = WAIT_MAGIC_1;
    uint8_t  type = 0;
    uint16_t length = 0;
    uint16_t expectedCrc = 0;
    uint16_t payloadIndex = 0;
    uint8_t  payload[FRAME_MAX_PAYLOAD] = {0};
} rxState;
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

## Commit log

2026-03-12 feat: initial release of ESPNow Mesh System v1.0
    - ESP32-S3 gateway with WiFiManager, AsyncWebServer, WebSocket dashboard
    - Envo Mini v1 sensor node with ESP-NOW pairing and heartbeat
    - Per-node dynamic settings (temp unit, send interval, LED enable)
    - Schema-on-wire design: nodes self-describe settings to gateway
    - Remote node reboot, rename, disconnect from dashboard
    - Gateway Wi-Fi config and factory reset from dashboard
    - Gateway-loss detection and automatic node re-registration
    - READMEs for all repo directories
    [partitions_8mb_noot.csv]
2026-03-12 feat: add web interface authentication and fix node persistence
    Firmware (main.cpp v1.7.1)
    - Add SHA-256 password hashing with NVS-persisted credentials (gwauth namespace)
    - Add session token and Remember Me token system for stateless HTTP/WS auth
    - Add /api/login, /api/logout, /api/auth_check endpoints with HttpOnly cookie support
    - Add manual Cookie header parsing for ESPAsyncWebServer v3.x compatibility
    - Add WebSocket auth gate: clients must authenticate before receiving any data
    - Add wsBroadcast() to restrict data pushes to authenticated WS clients only
    - Add set_web_credentials WS command with SHA-256 hashing and session invalidation
    - Add NVS node registry persistence (gwnodes namesp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
    [main.cpp]
2026-03-13 feat: schema-driven sensor system + multi-sensor env node (v3.0 protocol)
    BREAKING CHANGE: mesh_protocol.h v3.0 — gateway and all nodes must be
    reflashed together. Old MSG_SENSOR_DATA format is not backward compatible.
    Protocol (mesh_protocol.h v3.0)
    - Replaced hardcoded temperature/pressure fields in MsgSensorData with a
    generic SensorReading[] array (id + value pairs)
    - Added MSG_SENSOR_SCHEMA_GET and MSG_SENSOR_SCHEMA message types
    - Added SensorDef struct (id, precision, label, unit) and MsgSensorSchema
    - Nodes now self-describe their sensors once via schema handshake on pair
    - Gateway and web UI have zero hardcoded sensor knowledge — fully dynamic
    Gateway Firmware (main.cpp v1.8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
    [main.cpp, mesh_protocol.h]
2026-03-13 feat(web-ui): improve ESP32-S3 Gateway Web Interface structure and asset handling
    - Major Improvements:
    * Fonts are now served locally from device flash instead of being fetched from external CDN sources.
    * Improves reliability in offline environments.
    * Reduces external dependencies.
    * Ensures consistent UI rendering without network latency.
    * Replaced inline SVG icons with dedicated external SVG icon files.
    * Simplifies HTML structure and improves readability.
    * Makes icon management and reuse easier across the interface.
    * Reduces clutter inside HTML and JS templates.
    - UI Architecture Improvements:
    * Implemented a scalable CSS mask-based icon system using `currentColor`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
2026-03-14 feat: Added ESP32-S3 Gateway ARGB status LED control
    Features:
    - Added toggle in Web Interface Settings page to enable/disable gateway ARGB LED
    - Implemented WebSocket command for LED control
    - Added gw_led_enabled field to meta JSON for UI synchronization
    - Persist LED state in NVS so it survives gateway reboot
    - UI toggle now reflects actual gateway state on page load
    Improvements:
    - Dashboard state now remains consistent after reconnect or refresh
    - LED control integrated into existing settings architecture
    [main.cpp]
2026-03-15 feat: add actuator node support, relay firmware, and mesh/dashboard updates
    - add ESP32 actuator node support across gateway, protocol, and web interface
    - add actuator message definitions and bump mesh_protocol.h to v3.1.0
    - add NODE_HYBRID for future hybrid sensor-actuator nodes
    - update gateway firmware and bump main.cpp to v1.8.2
    - update dashboard logic and bump app.js to v3.6
    - add ESP32 relay actuator node firmware and bump to v1.0.1
    - add relay state persistence and status LED node settings
    - fix actuator state sync after reboot and reconnect
    - fix relay UI state handling in the dashboard
    - fix all-relay persistence restore behavior
    - update project documentation, changelogs, and con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
    [main.cpp, mesh_protocol.h]
2026-03-17 feat: Relay Label Support - Added per relay label set functionality via Web Interface for ESP32 Actuator Nodes. - Relay Label set/assignment is completely handled by the Web Interface and the Gateway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
2026-03-17 feat(relay-node): add TTP224 touch control for relays with gateway state sync
2026-03-18 feat(gateway): add web-based OTA firmware update system
    - add Gateway OTA firmware upload flow in the web interface
    - add real-time OTA upload progress, status, and error reporting
    - add backend OTA validation for firmware image type, size, and project match
    - add automatic reboot into updated firmware after successful flash
    - add OTA-capable 8MB partition layout for ESP32-S3 Gateway
    - update OTA UI assets and settings page integration
    Version bumps:
    - Gateway firmware: v1.8.3 -> v1.9.0
    - app.js: v3.7 -> v3.8
    - index.html: v3.5 -> v3.6
    - style.css: v3.4 -> v3.5
    [partitions_8mb_ota.csv]
2026-03-20 feat(ota): add gateway-managed node OTA with ESP32-C3 coprocessor support
    - bump ESP32-S3 gateway firmware from v1.9.0 to v2.0.0
    - introduce ESP32-C3 gateway coprocessor firmware v0.1.0
    - add coproc_ota_protocol.h v1.0.0
    - bump mesh_protocol.h from v3.1.0 to v3.2.0
    - bump web interface app.js from v3.8 to v3.9
    - bump web interface index.html from v3.6 to v3.7
    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
    [partitions_4mb_ota.csv]
2026-03-20 feat(ota): add hardware config ID validation for gateway and node OTA updates
    - add OTA hardware configuration ID precheck to prevent flashing firmware built
    for incompatible hardware revisions
    - extend node OTA validation to require both node role match and hardware config
    ID match before starting OTA
    - extend gateway OTA validation to require gateway hardware config ID match
    before flashing
    - add firmware marker parsing for:
    - GWHWCFG:<id> in gateway firmware images
    - NODEHWCFG:<id> in node firmware images
    - embed hardware config ID markers into gateway, sensor node, and relay node
    firmware binaries
    - make nodes report their HW_CONFIG_ID to the gateway during registration and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
    [main.cpp, mesh_protocol.h]
2026-03-21 feat(hybrid): add RFID-enabled Hybrid node support across gateway, UI, and OTA
    - bump ESP32-S3 gateway firmware from v2.0.1 to v2.1.0
    - bump ESP32-C3 gateway coprocessor firmware from v0.1.0 to v0.1.1
    - bump mesh_protocol.h from v3.2.1 to v3.3.0
    - bump ESP32 sensor node firmware from v2.1.1 to v2.1.2
    - bump ESP32 relay node firmware from v1.1.1 to v1.2.0
    - bump app.js from v4.0 to v4.1
    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
    [partitions_4mb_ota.csv]
2026-03-21 feat(ui): polish mobile dashboard UX, RFID toasts, and gateway dialogs
    - bump index.html from v3.7 to v3.8
    - bump app.js from v4.1 to v4.2
    - bump style.css from v3.6 to v3.7
    - bump ESP32-S3 gateway firmware main.cpp from v2.1.0 to v2.1.1
    - add RFID scan toasts for new-card detection and known-card actions
    - improve mobile top bar layout and keep IP/MAC/Ch/Up/Nodes labels visible
    - move Reboot GW and Factory Reset actions into the mobile side menu
    - improve mobile side nav behavior with full-width landscape layout, working close button, and better footer spacing
    - fix mobile sidebar and popup background scroll locking
    - replace Reboot GW browser confirm with the custom in-app popup used by F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
    [main.cpp]
2026-03-22 feat(hw): add Gateway v1.0A PCB files and update hardware support
    - bump ESP32-S3 gateway firmware main.cpp from v2.1.1 to v2.1.2
    - bump ESP32 Hybrid Relay Node firmware main.cpp from v0.1.0 to v0.1.1
    - add hardware release files for ESP32 Mesh System Gateway v1.0A under gateway_v1/hardware
    - include KiCad project files, schematic PDFs, and Development_Resources with dev-board pinouts and MCU datasheets
    - add the first gateway PCB as a single-layer, thick-trace, THT-friendly design based on off-the-shelf ESP32-S3 Super Mini and ESP32-C3 Super Mini boards for easy home fabrication
    - update ESP32-S3 <-> ESP32-C3 helper UART routing for the new gateway PCB layout:
    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
    [ESP32_Mesh_Gateway_v1A.kicad_pcb, ESP32_Mesh_Gateway_v1A.kicad_sch]
2026-03-23 feat(pairing): add max-node warning flow and restore node LED status after unpair
    - bump ESP32-S3 gateway firmware main.cpp from v2.1.2 to v2.1.3
    - bump ESP32 sensor node firmware main.cpp from v2.1.2 to v2.1.3
    - bump ESP32 actuator relay node firmware main.cpp from v1.2.0 to v1.2.1
    - bump ESP32 hybrid relay node firmware main.cpp from v0.1.1 to v0.1.2
    - bump app.js from v4.2 to v4.3
    - add a gateway-side max-node-capacity check for pair requests
    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
2026-03-25 feat(protocol): expand node names to 24 chars and add MAC-suffixed defaults
    - bump ESP32-S3 gateway firmware from v2.1.3 to v2.1.4
    - bump ESP32 sensor node firmware from v2.1.3 to v2.1.4
    - bump ESP32 actuator relay node firmware from v1.2.1 to v1.2.2
    - bump ESP32 hybrid relay node firmware from v0.1.2 to v0.1.3
    - bump mesh_protocol.h from v3.3.0 to v3.3.1
    - increase the shared node-name limit from 15 to 24 visible characters
    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
2026-04-03 feat: improve node discovery, add new gateway PCB variants, and document C3 Super Mini RF fixes
    - polish gateway and node discovery behavior so pairing candidates appear faster and stale "available to pair" entries clear more predictably
    - document the new Gateway v1A-v1D single-layer THT PCB variants for these board combinations:
    - v1A: Seeed Studio XIAO ESP32-S3 + ESP32-C3 Super Mini
    - v1B: Seeed Studio XIAO ESP32-S3 + Seeed Studio XIAO ESP32-C3
    - v1C: Seeed Studio XIAO ESP32-S3 + DFRobot Beetle ESP32-C3
    - v1D: Waveshare ESP32-S3-DevKit-C-N8R8 + ESP32-C3 Super Mini
    - note that all new gateway PCB variants include connection points for a future BME280 module
    - deprecate the earlier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
    [ESP32_Mesh_Gateway_v1A.kicad_pcb, ESP32_Mesh_Gateway_v1A.kicad_sch, ESP32_Mesh_Gateway_v1B.kicad_pcb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]
2026-04-03 feat: add coprocessor web OTA, board-aware validation, and explicit gateway build targets
    - add ESP32-C3 coprocessor OTA firmware update support through the Gateway web interface
    - update the Gateway Firmware Update UI to let users choose the target MCU:
    - Main MCU
    - Coprocessor
    - keep the existing ESP32-S3 main MCU OTA flow intact while adding a dedicated coprocessor OTA path
    - implement UART-based firmware transfer from the ESP32-S3 gateway MCU to the ESP32-C3 coprocessor
    - add coprocessor OTA session handling for:
    - prepare / ready handshake
    - staged firmware transfer
    - flash start / completion reporting
    - reboot and reconnect detection
    - progress and error reporting back to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
    [main.cpp, user_config.h]
2026-04-04 feat: harden gateway OTA coordination between node OTA and coprocessor OTA
    - add mutual-exclusion handling between node OTA and coprocessor OTA flows so both cannot use the ESP32-C3 helper at the same time
    - reject coprocessor firmware update attempts while the coprocessor is busy serving as the node OTA helper AP
    - reject node OTA attempts while the coprocessor is busy with a coprocessor firmware update
    - surface the shared busy message "Coprocessor Busy. Please try after some time." in the web interface
    - disable node OTA controls while the coprocessor is reserved and show helper status as Busy
    - extend gateway firmware update UI handling so the busy state is reflected for both MCU targets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
2026-04-05 feat: add gateway offline mode, router failover recovery, and physical reset UX
    - add Gateway Offline Mode hosted on the ESP32-S3 so the dashboard remains reachable without a home router
    - add a dedicated offline AP configuration with separate SSID/password defaults and NVS persistence
    - extend the WiFiManager setup portal with:
    - manual offline mode selection
    - offline AP SSID field
    - offline AP password field
    - add gateway network-mode handling for:
    - setup portal
    - online router STA mode
    - offline AP mode
    - persist router WiFi credentials in gateway config storage for reliable reconnect and failover behavior
    - make the gateway connect directly to saved router credentials on no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
    [main.cpp, user_config.h]
2026-04-06 fix: gracefully unpair connected nodes before gateway factory reset
    - update the ESP32-S3 gateway factory reset flow so connected nodes are explicitly disconnected before the gateway wipes its own state
    - send `MSG_UNPAIR_CMD` to every currently paired node when factory reset is triggered from:
    - the dashboard Factory Reset action
    - the physical factory reset button
    - give nodes time to receive the unpair command before the gateway clears local pairing state and reboots
    - clear the gateway runtime node registry only after the unpair notifications have been sent
    - prevent previously paired nodes from interpreting gateway factory reset like a temporary gateway reboot
    - ensure nodes return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
    [main.cpp]
2026-04-06 feat: add gateway built-in sensor support and improve Super Mini OTA helper stability
    - add optional gateway built-in room environment sensor support on the ESP32-S3 gateway
    - support compile-time selection of:
    - no built-in sensor
    - BMP280
    - BME280
    - expose built-in sensor data through the gateway dashboard as a dedicated `Gateway Built-in Sensor` card
    - keep the built-in sensor separate from paired-node handling, Connected Nodes, and node-specific controls
    - show temperature and sea-level-corrected pressure for built-in BMP280/BME280 sensors
    - show humidity only when the selected built-in sensor type is BME280
    - keep the built-in sensor visible in the UI with `Sensor not detected` st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
    [main.cpp, user_config.h]
2026-04-08 feat: add MQTT + Home Assistant discovery across gateway mesh
    - add MQTT bridge support to the gateway firmware and web UI
    - publish Home Assistant MQTT auto-discovery for the gateway,
    built-in sensor, and paired sensor/relay/hybrid nodes
    - route relay, setting, reboot, unpair, and gateway control actions
    through MQTT while keeping Home Assistant and the gateway dashboard
    state in sync
    - expose gateway reboot and factory reset buttons in Home Assistant
    - clear retained MQTT discovery/state during gateway factory reset so
    the gateway and connected nodes disappear cleanly from Home Assistant
    - fix hybrid relay and actuator relay ESP-NOW heartbeat/liveness logic
    for more stable links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
    [main.cpp, user_config.h]
2026-04-12 feat(gateway): auto-detect built-in BMP280/BME280 sensor and simplify config
    - add clearer built-in sensor probe and diagnosis logs for gateway SPI sensor detection
    - auto-detect whether the connected built-in sensor is BMP280 or BME280 at runtime
    and publish/show the correct sensor model and readings accordingly
    - remove the old manual gateway built-in sensor type selection logic from firmware
    and replace it with a simple built-in sensor enable flag
    - align gateway dashboard sensor UI with runtime sensor auto-detection
    - gateway main firmware: v2.6.4 -> v2.6.7
    - gateway user_config.h: v1.1.2 -> v1.1.3
    - gateway app.js: v4.8.0 -> v4.8.1
    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
    [main.cpp, user_config.h]
